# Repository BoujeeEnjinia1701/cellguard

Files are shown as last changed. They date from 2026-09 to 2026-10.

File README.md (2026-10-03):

# CellGuard

     

**Area:** Shared Components · **TRL:** 3 of 9 (proof of concept on paper) · **Value-engineering target:** about $140 USD (a hypothetical control target, not a limit) · **Difficulty:** 4 of 5

An open battery management board for small LiFePO4 packs (4 to 16 cells) with cell balancing, protection and a documented state-of-charge estimate, reusable across the lab's vehicles, storage and field kits.

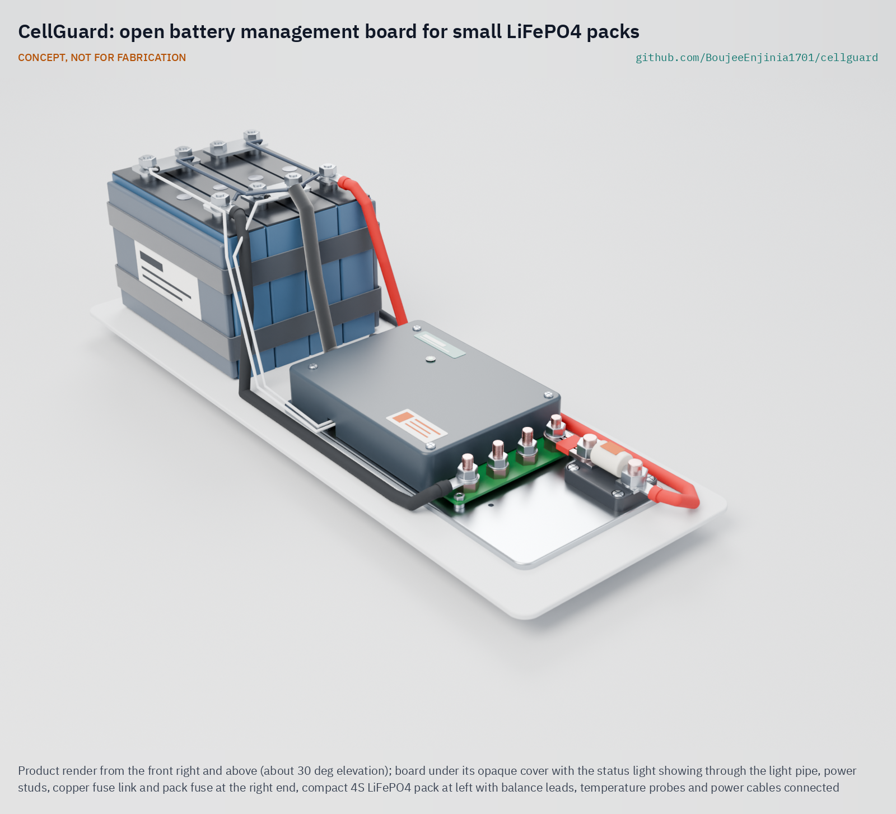
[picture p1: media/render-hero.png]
CellGuard: open battery management board for small LiFePO4 packs, product render


[Exploded render](media/render-exploded.png) · [Detail render](media/render-detail.png) · [Interactive 3D model](media/viewer.html) · [Concept blueprint (PDF)](media/concept-blueprint.pdf) · [General arrangement CGD-DWG-001 (PDF)](cad/drawings/CGD-DWG-001.pdf) · [Sizing calculations](docs/04-calcs/01-sizing.md) · [Prototype build plan](docs/05-build-plan.md) · [Design decisions](docs/06-design-decisions.md) · [Review note](docs/REVIEW.md)

## Concept rationale

A single, openly documented BMS removes the riskiest unknown from every battery project in the lab and gives SwapCell, PowerBox, SunSpoke and MotionCore a common safety layer. The concept puts protection in one proven cell-monitor chip that trips the pack's switches on its own, backs it with an independent secondary protector, and keeps the microcontroller for the parts that users need to read and check: the state-of-charge estimate, the event log and the CAN interface. Switches, sensing, precharge and the pack fuse sit on one aluminium plate, so the whole protection path can be built and tested as one part.

It is open and garage-buildable because the value of a BMS lies in knowing exactly what it does. Every threshold sits in a plain configuration file, the firmware and state-of-charge method are published, and the parts can be soldered with a hot plate or hot-air station. A repairer can read a fault log instead of scrapping a pack, and a builder can test the board on a bench before trusting it with cells.

## Burning platform

Lithium battery fires in light vehicles and homes are rising, and the battery management system is the main barrier between a cell fault and a fire. In the United States, the Consumer Product Safety Commission counts 227 micromobility battery incidents from 2019 to 2023, associated with 39 deaths and 181 injuries, and in 2026 proposed a mandatory safety standard in which BMS protections are central ([Federal Register, 24 June 2026](https://www.federalregister.gov/documents/2026/06/24/2026-12749/safety-standard-for-lithium-ion-batteries-used-in-micromobility-products-and-electrical-systems-of)). New York City alone recorded 268 lithium-ion battery fires and 18 deaths in 2023 ([FDNY](https://www.nyc.gov/site/fdny/news/03-25/fdny-commissioner-robert-s-tucker-significant-progress-the-battle-against-lithium-ion)), and London Fire Brigade attended a record 206 e-bike and e-scooter fires in 2025 ([London Fire Brigade](https://www.london-fire.gov.uk/news/2026-news/january/record-number-of-e-bike-and-e-scooter-fires-across-london-in-2025-as-brigade-calls-for-regulation-to-be-introdu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)).

At the same time, more people depend on small lithium packs for basic power: solar home systems made up more than a third of new electricity connections in sub-Saharan Africa in 2023 ([IEA](https://www.iea.org/commentaries/electricity-access-continues-to-improve-in-2024-after-first-global-setback-in-decades)). Builders and repairers of these packs cannot inspect or fix closed battery management boards, so faults stay hidden until a pack fails.

## Where it could be used

### By industry

| Industry | Use |
| --- | --- |
| Light electric vehicles | Protection and state of charge for e-bike, cargo trike and scooter packs, including the lab's SwapCell and SunSpoke |
| Off-grid and backup power | 12, 24 and 48 V LFP banks for solar home systems, shops and clinics, and portable stations such as PowerBox |
| Telecom and remote monitoring | Battery backup for small towers, gateways and monitoring stations |
| Marine and recreational vehicles | LFP house batteries replacing lead-acid in boats, vans and caravans |
| Light robotics and agriculture | Packs for field robots, carts and automated guided vehicles built on MotionCore |
| Education and repair | Teaching battery safety in vocational courses; diagnosing packs in repair shops and repair cafés |

### By country or region

| Country or region | Why it matters there |
| --- | --- |
| United Kingdom | London had a record 206 e-bike and e-scooter fires in 2025, and the fire brigade is calling for regulation ([London Fire Brigade](https://www.london-fire.gov.uk/news/2026-news/january/record-number-of-e-bike-and-e-scooter-fires-across-london-in-2025-as-brigade-calls-for-regulation-to-be-introdu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)) |
| United States | 268 lithium-ion battery fires and 18 deaths in New York City in 2023 ([FDNY](https://www.nyc.gov/site/fdny/news/03-25/fdny-commissioner-robert-s-tucker-significant-progress-the-battle-against-lithium-ion)); a federal micromobility battery standard is proposed ([Federal Register](https://www.federalregister.gov/documents/2026/06/24/2026-12749/safety-standard-for-lithium-ion-batteries-used-in-micromobility-products-and-electrical-systems-of)) |
| European Union | Since 18 August 2024, batteries for light vehicles, stationary storage and electric vehicles must hold state-of-health data in their BMS ([Regulation (EU) 2023/1542](https://eur-lex.europa.eu/eli/reg/2023/1542/oj/eng)) |
| Australia | Fire and Rescue NSW recorded 272 lithium-ion battery fires and 38 injuries in 2023 ([FRNSW](https://www.fire.nsw.gov.au/media/news/2024/20240315-fire-and-rescue-nsw-recording-lithium-ion-battery-fires-at-a-rate-of-five-a-week)) |
| India | Fires in electric two-wheelers led to added battery safety requirements, including the BMS, from 1 October 2022 ([Press Information Bureau](https://www.pib.gov.in/PressReleaseIframePage.aspx?PRID=1856114&reg=3&lang=2)); many small workshops assemble and repair packs |
| Sub-Saharan Africa | About 600 million people lacked electricity in 2023, and solar home systems made up more than a third of new connections ([IEA](https://www.iea.org/commentaries/electricity-access-continues-to-improve-in-2024-after-first-global-setback-in-decades)); local technicians need BMS boards they can repair |

## What sparked the idea

The starting point was the self-balancing scooter, or hoverboard, recall of July 2016. The US Consumer Product Safety Commission and ten firms recalled about 501,000 units because their lithium-ion battery packs could overheat, smoke, catch fire or explode, after at least 99 reported incidents that included burn injuries and property damage ([CPSC recall notice, 6 July 2016](https://www.cpsc.gov/Recalls/2016/Self-Balancing-Scooters-Hoverboards-Recalled-by-10-Firms)). The recall spanned products from ten firms, and nothing published let a buyer or repairer see what limits a pack's protection electronics enforced or how they would fail. CellGuard takes the opposite position for the small LFP packs that builders assemble themselves: publish every threshold, the failure analysis and the state-of-charge method, and back the main protection with an independent second layer, so that the protection can be checked before a pack is trusted rather than after it fails.

## Problem

Small builders either buy closed battery management boards with unknown firmware and limits, or skip protection altogether. Both lead to damaged packs and fires, and neither teaches anything.

Full problem statement: [docs/01-problem.md](docs/01-problem.md)

## Concept

An open battery management board for small LiFePO4 packs (4 to 16 cells) with cell balancing, protection and a documented state-of-charge estimate, reusable across the lab's vehicles, storage and field kits.

A single cell-monitor and protection chip measures every cell and opens the charge or discharge MOSFETs on its own when a limit is crossed; an independent secondary protector blows a protector fuse if that layer fails. A microcontroller adds a state-of-charge estimate anchored at full and empty, a state-of-health event log and an open CAN and UART interface carrying the SwapCell message set. Calculated at TRL 3 (CGD-CAL-001 v0.6): 40 A continuous with MOSFET junctions near 51 °C at 40 °C ambient, 3.5 W board loss at 40 A with 1.5 mΩ-class switches (against a 4 W target), 100 mA passive balancing, about 55 µA sleep current, 220 x 110 x 33 mm and about 0.66 kg (against 0.7 kg). The state-of-charge error stays within 10 points on a 20 Ah pack because the firmware prompts for a full charge when about five days pass without one, provided the coulomb counter offset is calibrated. A three-colour status light shows through a light pipe in the opaque printed cover. Value-engineering target: USD 140. Estimated cost of the constructable design: USD 159.15 (USD 19.15 over the target), mainly the lower-resistance switches.

Full design precis: [docs/02-concept.md](docs/02-concept.md) · Requirements: [docs/03-requirements.md](docs/03-requirements.md)

## Key components

- Cell monitor and protection IC for 3 to 16 cells, with passive balancing (TI BQ76952 class)
- Independent secondary protector (TI BQ77216 class) with a self-control protector fuse
- Charge and discharge MOSFET switches: 8 x 100 V, high side, top-side cooled, on an aluminium heat spreader
- 0.25 mΩ current shunt
- Temperature sensors, 3 points
- Microcontroller with CAN and UART (STM32G0B1 class)
- Fuse and precharge circuit
- Enclosure and harness

The component choices were decided by Amish on 2026-09-25 ([CGD-DDR-001](docs/decisions/0001-trl2-review-decisions.md), [CGD-DDR-002](docs/decisions/0002-recommendations-accepted.md)). The priced bill of materials is in [bom/bom.csv](bom/bom.csv): value-engineering target USD 140; estimated cost of the constructable design USD 159.15 (USD 19.15 over the target).

## Building the prototype

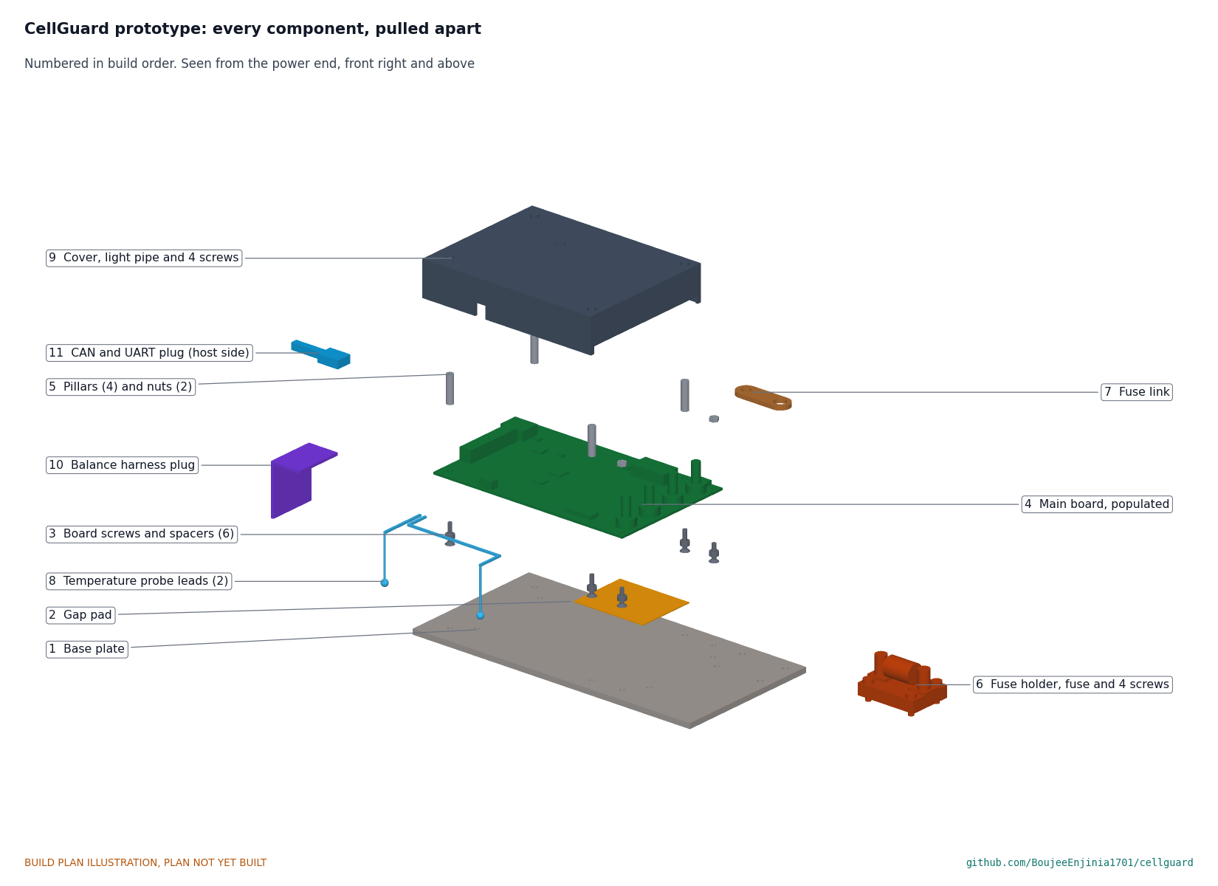
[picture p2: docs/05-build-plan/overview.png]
Every component of the prototype, pulled apart and numbered in build order


The [prototype build plan](docs/05-build-plan.md) (CGD-BLD-001) shows, in pictures drawn from the model, how each of the 11 components is made and how it fits the next: a drilled and tapped aluminium plate, a cut gap pad, a populated four-layer board on six spacers, a bolted fuse holder joined to the B+ stud by a straight copper link, and a printed opaque cover on four pillars with a light pipe over the status light. Making the design buildable changed some concept details, such as the board fixings, the cover notches and the fuse position; each change is recorded in [CGD-DDR-003](docs/decisions/0003-design-for-construction.md). It is a plan, not yet built: first power-up is always on a cell simulator. Decisions are kept in the [design decisions register](docs/06-design-decisions.md).

## Safety

> Lithium cells can overheat, vent and burn, and a large pack can deliver thousands of amperes into a short circuit. Use LFP cells, fit a DC-rated pack fuse sized for the pack, charge only within the cell maker's limits and never leave a first build charging unattended. A 16S pack of large cells can drive about 5 kA into a short (CGD-CAL-001), so the pack fuse needs a 10 kA DC breaking capacity. Test every new board and every threshold change on a cell simulator or current-limited bench supply before connecting cells. CellGuard is a research and prototype design; it is not certified.

## Repository layout

| Folder | Contents |
| --- | --- |
| `docs/` | Problem, concept, requirements, calculations and design decisions |
| `cad/src/` | build123d Python source, the source of truth for all geometry |
| `cad/step/`, `cad/stl/` | Exported models for FreeCAD, other CAD tools and printing |
| `cad/drawings/` | 2D sketches and dimensioned drawings |
| `bom/` | Bill of materials |
| `electronics/` | KiCad schematics and PCB layouts |
| `firmware/` | Microcontroller code |
| `media/` | Renders, perspectives and photos |
| `build-log/` | Dated prototyping notes |

## Documentation

Controlled documents follow the portfolio [documentation standard](.kit/STANDARDS.md). Each carries a document ID (CGD-PRC-001 for the precis), a version and a revision history. Branded PDFs are built with `python .kit/render.py` and attached to GitHub Releases when a document is tagged, for example `CGD-PRC-001/v1.0`.

## Credits

Designed by Amish Chadha. See [CONTRIBUTORS.md](CONTRIBUTORS.md) for roles. To cite this design, use [CITATION.cff](CITATION.cff) (GitHub shows it as "Cite this repository").

AI assistance (Claude) was used to accelerate concept renders, prototype documentation and first-pass sizing calculations. Design direction and all decisions are Amish Chadha's, recorded in this repository's decision records (`docs/decisions/`).

## Licenses

- **Hardware** (CAD, drawings, BOM, electronics): [CERN-OHL-S v2](LICENSE)
- **Software** (firmware, scripts, notebooks): [MIT](LICENSE-SOFTWARE). Any code reused from the Apache-2.0 Libre Solar BMS firmware will keep its own license and notices in `firmware/third_party/` and be listed in `LICENSE-SOFTWARE`.

A project of the [Design Molecule](https://designmolecule.com) lab.

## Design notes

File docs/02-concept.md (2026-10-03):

---
doc_id: CGD-PRC-001
title: CellGuard design precis
project: CellGuard
doc_type: Design precis
version: "0.8"
status: Draft
date: '2026-10-02'
author: Amish Chadha
license: CERN-OHL-S-2.0
revisions:
- version: "0.1"
  date: '2026-09-25'
  author: Amish Chadha
  change: Initial scaffold
- version: "0.2"
  date: '2026-09-25'
  author: Amish Chadha
  change: Populate to TRL 2 (architecture, first-order numbers, safety, media)
- version: "0.3"
  date: '2026-09-25'
  author: Amish Chadha
  change: TRL 3. Record design choices adopted for TRL 3 under Amish's 2026-09-25 instruction, open for his review (CGD-DDR-001); add the secondary protector; numbers replaced by CGD-CAL-001; media from the parametric model
- version: "0.4"
  date: '2026-09-25'
  author: Amish Chadha
  change: Recommendations accepted by Amish (DDR-002)
- version: "0.5"
  date: '2026-09-30'
  author: Amish Chadha
  change: Design for construction (CGD-DDR-003); figures follow CGD-CAL-001 v0.3; base plate, fuse holder and cover fixings made buildable; GA Rev P2
- version: "0.6"
  date: '2026-10-01'
  author: Amish Chadha
  change: Budget treated as a value-engineering target; cost wording only, no number changed
- version: "0.7"
  date: '2026-10-02'
  author: Amish Chadha
  change: "Responses to R6, R8 and R14, cover, status light, state-of-charge check and first test partner as decided on 2026-10-02 (CGD-DEC-001)"
- version: "0.8"
  date: '2026-10-02'
  author: Amish Chadha
  change: "Key numbers from CGD-CAL-001 v0.6 (1.5 mOhm-class switches, five-day state-of-charge error); status light and light pipe in the components table; cost USD 159.15 against the USD 140 value-engineering target"
---

# CellGuard design precis

## Summary

CellGuard is one open battery management board for LFP packs of 4 to 16 cells in series. A single cell-monitor and protection chip measures every cell, trips the pack's MOSFET switches on its own when a limit is crossed, and balances the cells; a small microcontroller adds the state-of-charge estimate, a state-of-health log and an open CAN and UART interface. An independent secondary protector blows a self-control protector (SCP) fuse if the main protection fails. Everything sits on an aluminium base plate that spreads heat and also carries the pack fuse, so the whole protection path is one part that other lab projects can bolt on. The TRL 3 calculations (CGD-CAL-001 v0.6) show 12 of 16 requirements met on paper after the responses Amish decided on 2026-10-02: board loss 3.5 W against 4 W with 1.5 mΩ-class switches (R6), state of charge within 10 points between full charges prompted about every five days (R8, with calibration) and mass 0.66 kg against the relaxed 0.7 kg (R14). R2, R4 and R7 are at risk. Value-engineering target: USD 140. Estimated cost of the constructable design: USD 159.15 (USD 19.15 over the target), mainly the dearer switches (R16).

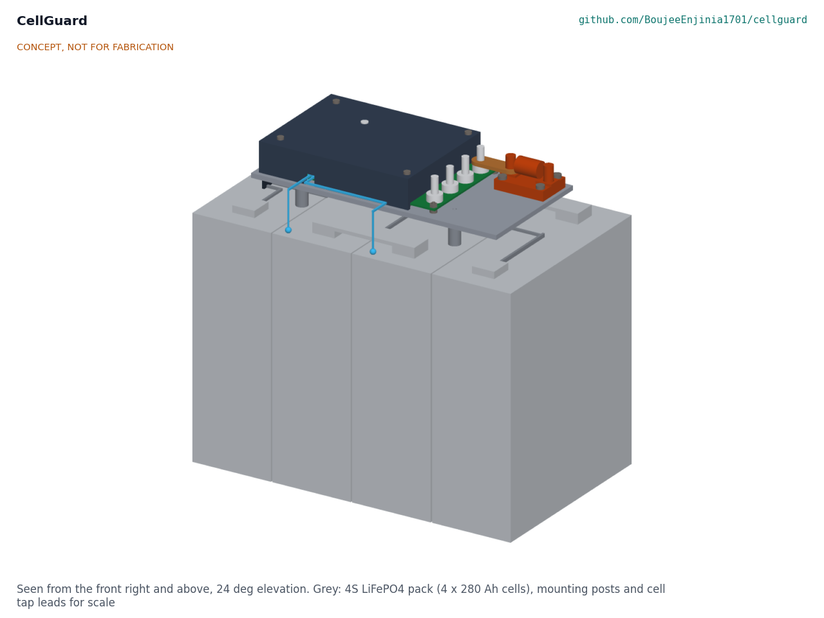
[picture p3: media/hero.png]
CellGuard on a 4S LFP pack


*Figure 1. CellGuard on four posts above a 4S LFP pack of 280 Ah prismatic cells, shown for scale. Generated from `cad/src/model.py`. Concept, not for fabrication.*

## How it works

1. **Measure.** The front end (BOM 3) reads every cell voltage through the balance harness (10), pack current through a 0.25 mΩ shunt (5) and three temperatures (11): two cell probes and one thermistor beside the MOSFETs.
2. **Protect.** The front end compares each reading with thresholds loaded from the configuration file at startup. If a cell goes above 3.65 V it opens the charge MOSFETs; below 2.50 V it opens the discharge MOSFETs; on overcurrent, short circuit or temperature faults it opens both (4). This happens in the front end's own hardware, so a firmware crash in the microcontroller does not stop protection. A separate secondary protector (14) watches every cell as well and, if the front end or a MOSFET fails, blows the SCP fuse in the B+ path.
3. **Balance.** When the pack is near full and cells differ by more than a set amount (default 10 mV), the front end bleeds up to 100 mA from the higher cells through external balance resistors.
4. **Connect safely.** The discharge path stays off until the host pulls the enable line. The precharge switch and resistor (7) first charge the host's input capacitors, then the main discharge MOSFETs close. The pack fuse (8) is the last line of defense against a short circuit that the MOSFETs cannot clear.
5. **Estimate and report.** The microcontroller (6) counts charge in and out, corrects the count at full charge and near empty, logs every charge and discharge event to flash and publishes status on CAN and UART (12).

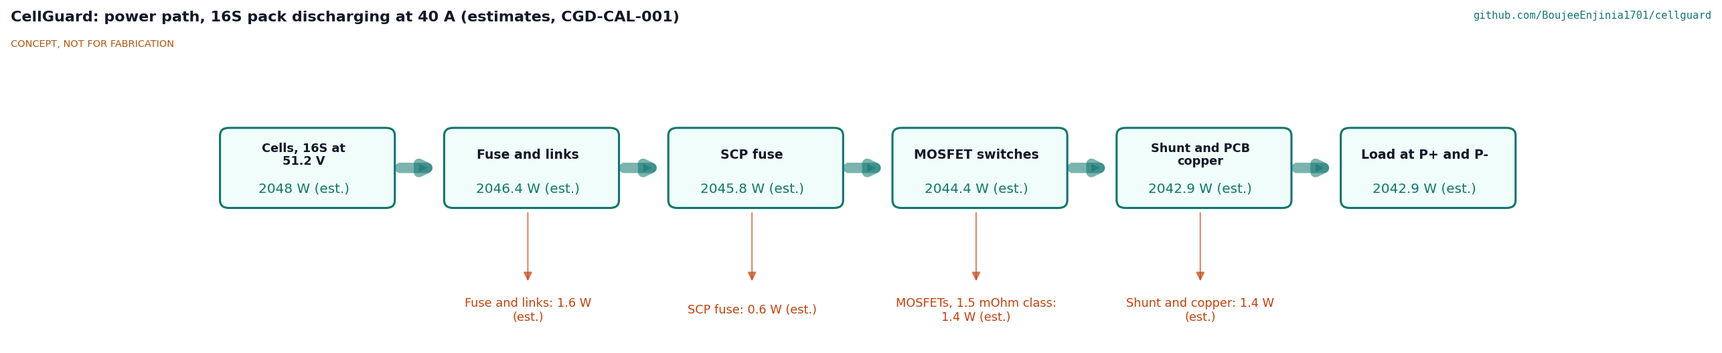
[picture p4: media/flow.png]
Power path and losses


*Figure 2. Power path for a 16S pack discharging at 40 A. All values are estimates from CGD-CAL-001.*

## Main components

Table 1. Main components. Numbers match the exploded view (Figure 3) and `bom/bom.csv`.

| BOM | Component | Concept choice | Notes |
| --- | --- | --- | --- |
| 1 | Base plate and heat spreader | 6061 aluminium, 220 x 110 x 4 mm, flat, drilled and tapped; the board sits on six bought 3 mm spacers (CGD-DDR-003) | Takes MOSFET heat through a gap pad; carries the fuse |
| 2 | Main PCB | 4-layer, 2 oz (70 µm) copper, 150 x 95 mm | Power copper on inner layers; clearances for 60 V |
| 3 | Cell monitor and protection IC | TI [BQ76952](https://www.ti.com/product/BQ76952): 3 to 16 cells, ±15 mV total cell voltage error from −40 to 85 °C, integrated high-side N-channel MOSFET driver, coulomb counter, I²C | Decided by Amish, 2026-09-25 (CGD-DDR-001 item 1, CGD-DDR-002) |
| 4 | Charge and discharge MOSFETs | 8 x 100 V N-channel, 1.5 mΩ class (decided 2026-10-02, CGD-DEC-001), top-side cooled (TOLT) package (decided, CGD-DDR-002): 4 in parallel for charge, 4 for discharge, back to back | Mounted on the PCB underside, pressed onto the base plate through an insulating pad |
| 5 | Current shunt | 0.25 mΩ metal element, 3 W, low side between B- and P- | 10 mV at 40 A |
| 6 | Microcontroller and CAN transceiver | STM32G0B1 class with built-in CAN controller, plus a 3.3 V CAN transceiver | Runs state of charge, log and interface; not in the protection path. Decided by Amish, 2026-09-25 (item 2) |
| 7 | Precharge | 100 Ω 10 W aluminium-housed resistor with a DPAK-class P-channel MOSFET, driven by the front end's precharge output | 1 s timeout in firmware; DPAK-class switch sized for a 34 W peak (decided, CGD-DDR-002) |
| 8 | Pack fuse and holder | 60 A, DC rated 80 V or more, breaking capacity 10 kA or more | In the B+ lead, bolted to the base plate |
| 9 | Power terminals | Four M6 studs: B+, B-, P+, P- | Pack side (B) and load or charger side (P) |
| 10 | Balance connector and harness | 17-way connector, 16 sense leads plus B- reference, each lead fused or resistor-protected at the cell end | Unused inputs linked on the board for packs under 16S |
| 11 | Temperature sensors | Three 10 kΩ NTC thermistors: two ring-lug probes on cells, one on the board by the MOSFETs | Charge locked out below 0 °C |
| 12 | CAN and UART connector | Latching 6-way connector: CAN-H, CAN-L, UART TX and RX, enable, ground | Enable keeps the output off until the host is connected |
| 13 | Cover | Flame-retardant polycarbonate (UL 94 V-0 grade), printed, opaque (decided 2026-10-02) | Leaves the studs and fuse reachable; a light pipe (line 19) shows the status light |
| 14 | Secondary protector and SCP fuse | TI [BQ77216](https://www.ti.com/product/BQ77216) class: 3 to 16 cells, overvoltage, undervoltage, open wire and temperature, separate COUT and DOUT outputs, about 1 µA; drives a self-control protector fuse in the B+ path | Decided by Amish, 2026-09-25 (item 3); SCP rating at 40 A and 60 V to be confirmed |
| 15 | Supporting electronics | 60 V input buck regulator, 16 Mbit SPI flash, TVS diode across P+ and P-, balance resistors, passives, and one three-colour status light (decided 2026-10-02) | Only the status light is shown in the model |
| 19 | Light pipe | Round flanged light pipe, 3 mm, pressed into the cover top over the status light (decided 2026-10-02) | Lets the opaque cover show the status light |

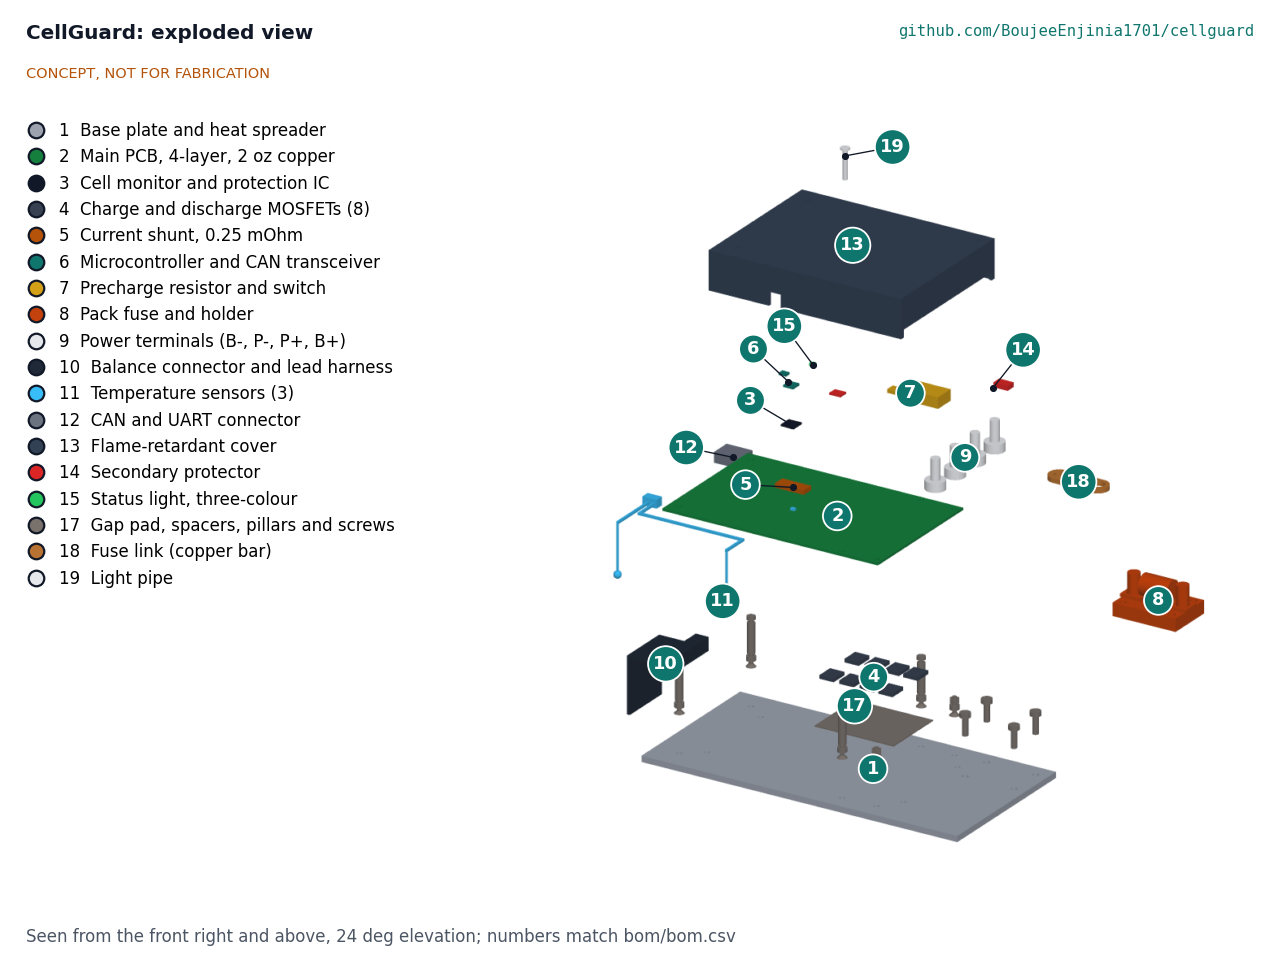
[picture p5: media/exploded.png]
Exploded view


*Figure 3. Exploded view with BOM numbers.*

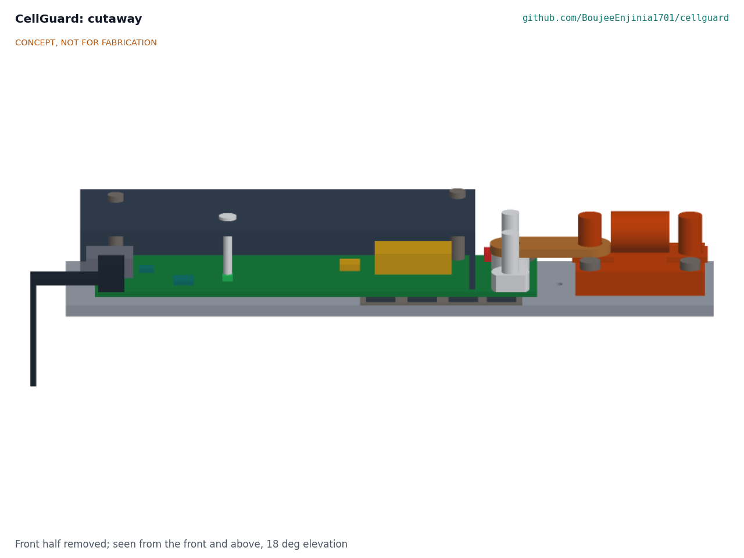
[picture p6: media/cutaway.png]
Cutaway


*Figure 4. Section through the board: MOSFETs (4) under the PCB on the base plate (1), precharge resistor (7), studs (9) and fuse (8), all under or beside the cover (13).*

The general arrangement is drawing CGD-DWG-001 Rev P2 (`cad/drawings/CGD-DWG-001.pdf`), and the STEP files are in `cad/step/`.

## Key design choices

The choices below were recommended at TRL 2 and are decided by Amish, 2026-09-25: go with recommendation (CGD-DDR-001 as updated, CGD-DDR-002). This includes the licensing rule in choice 3 and the protection settings, top-side cooled MOSFETs, DPAK-class precharge switch and one-point current calibration from CGD-CAL-001.

1. **One analog front end for 4 to 16 cells.** A single BQ76952-class chip covers the whole cell range on one board and runs protection without the microcontroller. Alternatives: an Analog Devices ADBMS or LTC681x daisy-chain monitor (better for large packs, but needs a separate protection path and more firmware), or a Renesas ISL94202 as on the Libre Solar board (autonomous, but limited to 8 cells). Decided: BQ76952 class.
2. **High-side switching.** N-channel MOSFETs in the positive lead keep B- and P- at nearly the same potential, so the CAN and UART ground stays common with the host. Low-side switching is cheaper but breaks the common ground whenever the pack trips. Decided: high side.
3. **Microcontroller and firmware base.** Option A: STM32G0B1 class with built-in CAN, building on the open [Libre Solar BMS firmware](https://github.com/LibreSolar/bms-firmware) (Apache-2.0, supports bq769x2 front ends). Option B: ESP32-C6 class with Wi-Fi and Bluetooth for a phone app, at higher idle current. Option C: a new firmware from scratch. Decided: A. Reused Apache-2.0 files keep their license and notices in a separate folder, `firmware/third_party/`, and are listed in `LICENSE-SOFTWARE`; CellGuard's own code stays MIT. No firmware exists yet: writing it is TRL 4 work, on hold.
4. **40 A continuous rating.** Covers a 30 A vehicle controller and a 400 W inverter on a 12.8 V pack. A 100 A variant would need more MOSFETs, heavier copper and a larger plate. Decided: 40 A for the first board.
5. **Passive balancing at 100 mA.** Simple and cheap; adequate for packs up to about 100 Ah. Active balancing is out of scope.
6. **Independent secondary protector.** A BQ77216-class protector and SCP fuse close the single-fault gap (R4) for about $10, at the cost of about 0.6 W in the power path. Decided.
7. **Fuse on the base plate.** Keeps the fuse, switches and sensing together as one tested assembly, at the cost of a longer plate. Kept.
8. **CAN message set.** CellGuard carries the SwapCell interface v0.3 message set (250 kbit/s) as a profile, so SwapCell hosts such as PowerBox and SunSpoke can read a CellGuard pack without changes. Decided, subject to the SwapCell project agreeing (cross-repo action).
9. **Chemistry scope.** Hardware for LFP and for an NMC profile up to 14 cells (under 60 V), so CellGuard could serve as SwapCell's 13S BMS; LFP firmware first. Decided, subject to the SwapCell project (cross-repo action). An NMC build needs the NMC threshold option of the secondary protector and SwapCell's INTERLOCK wake input.

## Key numbers

These values come from CGD-CAL-001, which states every assumption; they are calculations, not measurements.

Table 2. Key numbers at TRL 3.

| Quantity | Value | Requirement |
| --- | --- | --- |
| Board loss at 40 A, 1.5 mΩ-class switches (MOSFETs 1.41 W, shunt 0.40 W, copper 1.02 W, SCP fuse 0.64 W) | 3.47 W | R6, 4 W: met (was 4.4 W with 2.5 mΩ parts) |
| External fuse and links at 40 A | 1.60 W | |
| Power path efficiency, 16S at 40 A | 99.75 % | |
| Plate temperature rise at 40 A | 10.4 K | |
| MOSFET junction at 40 A and 40 °C ambient | 51.0 °C (TOLT), 55.4 °C (TOLL) | R5, 110 °C: met |
| MOSFET junction bound, 80 A for 10 s | 54.4 °C (TOLT), 77.6 °C (TOLL) | R5: met |
| Protection settings (decided, CGD-DDR-002) | SCD 400 A in 15 µs, OCD2 160 A in 20 ms, OCD1 96 A in 320 ms, OCC 48 A | R3: met on paper |
| Prospective short-circuit current | 716 A (4S 20 Ah) to 4,976 A (16S 280 Ah) | Fuse breaking capacity 10 kA |
| Balancing | 103 mA, 0.350 W per channel; 1 % on 100 Ah in 9.7 h, on 280 Ah in 27.2 h | R7: at risk (resistor hotspot 73.9 °C) |
| State-of-charge error after five days between prompted full charges | 8.7 points (20 Ah), 6.7 points (100 Ah), with a calibrated coulomb counter offset | R8, 10 points between prompted full charges: met with calibration (24.5 points on 20 Ah uncalibrated) |
| Current error at 80 A after one-point calibration | 0.404 A | R9, 0.850 A: met |
| Sleep and ship-mode current | 54.5 µA and 6.0 µA | R10: met |
| CAN bus load, 250 kbit/s | 1.84 % | R11: met |
| Log capacity | 65,536 records of 32 bytes | R12: met |
| Precharge of 2 mF to 90 % | 0.46 s, 3.38 J, 34.1 W peak | R13: met |
| Size and mass | 220 x 110 x 33 mm; 0.664 kg | R14, 0.7 kg (relaxed 2026-10-02): met |
| Parts cost | $159.15 estimated (113.7 % of the $140 value-engineering target) | R16: over the value-engineering target by $19.15 |

### State-of-charge method

LFP's flat voltage curve means voltage alone cannot give state of charge in the middle of the range. The concept uses coulomb counting from the front end's integrated coulomb counter, anchored at two points where LFP voltage does change quickly: full (all cells above 3.45 V with charge current tapering below C/20) and near empty (lowest cell below 3.0 V at light load). Between two anchors the firmware learns the usable capacity, which also feeds the state-of-health log. After a rest of two hours or more at the ends of the range, the open-circuit voltage is used as a check. The first error budget is in CGD-CAL-001 section 6: the coulomb counter's offset sets the drift, so on a 20 Ah pack the offset must stay under about 1.5 µV across the shunt (about 6 mA) to hold 10 points over the five days after which the firmware prompts for a full charge (decided 2026-10-02).

## Safety

> **Safety:** CellGuard connects directly to lithium cells that can deliver thousands of amperes into a short circuit. Treat every build as live. Use insulated tools, cover exposed terminals and busbars, and fit the pack fuse before connecting any load.

> **Safety:** Connect the balance harness only in the order given by the front-end maker, with the board not yet connected to the power leads, and check every sense lead voltage with a meter first. A wrong or loose sense lead can make the board report a false cell voltage, which can lead to overcharge.

> **Safety:** First power-up and all threshold changes should be tested on a cell simulator or a bench supply with current limiting, not on a full pack. Charge test packs on a non-combustible surface, inside a fire-resistant enclosure where possible, never unattended, with a lithium-rated or Class D extinguisher and sand nearby.

> **Safety:** The MOSFETs cannot always interrupt a hard short from a large pack; the fuse must be sized for the pack's prospective short-circuit current (about 5.0 kA for a 16S 280 Ah pack by CGD-CAL-001; specify a 10 kA breaking capacity) and rated for DC at 80 V or more. Set the short-circuit delay to its 15 µs minimum: at 60 µs the current in a large pack reaches about 2.5 kA before the MOSFETs open. A TVS diode across P+ and P- limits the voltage spike when the MOSFETs open under load.

> **Safety:** The secondary protector blows the SCP fuse if a MOSFET shorts or the front end fails. Until an SCP fuse rated for 40 A at 60 V DC is confirmed (R4 at risk), use only chargers with a fixed, correct end-of-charge voltage for the pack. A blown SCP fuse means a fault: inspect the board before repairing it.

> **Safety:** The precharge resistor would overheat if the load stayed shorted; firmware limits precharge to 1 s and reports a fault.

Maximum pack voltage stays below 60 V DC. CellGuard is a research, educational and prototype design. It is not certified and does not replace a certified BMS where a product must meet a standard.

## Open questions

- [x] Licensing of reused Apache-2.0 firmware: separate `firmware/third_party/` folder with original notices, listed in `LICENSE-SOFTWARE`. Decided by Amish, 2026-09-25: go with recommendation.
- [x] Value-engineering target: `budget_usd` (a hypothetical control target, not a limit) raised from $120 to $140. Decided by Amish, 2026-09-25: go with recommendation.
- [x] Responses to R6, R8 and R14: 1.5 mΩ-class switches in the TOLT package (3.47 W, CGD-CAL-001 v0.6); a firmware prompt for a full charge when about five days pass without one, with R8 restated to apply between prompted full charges; R14 relaxed to 0.7 kg with the 4 mm plate kept. Decided by Amish, 2026-10-02 (CGD-DEC-001).
- [ ] SwapCell project's agreement to the NMC profile and the message set profile: to be recorded in the SwapCell repo once the board envelope question is settled (SwapCell expects about 230 x 58 x 10 mm; CellGuard is 220 x 110 x 33 mm). Decided by Amish, 2026-10-02 (CGD-DEC-001).
- [x] Cover: printed flame-retardant polycarbonate, not sheet aluminium; opaque for the prototype, with a light pipe over a three-colour status light. Decided by Amish, 2026-10-02 (CGD-DEC-001).
- [x] State-of-charge check: cycle a 4S 20 Ah LFP pack through seven days of partial cycles with a bench supply and a low-cost DC electronic load, count charge with a calibrated reference shunt and meter, then discharge fully to measure the true state of charge. Decided by Amish, 2026-10-02 (CGD-DEC-001).
- [ ] First test partner: a small off-grid solar installer that builds 16S LFP packs, testing on their bench, is the first candidate to approach. Decided by Amish, 2026-10-02 (CGD-DEC-001).

Concept media: [blueprint sheet](../media/concept-blueprint.pdf), [interactive 3D model](../media/viewer.html).

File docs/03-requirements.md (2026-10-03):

---
doc_id: CGD-REQ-001
title: CellGuard requirements
project: CellGuard
doc_type: Requirements
version: "0.8"
status: Draft
date: '2026-10-02'
author: Amish Chadha
license: CERN-OHL-S-2.0
revisions:
- version: "0.1"
  date: '2026-09-25'
  author: Amish Chadha
  change: Initial scaffold
- version: "0.2"
  date: '2026-09-25'
  author: Amish Chadha
  change: First measurable requirements for TRL 2
- version: "0.3"
  date: '2026-09-25'
  author: Amish Chadha
  change: TRL 3. R1 adds the NMC profile and R11 the SwapCell v0.3 message set (CGD-DDR-001 items 7 and 8, adopted for TRL 3 pending Amish's review); status from CGD-CAL-001
- version: "0.4"
  date: '2026-09-25'
  author: Amish Chadha
  change: Recommendations accepted by Amish (DDR-002)
- version: "0.5"
  date: '2026-09-30'
  author: Amish Chadha
  change: Design for construction (CGD-DDR-003); figures follow CGD-CAL-001 v0.3; no requirement changed status
- version: "0.6"
  date: '2026-10-01'
  author: Amish Chadha
  change: Budget treated as a value-engineering target; cost wording only, no number changed
- version: "0.7"
  date: '2026-10-02'
  author: Amish Chadha
  change: "R8 restated and R14 relaxed to 0.7 kg; R6, R8 and R14 status after the 2026-10-02 decisions (CGD-DEC-001)"
- version: "0.8"
  date: '2026-10-02'
  author: Amish Chadha
  change: "Status from CGD-CAL-001 v0.6, re-run for the decided responses: R6 and R8 now met on paper; R16 over the value-engineering target by USD 19.15"
---

# CellGuard requirements

These are first-pass requirements for the concept. Targets are proposals for review, not user-validated needs, and will be revised after the lab projects that depend on CellGuard confirm their needs. Status in Table 2 is judged against the TRL 3 calculations in CGD-CAL-001. On paper, 12 of 16 are met; R2, R4 and R7 are at risk, and the estimated cost is over the R16 value-engineering target. On 2026-10-02 Amish decided the responses to R6, R8 and R14 (CGD-DEC-001): R8 and R14 are restated below, and CGD-CAL-001 v0.6 is re-run for them, so R6 and R8 are now met on paper. Changes in v0.3 follow CGD-DDR-001. In v0.4, R16 follows the $140 budget that Amish set on 2026-09-25, when he accepted the recommendations (CGD-DDR-002); R3 cites the decided protection settings and R9 the decided one-point calibration.

Table 1. Requirements.

| ID | Requirement | Target | Verification (TRL 3 or later) |
| --- | --- | --- | --- |
| R1 | Cover the lab's LFP packs with one board | 4 to 16 LFP cells in series (12.8 to 51.2 V nominal, 58.4 V maximum), cell count set in a configuration file. The hardware also supports an NMC profile up to 14 cells (under 60 V), covering SwapCell's 13S pack; LFP firmware is released first | Design review against the front-end data sheet |
| R2 | Measure every cell voltage accurately | ±10 mV at 25 °C and ±15 mV from −20 to 60 °C, each cell at least every 100 ms | Data sheet review; later comparison with a calibrated meter |
| R3 | Protect the pack from abuse | Cell overvoltage (default 3.65 V), cell undervoltage (default 2.50 V), charge overcurrent, discharge overcurrent, short-circuit trip within 500 µs, over-temperature, charge lockout below 0 °C; all thresholds in the configuration file; default settings as decided in CGD-CAL-001 Table 2 (SCD 100 mV at 15 µs, OCD2 40 mV at 20 ms, OCD1 24 mV at 320 ms, OCC 12 mV) | Protection table review; later fault injection on a cell simulator |
| R4 | Stay safe after a single fault | No single failure (microcontroller crash, stuck-on MOSFET, open sense wire, failed sensor) leaves the pack able to be overcharged or over-discharged | Failure mode and effects analysis |
| R5 | Carry the lab's load currents | 40 A continuous and 80 A for 10 s at 40 °C ambient, MOSFET junction at 110 °C or less | Thermal calculation; later bench test |
| R6 | Waste little power in the power path | 4 W or less on the board at 40 A (MOSFETs, shunt and copper), excluding the external fuse | Loss calculation from data sheets |
| R7 | Balance cells | Passive balancing at 100 mA or more per cell; corrects a 1 % capacity imbalance in 24 h of balancing time on packs up to 100 Ah; board stays at 70 °C or less while balancing | Balance power and time calculation |
| R8 | Give a state of charge the user can trust | Documented method; error within ±5 percentage points after a full charge, and within ±10 points during partial cycling between prompted full charges: the firmware prompts for a full charge when about five days pass without one (restated 2026-10-02, CGD-DEC-001) | Algorithm note; later cycling test against a lab reference |
| R9 | Measure current | ±1 % of reading ±50 mA from −80 to +80 A, with a one-point gain calibration at build | Shunt and front-end error budget |
| R10 | Draw little from an idle pack | 300 µA or less in sleep with outputs on and CAN able to wake; 10 µA or less in ship mode | Quiescent current budget from data sheets |
| R11 | Talk to host devices openly | CAN 2.0B at 250 kbit/s carrying the SwapCell interface v0.3 message set as a CellGuard profile (subject to the SwapCell project); 3.3 V UART at 115,200 baud for logs and configuration; an enable input that keeps the output off until the host is connected | Interface specification review |
| R12 | Keep a state-of-health log | At least 2,000 charge and discharge event records in non-volatile memory, exportable as CSV; fields sufficient for EU Batteries Regulation state-of-health data | Log format review |
| R13 | Precharge the load | Charge up to 2 mF of load capacitance to 90 % of pack voltage within 1 s before closing the discharge path | Precharge calculation |
| R14 | Be small and light | 230 x 120 x 40 mm or smaller, 0.7 kg or less without power cables (relaxed from 0.6 kg on 2026-10-02, CGD-DEC-001) | Massing model; later weighing |
| R15 | Be buildable and open | No BGA or leadless parts finer than 0.5 mm pitch; assembly with a hot plate or hot-air station; hardware CERN-OHL-S-2.0, firmware MIT (reused Apache-2.0 files keep their own license in `firmware/third_party/`) | Design review of the parts list |
| R16 | Stay within the value-engineering target | $140 or less in parts at quantity one, excluding cells (a hypothetical control target, not a limit; raised from $120, CGD-DDR-002) | Priced BOM |

Table 2. Status at TRL 3 (CGD-CAL-001; calculations, nothing measured).

| ID | Status | Basis |
| --- | --- | --- |
| R16 | Over the value-engineering target by $19.15 | Value-engineering target: USD 140.00. Estimated cost of the constructable design: USD 159.15 (USD 19.15 over the target), mainly the 1.5 mΩ-class switches decided on 2026-10-02 ($20.00 more than the 2.5 mΩ parts) |
| R2 | At risk | Total error ±15 mV from −40 to 85 °C meets the range target; at 25 °C the data sheet gives only a typical figure under 10 mV |
| R4 | At risk | With the BQ77216-class secondary protector and SCP fuse every single fault in the failure analysis ends safe; an SCP fuse rated for 40 A at 60 V DC is not yet confirmed |
| R7 | At risk | 103 mA; 9.7 h for 1 % on 100 Ah; PCB 56.4 °C but a balance resistor hotspot about 73.9 °C at 40 °C ambient |
| R1 | Met | 12.8 to 58.4 V; 100 V MOSFETs with 1.71 times margin; front end rated 3 to 16 cells |
| R3 | Met on paper | Thresholds inside the front-end ranges; short-circuit trip within 25 µs |
| R5 | Met on paper | Junction 51.0 °C at 40 A (top-cooled package), 77.6 °C bound at 80 A for 10 s (TOLL) |
| R6 | Met on paper (was not met at v0.7) | 3.47 W on the board at 40 A with the 1.5 mΩ-class switches decided on 2026-10-02, of which 0.64 W is the secondary protector's SCP fuse; about 4.4 W with the former 2.5 mΩ parts |
| R8 | Met on paper with calibration (was not met at v0.7) | 5.0 points after a full charge; 8.7 points on 20 Ah after five days between prompted full charges with a calibrated coulomb counter offset (24.5 uncalibrated), 6.7 on 100 Ah. The calibrated offset is TI's typical figure; the 4S 20 Ah check decided on 2026-10-02 tests it |
| R9 | Met on paper with calibration | 0.404 A error at 80 A after a one-point gain calibration, against 0.850 A |
| R10 | Met on estimate | 54.5 µA in sleep, 6.0 µA in ship mode |
| R11 | Met by design | SwapCell v0.3 message set; 1.84 % bus load at 250 kbit/s |
| R12 | Met | 65,536 records of 32 bytes in 2 MiB |
| R13 | Met | 90 % in 0.46 s; 3.38 J |
| R14 | Met on paper | 220 x 110 x 33 mm meets the size; 0.664 kg against the 0.7 kg target relaxed on 2026-10-02 (CGD-DEC-001) |
| R15 | Met by design review | TQFP-48 at 0.5 mm, TSSOP-24 at 0.65 mm, no BGA |

## Assumptions

- LFP cell limits are typical defaults (3.65 V maximum and 2.50 V minimum per cell; charge 0 to 45 °C; discharge −20 to 60 °C). Every build must take its limits from the actual cell data sheet.
- Reference packs: 4S 280 Ah (12.8 V, about 3.6 kWh) for storage and 16S 20 Ah (51.2 V, about 1 kWh) for vehicles.
- The 40 A rating covers a 400 W inverter on a 12.8 V pack (about 31 A) and a 30 A vehicle controller. Larger loads need a larger board or a contactor, which is out of scope.
- Prices are indicative single-unit prices from distributors in September 2026 and will change.
- `budget_usd` in `project.yaml` is the $140 value-engineering target, raised from $120 by Amish on 2026-09-25 (CGD-DDR-002); R16 is reported against the $140 value-engineering target.
- Responses to R6, R8 and R14, decided by Amish on 2026-10-02 (CGD-DEC-001): 1.5 mΩ-class switches for R6; a full-charge prompt after about five days without one, with R8's partial-cycling clause restated to apply between prompted full charges; R14 relaxed to 0.7 kg with the 4 mm plate kept.

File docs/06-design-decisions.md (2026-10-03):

---
doc_id: CGD-DEC-001
title: CellGuard design decisions register
project: CellGuard
doc_type: Design decisions register
version: "0.4"
status: Draft
date: '2026-10-02'
author: Amish Chadha
license: CERN-OHL-S-2.0
revisions:
  - version: "0.1"
    date: '2026-09-30'
    author: Amish Chadha
    change: Register opened with the open decisions from the review note, the decision records and the build plan work
  - version: "0.2"
    date: '2026-10-01'
    author: Amish Chadha
    change: Budget treated as a value-engineering target
  - version: "0.3"
    date: '2026-10-02'
    author: Amish Chadha
    change: "Amish approved the recommendations for open decisions 1 to 12 (CGD-DDR-003 accepted); moved to decisions made; To confirm item 5 and 8 and the value-engineering savings updated"
  - version: "0.4"
    date: '2026-10-02'
    author: Amish Chadha
    change: "Approved follow-ups carried out: switches, status light and light pipe priced; value engineering restated (USD 159.15, USD 19.15 over the target); To confirm items for the switches, status light and light pipe"
---

# CellGuard design decisions register

Every design decision still to be made, and every decision made, in one place. Each decision is argued in full in its decision record under `docs/decisions/`; this register is the index Amish works from. The build plan (`docs/05-build-plan.md`) describes the design as it stands and does not list open decisions.

## Open decisions

None. All open decisions were decided on 2026-10-02.

## To confirm when parts are bought

*Table 2. Items to confirm.*

| # | What to confirm | Why it matters | Source |
| --- | --- | --- | --- |
| 1 | A protector fuse rated for 40 A continuous at 60 V DC or more, and its price | R4 depends on it; the estimate is already over the value-engineering target, and this price could add to it | CGD-CAL-001 section 4; BOM line 14 |
| 2 | The fuse holder: base no larger than 44 x 32 mm, four M4 fixing holes at the drawn positions, M8 terminal studs, and fuse blade faces 12.6 mm above its mounting face | The copper link is flat only if the blade faces and the B+ stud shoulder are at the same height; the plate holes follow the holder | CGD-DDR-003 P5; BOM line 8 |
| 3 | The fuse and holder mass | The mass result keeps the concept figure of 89 g | CGD-CAL-001 v0.3 section 10 |
| 4 | The stud terminals: M6 male stud, 13 mm shoulder 6 mm tall, through-hole pins | The cable lugs and the link clamp on the shoulder; the shoulder height sets the link height | CGD-DDR-003 P6; BOM line 9 |
| 5 | The power switch package height of 2.3 mm (TOLT), in the 1.5 mΩ class decided on 2026-10-02, and its price of about $5.00 each | It sets the gap pad squeeze with 3 mm spacers (a different height needs a different spacer); the price sets most of the cost over the target | CGD-DDR-003 P2; BOM line 4 |
| 6 | The gap pad: squeezes from 1.0 to 0.7 mm at a load the board fixings can apply, and insulates to at least 100 V | It is the only insulation between the live switch tops and the plate | CGD-DDR-003 P2; BOM line 17 |
| 7 | The TVS diode and switch avalanche energy against about 1 J | Short-circuit turn-off energy at a 15 µs delay | CGD-CAL-001 section 4 |
| 8 | A printable flame-retardant polycarbonate filament (the cover is opaque, decided 2026-10-02); a clear cover only if clear polycarbonate sheet with a V-0 rating at the cover's wall thickness can be bought and formed | The cover is drawn for printing | BOM line 13 |
| 9 | The light pipe: 3 mm round, 19.6 mm below a flange about 6 mm across, and the hole it presses into (drawn 3.2 mm); the status light's package (PLCC-4, 3.5 x 2.8 x 1.9 mm) | The pipe's foot is drawn 0.5 mm above the light; a different length or hole needs the cover or pipe changed | BOM lines 13, 15 and 19 |

## Value engineering

Value-engineering target: USD 140.00 (a hypothetical control target, not a limit). Estimated cost of the constructable design: USD 159.15 (USD 19.15 over the target).

Main cost drivers (CGD-CAL-001 v0.6, section 11): the eight 1.5 mΩ-class charge and discharge MOSFETs (line 4, $40.00, of which $20.00 is the step up from the 2.5 mΩ parts decided on 2026-10-02), supporting electronics with the status light (line 15, $16.35), the pack fuse and holder (line 8, $12.00), the aluminium base plate, the main PCB and the secondary protector with its SCP fuse (lines 1, 2 and 14, $10.00 each). The secondary protector and the parts added for construction (lines 17 and 18) account for $14.00 of the estimate; the status light and light pipe for $1.15.

Savings worth trying:

- Ask for a quantity price on the switches: power MOSFETs are usually markedly cheaper at quantity 100 or more, and each $1.00 off the unit price saves $8.00 on the board.
- Confirm the SCP fuse price, which may add to the estimate (CGD-DDR-003, A2).
- The status light stays (decided 2026-10-02) and the cover stays printed flame-retardant polycarbonate (decided 2026-10-02), so neither is a saving to try.

## Decisions made

*Table 3. Decisions made.*

| Date | Decision | Decided by | Record |
| --- | --- | --- | --- |
| 2026-09-25 | BQ76952-class front end; STM32G0B1-class controller building on the Libre Solar BMS firmware; BQ77216-class secondary protector with protector fuse; 40 A rating; high-side switching; LFP and NMC-capable hardware, LFP firmware first; SwapCell v0.3 CAN message set as a profile | Amish: "i accept all your recommendations, go with them across all repos." | [CGD-DDR-001](decisions/0001-trl2-review-decisions.md), [CGD-DDR-002](decisions/0002-recommendations-accepted.md) |
| 2026-09-25 | Budget raised from $120 to $140 | Amish, same instruction | CGD-DDR-002 |
| 2026-09-25 | Reused Apache-2.0 firmware kept in `firmware/third_party/` with its notices and listed in `LICENSE-SOFTWARE` | Amish, same instruction | CGD-DDR-002 |
| 2026-09-25 | Protection settings (SCD 100 mV at 15 µs, OCD2 40 mV at 20 ms, OCD1 24 mV at 320 ms, OCC 12 mV); top-side cooled TOLT switches; DPAK-class precharge switch; one-point current calibration at build | Amish, same instruction | CGD-DDR-002 |
| 2026-09-30 | Design for construction: the changes P1 to P8 that make the board buildable | Made under Amish's 2026-09-30 instruction ("fix the design assumptions to match and be physically feasible"). The changes themselves were accepted on 2026-10-02 (below) | [CGD-DDR-003](decisions/0003-design-for-construction.md) |
| 2026-10-02 | Design for construction accepted: the changes P1 to P8 (flat plate with bought spacers and screws, squeezed gap pad, cover pillars and notches, fixing positions, fuse holder in line with B+ and copper link, stud terminals, mounting holes, connector position), as made | Amish: "i approve your recommendations for all 555 open decisions." | [CGD-DDR-003](decisions/0003-design-for-construction.md), A1 |
| 2026-10-02 | Cover material: printed flame-retardant polycarbonate, as drawn (option a); sheet aluminium is not used, since a metal cover would sit a few millimetres from live 58 V studs and nuts | Amish: "i approve your recommendations for all 555 open decisions." | CGD-DDR-001 item 12; CGD-DDR-002 |
| 2026-10-02 | Cover colour: the prototype cover is opaque, with a light pipe over the status light; a clear cover only if clear polycarbonate sheet with a V-0 rating at the cover's wall thickness can be bought and formed | Amish: "i approve your recommendations for all 555 open decisions." | Review note, 2026-09-26 render session, item 1 |
| 2026-10-02 | R6 board loss: fit 1.5 mΩ-class switches in the TOLT package (option a), bringing the board loss to about 3.5 W; the protector fuse stays on the board | Amish: "i approve your recommendations for all 555 open decisions." | CGD-CAL-001 v0.3 section 12; CGD-DDR-002 |
| 2026-10-02 | R8 state of charge: the firmware prompts for a full charge when about five days pass without one (option b), and R8's partial-cycling clause is restated to apply between prompted full charges; the 0.5 mΩ shunt is not fitted | Amish: "i approve your recommendations for all 555 open decisions." | CGD-CAL-001 v0.3 section 12; CGD-DDR-002 |
| 2026-10-02 | R14 mass: target relaxed to 0.7 kg (option b); the 4 mm plate is kept | Amish: "i approve your recommendations for all 555 open decisions." | CGD-CAL-001 v0.3 section 10; CGD-DDR-002; CGD-DDR-003 |
| 2026-10-02 | State-of-charge check: cycle a 4S 20 Ah LFP pack (the worst case for R8) through seven days of partial cycles with a bench supply and a low-cost DC electronic load, count charge independently with a calibrated reference shunt and meter, then discharge fully to measure the true state of charge | Amish: "i approve your recommendations for all 555 open decisions." | CGD-DDR-001 item 13 |
| 2026-10-02 | First test partner: a small off-grid solar installer that builds 16S LFP packs, testing on their bench rather than in a customer system (the first candidate to approach) | Amish: "i approve your recommendations for all 555 open decisions." | CGD-DDR-001 item 9 |
| 2026-10-02 | Status light: one three-colour status light added to the supporting electronics, line 15 (option a) | Amish: "i approve your recommendations for all 555 open decisions." | Review note, 2026-09-26 render session, item 4 |
| 2026-10-02 | Product renders: the pack beside the board in the product renders only; engineering media keep the board above the pack | Amish: "i approve your recommendations for all 555 open decisions." | Review note, 2026-09-26 render session, item 2 |
| 2026-10-02 | Product renders keep the cover fixing and power cables, updated to the four pillars of CGD-DDR-003 | Amish: "i approve your recommendations for all 555 open decisions." | Review note, 2026-09-26 render session, items 3 and 5 |
| 2026-10-02 | SwapCell agreement to the NMC profile and the v0.3 CAN message set: record it in the SwapCell repo as well (Amish owns both), but only after the board envelope question is settled (SwapCell expects about 230 x 58 mm, 10 mm or less thick, at $120; CellGuard is 220 x 110 x 33 mm at $138) | Amish: "i approve your recommendations for all 555 open decisions." | CGD-PRC-001 open questions; review note cross-repo actions |

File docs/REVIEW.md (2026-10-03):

# Review note: CellGuard

## Session 2026-09-25: /populate to a strong TRL 2

### What was done

- `docs/01-problem.md` (CGD-PRB-001 v0.2): problem with cited fire statistics and regulation, prior work (foxBMS, diyBMS, Libre Solar BMS), users and context, constraints, out of scope, open questions.
- `docs/03-requirements.md` (CGD-REQ-001 v0.2): 16 measurable requirements (R1 to R16) with targets, a status table and assumptions.
- `docs/02-concept.md` (CGD-PRC-001 v0.2): how it works, 14 numbered components, seven key design choices, first-order numbers with assumptions, state-of-charge method, safety, open questions.
- `cad/src/concept_media.py`: massing model of the board assembly (base plate, PCB, front end, MOSFET bank, shunt, microcontroller, precharge, fuse, studs, balance harness, temperature sensors, connector, cover) on posts above a 4S pack of 280 Ah LFP cells for scale.
- `media/`: `hero.png`, `concept-blueprint.png`, `.pdf` and `.svg`, `exploded.png` with BOM callouts 1 to 13, `cutaway.png`, `flow.png` (power path losses at 40 A, estimates), `model.glb` and `viewer.html`.
- `bom/bom.csv`: 16 lines with indicative prices, lines 1 to 13 matching the exploded view; `bom/bom-notes.md` updated.
- `README.md`: hero image and links line; concept rationale, burning platform, industry and region tables and origin expanded with cited sources; concept, key components and safety brought in line with the precis.
- `docs/pdf/`: branded PDFs of the three controlled documents.

### Key results (estimates, to be checked at TRL 3)

| Quantity | Estimate | Requirement |
| --- | --- | --- |
| Cell range | 4 to 16 LFP cells (12.8 to 51.2 V nominal, 58.4 V maximum) | R1 met by design |
| Board power path loss at 40 A | about 3.2 W (about 4.2 W with hot MOSFETs) | R6 met, thin margin |
| MOSFET junction at 40 A, 40 °C ambient | about 52 °C | R5 met on estimate |
| Balancing time for 1 % imbalance | 10 h on 100 Ah; 28 h on 280 Ah | R7 met to 100 Ah only |
| Precharge of 2 mF to 90 % | about 0.46 s | R13 met |
| Sleep current | about 100 µA | R10 met on estimate |
| Prospective short circuit | about 1 to 8 kA depending on pack | Fuse breaking capacity 10 kA or more |
| Size and mass | about 220 x 110 x 32 mm, about 0.5 kg | R14 met |
| Parts cost | about $124 | **R16 not met, about 3 % over** |

Requirements not met or at risk:

- **R4 (single-fault safety) not met:** the front end protects independently of the microcontroller, but a shorted charge MOSFET or a failed front end leaves only the charger's voltage limit. An independent secondary protector would close this.
- **R16 (cost) not met:** about $124 against $120; about $134 with a secondary protector.
- **R7 not met for 280 Ah cells:** 100 mA passive balancing is slow on large storage cells.
- **R2 at risk:** the front end's cell voltage accuracy is a typical figure; the worst case over temperature is unchecked.
- **R8 at risk:** state-of-charge drift on small packs that rarely reach full charge (about 4 % of a 20 Ah pack in 7 days, estimate).
- **R6 at risk when hot:** about 4.2 W against a 4 W target.

### Proposed, awaiting Amish

Status update: items 1 to 8 are **Decided by Amish, 2026-09-25: go with recommendation** (CGD-DDR-002). Item 9 has no recommendation and stays Proposed, awaiting Amish.

1. **Front end.** Options: TI BQ76952 class (3 to 16 cells, autonomous protection), ADI daisy-chain monitor, Renesas ISL94202 (8 cells maximum). Recommendation: BQ76952 class.
2. **Microcontroller and firmware base.** Options: (A) STM32G0B1 class building on the Libre Solar BMS firmware (Apache-2.0), (B) ESP32-C6 class with wireless, (C) new firmware. Recommendation: A, with a decision on how Apache-2.0 code sits in this MIT-licensed repo.
3. **Secondary protector (safety trade-off).** Add a BQ77216-class independent protector driving a self-control protector fuse, about $10, to meet R4. Recommendation: add.
4. **Budget.** `budget_usd` is unchanged at $120. Options: (a) raise to $140 to cover the secondary protector and margin; (b) keep $120 and drop to 6 MOSFETs and a 30 A rating; (c) keep $120 and count power cables as pack parts. Recommendation: (a).
5. **Current rating.** 40 A continuous first; a 100 A variant later if storage users need it. Recommendation: 40 A.
6. **High-side switching** to keep a common ground for CAN. Recommendation: high side.
7. **Chemistry scope.** Add an NMC profile so CellGuard can serve as SwapCell's 13S BMS, or keep LFP only as the pitch states. Recommendation: design the hardware for both, release LFP firmware first; needs agreement with the SwapCell project. The pitch is unchanged.
8. **CAN message set.** Adopt the SwapCell interface message set as a CellGuard profile. Recommendation: adopt, subject to the SwapCell project.
9. **First test partner** (solar installer, e-bike repair shop or makerspace).

`project.yaml` was not changed: pitch and problem remain accurate.

### Safety concerns

- Very high prospective short-circuit current (about 1 to 8 kA, estimate): DC-rated fuse with 10 kA breaking capacity, insulated tools, covered terminals.
- Sense lead connection order and loose leads can cause false readings and overcharge; first tests on a cell simulator or bench supply only.
- No independent second protection layer yet (R4).
- Voltage spike when the MOSFETs open under load: TVS diode across the output.
- Precharge resistor overheating into a shorted load: 1 s firmware timeout.
- Not certified; research and prototype use only. Must not be presented as meeting UL 2271, AIS-156 or similar.

### Problems and notes

- The hero render shows a 4S pack for scale; the board supports 16S, which is stated in the key figures. Main power cables between pack and studs are not modeled.
- FieldNode uses a single LFP cell, below CellGuard's 4S minimum; it needs its own one-cell protector. No sibling README currently names CellGuard as a dependency.
- The legacy `cad/src/model.py` placeholder is untouched (TRL 3 work).

### Recommended next step

Review this note and the media, then decide items 3 and 4. If approved, run `/advance-trl3` to check the loss, thermal, balancing, short-circuit and state-of-charge estimates by calculation, write the protection threshold table and failure mode analysis, and produce the parametric model and drawing sheet.

## Session 2026-09-25: TRL 3

Done under Amish's 2026-09-25 instruction for this batch ("you know the drill, nothing gets past TRL 3"). He has not reviewed the CellGuard TRL 2 items one by one, so the recommendations are adopted for TRL 3 work, open for his review. TRL 4 is on hold by Amish's instruction.

### What was done

- `docs/decisions/0001-trl2-review-decisions.md` (CGD-DDR-001 v0.1): items 1 to 3 and 5 to 8 adopted as recommended for TRL 3 under Amish's 2026-09-25 instruction, open for his review; the budget and seven other items left open.
- `docs/04-calcs/01-sizing.md` (CGD-CAL-001 v0.1) and `docs/04-calcs/sizing.py`, which prints every quoted number and writes `docs/04-calcs/results.csv`: voltage range, power path loss and thermal, protection thresholds, short circuit, single-fault table, balancing, current and state-of-charge error budget, quiescent current, CAN load and log, precharge, size and mass, cost.
- `cad/src/model.py`: parametric build123d model (14 parts, key dimensions in `PARAMS`, clash check clean) exporting `cad/step/` and `cad/stl/` for the assembly, base plate and cover. `cad/src/concept_media.py` now builds from it.
- `cad/src/sheets.py` and `cad/drawings/CGD-DWG-001.svg`, `.pdf`, `.png`: general arrangement at Rev P1, marked "CONCEPT, NOT FOR FABRICATION" and "PRELIMINARY, NOT FOR FABRICATION". The concept sheet keeps its number CGD-DWG-010, so DWG-001 was free.
- `bom/bom.csv`: 17 lines, all priced, with supplier types; new line 14 for the secondary protector and SCP fuse. `bom/bom-notes.md` updated.
- Docs bumped to v0.3 with revision rows: CGD-PRB-001, CGD-PRC-001, CGD-REQ-001 (R1 adds the NMC profile, R11 the SwapCell v0.3 message set at 250 kbit/s; status table from CAL-001).
- `media/`: all concept media regenerated from the model; every image checked. Flow diagram now shows the SCP fuse loss. Temporary `media/_views*` folders removed.
- `README.md`: TRL badge, links to the drawing and calculations, concept numbers, key components and safety brought in line with CAL-001. Pitch and problem lines unchanged (no rewording was recommended).
- `project.yaml`: `trl: 3`, `trl_target: 3`, evidence listed. `budget_usd` unchanged at 120.

### Requirements (CGD-CAL-001)

9 met on paper, 4 not met, 3 at risk.

| ID | Result | Status |
| --- | --- | --- |
| R6 | 4.44 W board loss at 40 A (0.64 W is the SCP fuse); 3.80 W without it | **Not met** |
| R8 | 10.1 points after 7 days on a 20 Ah pack with a calibrated offset (32.3 uncalibrated); 7.4 on 100 Ah | **Not met** on small packs |
| R14 | 220 x 110 x 32 mm; 0.646 kg against 0.6 kg | **Not met** (mass) |
| R16 | $134.00: 11.7 % over $120; $6.00 under the recommended $140 | **Not met** against $120 |
| R2 | ±15 mV guaranteed over temperature; only typical under 10 mV at 25 °C | At risk |
| R4 | Every single fault ends safe with BQ77216 and SCP fuse; SCP rating for 40 A at 60 V unconfirmed | At risk |
| R7 | 103 mA, 9.7 h for 1 % on 100 Ah; resistor hotspot 73.9 °C against 70 °C | At risk |
| R1, R3, R5, R9 to R13, R15 | See CAL-001 Table 4 (junction 53.7 °C at 40 A; sleep 54.5 µA; CAN load 1.84 %; precharge 0.46 s) | Met on paper |

Corrections to TRL 2 figures: board loss was about 3.2 W (now 4.44 W with the SCP fuse and warm MOSFETs); sleep about 100 µA (now 54.5 µA, the charge pump was double counted); prospective short circuit 1 to 8 kA (now 0.7 to 4.7 kA with cables and board resistance); mass about 0.5 kg (now 0.646 kg); cost $124 (now $134 with the protector).

### Decisions recorded (CGD-DDR-001)

Decided by Amish, 2026-09-25: go with recommendation (first recorded here as adopted for TRL 3, open for his review; confirmed in CGD-DDR-002): BQ76952-class front end; STM32G0B1 with the Libre Solar firmware base; BQ77216-class secondary protector with SCP fuse; 40 A rating; high-side switching; LFP plus NMC-capable hardware with LFP firmware first; SwapCell v0.3 CAN message set as a profile.

### Still awaiting Amish

1. Budget: raise `budget_usd` to $140 (recommended). **Decided by Amish, 2026-09-25: go with recommendation**; now $140.
2. First test partner (no preference stated).
3. Licensing of Apache-2.0 firmware code in the MIT repo. **Decided by Amish, 2026-09-25: go with recommendation** (separate `firmware/third_party/` folder, listed in `LICENSE-SOFTWARE`).
4. Cover material (no recommendation).
5. Low-cost method to check the state-of-charge estimate (no recommendation).
6. TRL 3 engineering proposals: protection thresholds (SCD 100 mV at 15 µs, OCD2 40 mV at 20 ms, OCD1 24 mV at 320 ms, OCC 12 mV), top-cooled MOSFETs, DPAK-class precharge switch, one-point current calibration. **Decided by Amish, 2026-09-25: go with recommendation.**
7. Responses to R6, R8, R14 and R16. R16: **decided** through the $140 budget. R6, R8, R14: no option recommended, still Proposed, awaiting Amish (options in CAL-001 section 12: 1.5 mΩ MOSFETs or moving the SCP fuse off the board; restating R8 for 50 Ah and larger packs, a full-charge prompt or a 0.5 mΩ shunt; a 3 mm plate at 0.581 kg; the $140 budget).

### Cross-repo notes

- SwapCell (interface v0.3): CAN at 250 kbit/s, 11-bit identifiers and 32-byte log records are consistent. As SwapCell's BMS, CellGuard would need the INTERLOCK wake input; sleep then rises to 84.5 µA, inside SwapCell's 100 µA limit. SwapCell's BMS spec says 30 A continuous FETs, which CellGuard's 40 A covers. The SwapCell project has not yet agreed to either profile.
- MotionCore plans to read CellGuard faults over CAN; its bus must run at 250 kbit/s to share the SwapCell profile. No conflict recorded yet, but VESC-class controllers often default to 500 kbit/s, so MotionCore should state its rate.
- FieldNode, CrossSafe and TwinKit do not use CellGuard at this stage; no interface conflict.

### Safety concerns

- Prospective short-circuit current up to about 4.7 kA (16S 280 Ah); fuse 60 A, DC 80 V or more, 10 kA breaking capacity.
- SCD delay must be the 15 µs minimum; at 60 µs a large pack reaches about 2.5 kA and 3.2 J of loop energy before the MOSFETs open. TVS and MOSFET avalanche energy must be checked against about 1 J.
- The SCP fuse is one-shot and not yet sourced at 40 A and 60 V; until it is, use chargers with a fixed, correct end-of-charge voltage.
- Precharge switch sees a 34 W peak; a small SOT-23 MOSFET would fail.
- Not certified; research and prototype use only.

### Problems and notes

- Citations: none were flagged as unchecked. The TI BQ76952 and BQ77216 figures used in CAL-001 were checked with WebFetch on the TI product pages and the BQ76952 data sheet. WebSearch is exhausted.
- Assumed values without a data sheet: SCP fuse resistance, MOSFET package thermal resistances, buck and CAN quiescent currents, loop inductance. They are listed in CAL-001 Table 1.
- The kit's cutaway cuts near the origin; the model is centered close to the origin, so the section passes through the PCB, MOSFETs and studs as intended.
- No TRL 4 material exists in the repo (`build-log/` holds only its README).

### Recommended next step

Review CGD-DDR-001 and decide the budget and the responses to R6, R8, R14 and R16. TRL 4 is on hold by Amish's instruction. When it is released, TRL 4 would need: data sheets for the SCP fuse, MOSFETs, TVS and buck; a schematic and board layout; a bench build on a cell simulator; and a lab test report (TST) of protection trips, losses, balancing and sleep current, with build-log entries.

## Session 2026-09-25: recommendations accepted

Amish wrote on 2026-09-25: "i accept all your recommendations, go with them across all repos." Every item with a recommendation is now **Decided by Amish, 2026-09-25: go with recommendation**, recorded in `docs/decisions/0002-recommendations-accepted.md` (CGD-DDR-002 v0.1). CGD-DDR-001 moves to v0.2 with the same wording.

### Decisions applied and what changed

| Item | Before | After |
| --- | --- | --- |
| Budget (DDR-001 items 4 and 11) | `budget_usd: 120`; BOM $134.00, 11.7 % over; R16 not met | `budget_usd: 140`; BOM $134.00, 95.7 % of budget, $6.00 margin; R16 met |
| Protection settings (item 14) | Engineering proposal, awaiting Amish | Decided: SCD 100 mV at 15 µs (400 A), OCD2 40 mV at 20 ms (160 A), OCD1 24 mV at 320 ms (96 A), OCC 12 mV (48 A); cited in R3 |
| MOSFET package (item 14) | TOLT preferred, TOLL acceptable | TOLT specified in `bom/bom.csv` line 4 (price unchanged); junction 53.7 °C at 40 A |
| Precharge switch (item 14) | DPAK class proposed | DPAK class decided (already in BOM line 7) |
| Current calibration (item 14) | Proposed build step | Decided build step in R9; the build is TRL 4, on hold |
| Firmware licensing (item 10) | Suggested, awaiting Amish | Decided: reused Apache-2.0 files in `firmware/third_party/` with their notices, listed in `LICENSE-SOFTWARE` (note added; no firmware yet) |
| Items 1 to 3 and 5 to 8 | Adopted for TRL 3, open for review | Decided; wording updated in PRB, PRC, REQ, CAL, BOM notes and README |

No decision changed the geometry, so `cad/src/model.py`, the STEP and STL files and CGD-DWG-001 keep Rev P1; all were regenerated for the domain change. Documents bumped: CGD-PRB-001 0.3 to 0.4, CGD-PRC-001 0.3 to 0.4, CGD-REQ-001 0.3 to 0.4, CGD-CAL-001 0.1 to 0.2, CGD-DDR-001 0.1 to 0.2; CGD-DDR-002 v0.1 is new. `sizing.py` now judges cost against $140 and still prints the former $120 comparison. The pitch and problem lines are unchanged (no rewording was recommended).

The README's "What sparked the idea" now traces the idea to the July 2016 CPSC recall of about 501,000 hoverboards with overheating lithium-ion packs; the earlier text about a portfolio review was removed. All generated files were re-rendered so they show designmolecule.com.

### Requirement status (CGD-CAL-001 v0.2)

10 met on paper, 3 not met, 3 at risk.

| ID | Result | Status |
| --- | --- | --- |
| R6 | 4.44 W board loss at 40 A (3.80 W without the SCP fuse) | **Not met** |
| R8 | 10.1 points after 7 days on 20 Ah (calibrated offset); 7.4 on 100 Ah | **Not met** on small packs |
| R14 | 0.646 kg against 0.6 kg | **Not met** (mass) |
| R2 | ±15 mV guaranteed over temperature; only typical at 25 °C | At risk |
| R4 | Every single fault ends safe; SCP fuse at 40 A and 60 V unconfirmed | At risk |
| R7 | Resistor hotspot 73.9 °C against 70 °C | At risk |
| R16 | $134.00 against $140 | Met (was not met against $120) |
| R1, R3, R5, R9 to R13, R15 | As in CAL-001 Table 4 | Met on paper |

### Still awaiting Amish

1. First test partner (no preference stated).
2. Cover material (no recommendation).
3. Low-cost method to check the state-of-charge estimate (no recommendation).
4. Response to R6 board loss (options listed, none recommended).
5. Response to R8 state of charge on small packs (options listed, none recommended).
6. Response to R14 mass (options listed, none recommended).

### Cross-repo actions

- SwapCell: agree to CellGuard's NMC profile (13S) and the SwapCell v0.3 CAN message set as a CellGuard profile; if CellGuard is SwapCell's BMS, SwapCell's INTERLOCK wake input must be carried (sleep 84.5 µA, inside SwapCell's 100 µA limit). Decided on the CellGuard side; SwapCell not edited.
- MotionCore: state its CAN bit rate and run at 250 kbit/s to share the profile. Not edited.
- FieldNode: needs its own one-cell protector, as CellGuard starts at 4S. Not edited.

### TRL

`trl: 3` and `trl_target: 3` are unchanged. TRL 4 remains on hold by Amish's instruction: the one-point calibration, firmware, schematic, board layout, bench build and tests are decided or planned but not started.

## Session 2026-09-26: product appearance model and photoreal renders

Amish chose this repo for the first batch of product renders on 2026-09-26. This session adds an appearance model for photoreal renders; it changes no design value, document, BOM line or drawing.

### What was added

- `cad/src/product_model.py`: `product_parts()` (61 parts: 17 shell, 19 internal, 2 accessory, 23 context), `TITLE` and `RENDER_VIEWS` (hero, exploded and a detail view without the pack). Every main dimension and interface comes from `PARAMS` and `build_parts()` in `cad/src/model.py`.
- Board and enclosure: a clear polycarbonate cover with filleted edges, four fixing screws in bosses, a teal name plate and a warning label; the aluminium base plate with filleted corners and four counterbored mounting holes; brass M6 studs with washers, nuts and thread detail; a bolted 60 A fuse in a dark holder with blades, studs and nuts.
- Populated board, illustrative only (no layout): the model.py chips, shunt and connectors, a finned aluminium-housed precharge resistor, 16 balance resistors, buck, flash, TVS, sleeved capacitors, silkscreen marks and three status lights (green lit), plus the thermal pad and the eight MOSFETs under the board.
- Latching mating plugs on the balance and CAN connectors (accessory).
- Context: an illustrative compact 4S LiFePO4 pack (four prismatic cells about 27 x 148 x 97 mm, not from a data sheet) with busbars, terminal nuts, end plates, woven straps and a label; five balance leads in a braided sleeve, two ring-lug temperature probes, B- and B+ power cables with the fuse link and heat-shrink boots, a CAN cable and a small bench mat.
- `README.md`: hero image now points to `media/render-hero.png`, with a link to `media/render-exploded.png`. Both files are produced later by the render step; they are not in the repo yet.

### Differences from model.py (each Proposed, awaiting Amish)

1. **Cover shown clear.** model.py and the existing media show the cover as dark grey; the BOM says flame-retardant polycarbonate, and the cover material is already an open item. The render uses clear polycarbonate so the board reads through it. Recommendation: adopt a clear UL 94 V-0 polycarbonate cover, since it lets a user see the status lights and board state without opening it; confirm that a clear V-0 grade is available before TRL 4.
2. **Pack beside the board, not under it.** concept_media.py shows the board on posts above a 4S pack of 280 Ah cells. The product render puts a compact illustrative 4S pack beside the board, so the balance harness tail and the two probe leads are rerouted to reach it; the 17-way connector, probe count and exits are unchanged. Recommendation: keep the model.py layout for engineering media and use the beside layout for product renders only.
3. **Cover fixings.** model.py has no cover fixings. The render adds four screws into bosses that stop above the board. Recommendation: accept as an appearance placeholder; the real fixing method belongs with the cover material decision.
4. **Status lights.** The concept does not name any indicator. The render adds three board LEDs (green lit) under BOM line 15. Recommendation: adopt one tri-colour status light as a low-cost aid to fault finding; it would add a few cents to BOM line 15.
5. **Power cables and fuse link drawn.** BOM line 16 cables are not in model.py. The render shows the pack B+ lead to the fuse, a fuse link to the B+ stud and the B- lead to its stud; the fuse holder is split into a holder, blades, studs and nuts inside the model.py fuse envelope. Recommendation: accept; no dimension changes.

### Scope

This is an appearance model only: no tolerances, no PCB layout and no fabrication detail. `trl` and `trl_target` stay at 3, and TRL 4 remains on hold by Amish's instruction.

## Session 2026-09-27: kit 1.5.0 and image quality

- Kit 1.5.0 synced: STANDARDS v1.5 (sections 12 to 15: product renders, storefront images and image quality, public release, authorship and signing), `.kit/cards.py`, `.kit/image_qc.py`, `.kit/release_gate.py`, issue templates, and the `/render-product` and `/release` commands. `CLAUDE.md` now matches `.kit/CLAUDE.md`.
- Every `media/render-*.png` recaptioned from its original render with the new layout: the title, concept label and repository sit in a band above the render and the view note in a band below it, each line wrapped to the image width, so no text overlaps other text or the render or runs off the image. `media/card.png` and `media/social-preview.png` regenerated with the same rules.
- `python .kit/image_qc.py` and `python .kit/release_gate.py` pass. trl stays 3.

## Session 2026-09-30: design for construction and the prototype build plan (kit 1.7.0)

Done under Amish's 2026-09-30 instruction to bring every repo to the approved build plan format, with outstanding decisions kept in a separate register, and to "fix the design assumptions to match and be physically feasible". TRL stays 3.

### What was done

- Kit 1.7.0 installed (`.kit/`, `.claude/commands/`); `CLAUDE.md` matches `.kit/CLAUDE.md`.
- `cad/src/model.py`: constructable design; `build_components()` and `checks()` added; `python cad/src/model.py --check` runs 46 constructability checks (overlaps, contacts, clearances, gap pad squeeze, link height, assembly order). All pass.
- `docs/decisions/0003-design-for-construction.md` (CGD-DDR-003 v0.1, Draft): every change below, made under Amish's 2026-09-30 instruction to make the design physically buildable; open for his review.
- `docs/05-build-plan.md` (CGD-BLD-001 v0.1) and `docs/06-design-decisions.md` (CGD-DEC-001 v0.1), both in `trl_evidence`; `design_state: constructable` in `project.yaml`.
- `cad/src/build_plan_media.py`: overview, 5 making sketches (CGD-DWG-101 to 105), plate hole layout, 6 joint close-ups, 10 assembly step pictures and a connections diagram, in `docs/05-build-plan/` and `cad/drawings/`. Every picture was looked at and fixed where cluttered.
- `cad/drawings/CGD-DWG-001` Rev P2; STEP and STL regenerated (assembly, base plate, cover and the new fuse link); concept media regenerated, including `media/model.glb`.
- `bom/bom.csv`: line 17 repriced ($5.00 to $7.00) and respecified; new line 18, copper fuse link ($2.00); lines 8 and 9 specify the holder and stud dimensions the design relies on. Total $138.00.
- Calculations re-run: CGD-CAL-001 v0.3; CGD-PRC-001, CGD-REQ-001 and CGD-PRB-001 to v0.5; README figures, links line and "Building the prototype" section.
- `cad/src/product_model.py` reads the new spacer positions so it still runs; its appearance details are otherwise unchanged.

### Design changes made for construction (CGD-DDR-003)

1. Board supports: flat plate, six bought 3 mm spacers and six M3 countersunk screws from below, in place of standoffs drawn as part of the plate with no fixing.
2. Gap under the switches: 3.0 mm, with a 1.0 mm gap pad squeezed to 0.7 mm, in place of a 0.5 mm pad with no squeeze.
3. Cover: carried on four 20 mm pillars and held by four M3 screws; connector and probe openings made into notches open at the bottom; walls 0.5 mm clear of the plate.
4. Board fixings at the power end moved to the corners (71.5, ±43.5 mm) to clear the B+ stud and the protector fuse; two fixings added at (48, ±44 mm) for the cover pillars.
5. Fuse holder moved in line with the B+ stud, fixed by four M4 screws; a straight 14 x 3 mm copper link joins it to the B+ stud at matching heights.
6. Power studs specified as soldered through-hole terminals with an M6 stud and 13 mm shoulder.
7. Four M4 tapped mounting holes in the plate (screws from below); hero picture pack posts moved to them.
8. CAN and UART connector moved so its face is flush with the cover, 5 mm past the board edge (was 9 mm).

### Key results (CGD-CAL-001 v0.3)

- No requirement changed status: 10 met on paper, 3 not met (R6 4.44 W against 4 W; R8 on 20 Ah packs; R14 0.664 kg against 0.6 kg, worse than the 0.646 kg before), 3 at risk (R2, R4, R7).
- Hottest switch junction 54.0 °C at 40 A (was 53.7 °C); 99.1 °C bound at 80 A for 10 s with TOLL (was 97.7 °C).
- Envelope 220 x 110 x 33 mm; estimated parts cost $138.00, $2.00 under the $140 value-engineering target (was $6.00 under).

### Proposed, awaiting Amish

All open items are in the register CGD-DEC-001: accept CGD-DDR-003 (recommended); cover material and colour; responses to R6, R8 and R14; state-of-charge test method; first test partner; the render-session items (status light, pack layout in renders, cover fixing and cables in renders); SwapCell agreement.

### Safety concerns

- The gap pad is the only insulation between the live switch tops and the aluminium plate; it must be rated for at least 100 V and replaced if nicked. The build plan adds an insulation check (S1).
- The copper link and stud shoulders are live at pack potential outside the cover; the link is sleeved and the plan requires boots on the studs before anything is connected.
- Unchanged: up to about 4.7 kA prospective short circuit; 15 µs short-circuit delay; protector fuse rating unconfirmed (R4 at risk).

### Recommended next step

Amish to review CGD-DDR-003 and the register. TRL 4 (board layout, bench build on a cell simulator, first checks) remains on hold by his instruction.

## 2026-10-02: open decisions decided

Amish, 2026-10-02: "i approve your recommendations for all 555 open decisions." The recommendations written for this repo's open decisions are recorded as decided.

### Decisions recorded

12 decisions, moved from "Open decisions" to "Decisions made" in the register (CGD-DEC-001 v0.3): design for construction P1 to P8 accepted (CGD-DDR-003, A1); printed flame-retardant polycarbonate cover; opaque prototype cover with a light pipe; 1.5 mΩ-class switches for R6; a full-charge prompt after about five days with R8 restated; R14 relaxed to 0.7 kg; the 4S 20 Ah state-of-charge check; a small off-grid solar installer that builds 16S LFP packs as the first candidate test partner; a three-colour status light; pack beside the board in product renders only; cover fixing and cables kept in renders; SwapCell agreement recorded there once the board envelope question is settled.

### Documents changed

- `docs/06-design-decisions.md`: CGD-DEC-001 v0.3
- `docs/decisions/0001-trl2-review-decisions.md`: CGD-DDR-001 v0.3
- `docs/decisions/0002-recommendations-accepted.md`: CGD-DDR-002 v0.2
- `docs/decisions/0003-design-for-construction.md`: CGD-DDR-003 v0.3 (accepted; status kept Draft)
- `docs/01-problem.md`: CGD-PRB-001 v0.7 (first test partner)
- `docs/02-concept.md`: CGD-PRC-001 v0.7 (key numbers and open questions)
- `docs/03-requirements.md`: CGD-REQ-001 v0.7 (R8 restated, R14 relaxed, status)
- `docs/04-calcs/01-sizing.md`: CGD-CAL-001 v0.5 (requirement table and summary; no calculation re-run)
- `docs/05-build-plan.md`: CGD-BLD-001 v0.2 (mass check against 0.7 kg)
- `README.md` and `bom/bom-notes.md` (not controlled)

### Follow-up actions to carry approved decisions into the design

1. Decision 3: add the light pipe over the status light to the cover in the model, the cover making sketch CGD-DWG-104 and the build plan pictures; state "opaque" in BOM line 13 (model, drawings, pictures, BOM).
2. Decision 4: respecify BOM line 4 as 1.5 mΩ-class TOLT switches and reprice it (BOM).
3. Decision 4: re-run `docs/04-calcs/sizing.py` for the 1.5 mΩ-class switches (board loss, junction temperatures) and update R6 status (calculations).
4. Decision 5: re-run the state-of-charge error for about five days between prompted full charges and update R8 status; the firmware prompt is TRL 4 work (calculations).
5. Decision 7: write the 4S 20 Ah partial-cycling check into the TRL 4 test plan when TRL 4 is opened (docs).
6. Decision 8: approach a small off-grid solar installer that builds 16S LFP packs as the first candidate test partner (docs).
7. Decision 9: add the three-colour status light to BOM line 15 (specification and price) and to the board in the model (BOM, model).
8. Decision 10: regenerate the product renders on Amish's Mac with the pack beside the board (pictures).
9. Decision 11: regenerate the product renders with the four cover pillars and the cables of CGD-DDR-003 (pictures).
10. Decision 12: once the board envelope question is settled, record the agreement to the NMC profile and the v0.3 CAN message set in the SwapCell repo (docs).

### Points found in the review

- SwapCell expects a battery management board about 230 x 58 mm and 10 mm or less thick (SwapCell register, 'To confirm' item 3), and prices it at $120; CellGuard is 220 x 110 x 33 mm and $138. Item 12 cannot be closed as stated until one side changes.
- Option (b) for R6 does not compare like with like: it reduces the counted board loss by redefining the boundary, not by reducing heat.
- The value-engineering margin is $2, and the protector fuse price is still unconfirmed (DDR-003 A2); fitting 1.5 milliohm switches (item 4) will likely put the board over the $140 target.
- The register listed 'decision 4 is (a)' under 'To confirm' item 8 for a clear sheet, but the clear cover is decision 3, not 4. Corrected in CGD-DEC-001 v0.3.

## 2026-10-02: Approved follow-ups carried out

Amish, 2026-10-02, approved carrying out every follow-up action from the open-decision sign-off ("APPROVED CHANGES, COMPLETE THESE") and preparing the render scenes. TRL stays 3.

### Follow-ups

| # | Follow-up | Done | What changed |
| --- | --- | --- | --- |
| 1 | Decision 3: light pipe over the status light in the cover; "opaque" in BOM line 13 | Done | `cad/src/model.py`: 3 mm flanged light pipe pressed into a 3.2 mm hole in the cover top, its foot 0.5 mm above the status light; new BOM line 19 ($0.80). CGD-DWG-104 Rev P2 (hole position and fitting note); new joint picture `docs/05-build-plan/joint-07.png`; overview and steps 1 and 9 show it. BOM line 13 now "Flame-retardant cover (opaque)" |
| 2 | Decision 4: BOM line 4 as 1.5 mΩ-class TOLT switches, repriced | Done | Line 4 respecified (1.6 mΩ or less maximum, Infineon IPTC015N10NM5 class) and repriced from $2.50 to $5.00 each, basis in the line's notes |
| 3 | Decision 4: re-run the sizing for the 1.5 mΩ-class switches; R6 status | Done | `docs/04-calcs/sizing.py` re-run; board loss 3.47 W at 40 A. **R6 changes from not met to met on paper** |
| 4 | Decision 5: state-of-charge error over about five days between prompted full charges; R8 status | Done | 8.7 points on 20 Ah with a calibrated coulomb counter offset (24.5 uncalibrated), 6.7 on 100 Ah. **R8 changes from not met to met on paper with calibration**. The calibrated offset is TI's typical figure; the firmware prompt itself is TRL 4 work |
| 5 | Decision 7: 4S 20 Ah partial-cycling check in the TRL 4 test plan | Not done | TRL 4 is not open, and a test plan is TRL 4 work under the TRL 3 cap. The check is recorded in the register (CGD-DEC-001) and cited in CGD-CAL-001 v0.6 section 6 for when TRL 4 opens |
| 6 | Decision 8: approach a small off-grid solar installer as the first candidate test partner | Not done | An outreach action for Amish, not a design change; recorded in CGD-PRB-001 and the register. Nothing further to change in this repo |
| 7 | Decision 9: three-colour status light in BOM line 15 and on the board in the model | Done | Line 15 adds a PLCC-4 RGB LED with three resistors ($16.00 to $16.35); `model.py` places it 30 mm toward the signal end of the board centre and 20 mm to the B+ side. CGD-DWG-103 Rev P2 notes its position |
| 8 | Decision 10: product renders with the pack beside the board | Scenes ready | `cad/src/product_model.py` keeps the pack beside the board; render scenes exported (below). Photoreal rendering is on Amish's Mac |
| 9 | Decision 11: product renders with the four cover pillars and the cables of CGD-DDR-003 | Scenes ready | `product_model.py` now takes the pillars, spacers, nuts, cover, fuse holder position, copper link and status light from `model.py`; the B+ cable goes to the fuse holder's outer terminal and the copper link to the B+ stud |
| 10 | Decision 12: SwapCell agreement once the board envelope question is settled | Not done | The envelope question is not settled; the SwapCell part is listed under cross-repo actions |

### Model and checks

- `python cad/src/model.py --check`: 55 of 55 checks pass (was 46). New checks: status light soldered to the board, light pipe flange on the cover, light pipe foot 0.5 mm clear of the status light, light pipe and status light clear of the controller and pillars, light pipe on the status light axis, light pipe inside the envelope, light pipe assembly direction.
- STEP and STL regenerated (`cad/step/`, `cad/stl/`); envelope still 220 x 110 x 33 mm; no clashes.

### Requirement status changes (CGD-CAL-001 v0.6, CGD-REQ-001 v0.8)

- R6: not met to **met on paper** (3.47 W against 4 W; was 4.44 W).
- R8: not met to **met on paper with calibration** (8.7 points on 20 Ah over five days against ±10).
- R16: within the target to **over the value-engineering target by $19.15**. Value-engineering target: USD 140.00. Estimated cost of the constructable design: USD 159.15 (USD 19.15 over the target). `budget_usd` unchanged.
- R5 stays met with more margin: junction 51.0 °C (TOLT) at 40 A, 77.6 °C bound (TOLL) at 80 A for 10 s.
- R14 stays met on paper: 0.664 kg against 0.7 kg (status light and light pipe weigh under 1 g).
- Now 12 of 16 met on paper; R2, R4 and R7 at risk; R16 over the target.
- Side effect to note: the lower-resistance switches raise the prospective short-circuit current slightly, to about 5.0 kA on a 16S 280 Ah pack (was 4.7 kA), still inside the fuse's 10 kA breaking capacity. Safety notes updated.

### Documents changed and new versions

- `docs/04-calcs/sizing.py` and `results.csv`; `docs/04-calcs/01-sizing.md` CGD-CAL-001 v0.6
- `docs/03-requirements.md` CGD-REQ-001 v0.8
- `docs/02-concept.md` CGD-PRC-001 v0.8
- `docs/01-problem.md` CGD-PRB-001 v0.8 (cost constraint)
- `docs/05-build-plan.md` CGD-BLD-001 v0.3 (status light, opaque cover with light pipe, new Figure 14, wiring now Figure 15)
- `docs/06-design-decisions.md` CGD-DEC-001 v0.4 (value engineering restated; To confirm items 1, 5 and new item 9)
- `bom/bom.csv` (lines 1, 4, 13, 15 and new line 19) and `bom/bom-notes.md`; `README.md`
- `cad/src/model.py`, `cad/src/sheets.py`, `cad/src/concept_media.py`, `cad/src/build_plan_media.py`, `cad/src/product_model.py`
- BOM line 1 specification corrected from "with 4 PCB standoffs" to the flat plate of CGD-DDR-003 (it had been left behind on 2026-09-30).

### Pictures regenerated (each looked at)

- `cad/drawings/CGD-DWG-001` Rev P3 (isometric view moved down to clear the longer revision table), CGD-DWG-103 Rev P2, CGD-DWG-104 Rev P2.
- `docs/05-build-plan/overview.png`, `joint-07.png` (new), `step-01.png` to `step-10.png` (step 1 lists the status light; step 9 says the light pipe goes in first).
- `media/hero.png`, `concept-blueprint.png`, `.pdf` and `.svg`, `exploded.png` (callouts 15 and 19 added), `cutaway.png`, `flow.png` (MOSFET loss 1.4 W), `model.glb`, `viewer.html`.
- `python3 .kit/drawing.py --check-text cad/drawings/*.svg media/concept-blueprint.svg`: no hits.

### Render scenes (appearance model)

- `cad/src/product_model.py` brought in line with the constructable design: opaque cover on four pillars with four screws, light pipe with a lit green tip, one three-colour status light, flat plate with the four M4 mounting holes, six spacers, two corner nuts, fuse holder in line with the B+ stud, copper fuse link with sleeve, B+ cable to the holder's outer terminal. 67 parts, all valid. `RENDER_VIEWS` unchanged in name: hero, exploded, detail (notes updated).
- Exported with `python3 .kit/export_views.py /home/claude/renders/cellguard`: `cellguard__hero`, `cellguard__exploded` and `cellguard__detail` (.npz and .json each) and `cellguard__jobs.json`.
- Not rendered here: `media/render-*.png`, `media/card.png` and `media/social-preview.png` are made next on Amish's Mac.

### Appearance deviations (Proposed, awaiting Amish)

1. The light pipe tip is drawn lit green and the status light housing white; the model has no colour. Recommendation: accept as appearance only.
2. The copper link is shown with a red heat-shrink sleeve over its middle, as the build plan specifies. Recommendation: accept.
3. Name plate, warning label and the board's illustrative parts (balance resistors, capacitors, silkscreen) are kept from the 2026-09-26 appearance model. Recommendation: accept as appearance only.

### Cross-repo actions

- SwapCell: record the agreement to CellGuard's NMC profile and the v0.3 CAN message set once the board envelope question is settled. SwapCell expects a board about 230 x 58 mm, 10 mm or less thick, at $120; CellGuard is 220 x 110 x 33 mm and now estimated at $159.15. Not edited.

### Safety concerns

- Prospective short-circuit current up to about 5.0 kA (16S 280 Ah) with the lower-resistance switches; the 10 kA fuse and the 15 µs short-circuit delay still cover it.
- The light pipe is an insulator, so the hole it fills adds no exposed conductor and no path to live parts.

### Recommended next step

Render the product views on Amish's Mac from the exported scenes, then `python .kit/cards.py .`. Confirm the switch price at quantity and the SCP fuse (register, To confirm items 1 and 5). TRL 4 remains on hold.

## Session 2026-10-02: Photoreal renders redone on the constructable design

Amish, 2026-10-02: "Photoreal renders are out of date in most repos ... COMPLETE THESE". Rendered with Blender Cycles on Amish's Mac (batch F1) from the scenes exported from `cad/src/product_model.py`, captioned with `.kit/photo_caption.py`; `media/card.png` and `media/social-preview.png` regenerated with `.kit/cards.py`. Each raw render was looked at once. No commit or push; `trl` unchanged.

- Views: `media/render-hero.png`, `media/render-exploded.png`, `media/render-detail.png`.
- Re-renders: none. The detail note now says "the cable slot in the cover at left" instead of "plugs at left", because the plugs sit behind the cover in that view (`RENDER_VIEWS` in `cad/src/product_model.py` updated to match).
- Appearance deviations already logged (session "Approved follow-ups carried out", Proposed, awaiting Amish): light pipe drawn lit green with a white status light housing; red heat-shrink sleeve on the copper link; name plate, warning label and illustrative board parts. Unchanged.
- `python3 .kit/image_qc.py`: 5 images, 0 problems. `python3 .kit/render.py --check`: no FAIL, no storefront warning.
- The "Stale media" note of the 2026-09-30 session is removed; this work resolves it.

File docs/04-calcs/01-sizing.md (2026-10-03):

---
doc_id: CGD-CAL-001
title: CellGuard sizing calculations
project: CellGuard
doc_type: Calculation note
version: "0.6"
status: Draft
date: '2026-10-02'
author: Amish Chadha
license: CERN-OHL-S-2.0
revisions:
- version: "0.1"
  date: '2026-09-25'
  author: Amish Chadha
  change: First TRL 3 sizing note (voltage range, power path loss and thermal, protection thresholds, short circuit, single-fault analysis, balancing, current and state of charge, quiescent current, CAN and log, precharge, size and mass, cost)
- version: "0.2"
  date: '2026-09-25'
  author: Amish Chadha
  change: Recommendations accepted by Amish (DDR-002)
- version: "0.3"
  date: '2026-09-30'
  author: Amish Chadha
  change: Design for construction (CGD-DDR-003). Gap pad 1.0 mm compressed to 0.7 mm; mass adds the spacers, pillars, screws and copper fuse link; cost adds BOM line 18 and reprices line 17
- version: "0.4"
  date: '2026-10-01'
  author: Amish Chadha
  change: Budget treated as a value-engineering target; cost wording only, no number changed
- version: "0.5"
  date: '2026-10-02'
  author: Amish Chadha
  change: "Requirement table: R14 relaxed to 0.7 kg and met on paper; R6 and R8 responses decided (CGD-DEC-001); no calculation re-run"
- version: "0.6"
  date: '2026-10-02'
  author: Amish Chadha
  change: "Re-run for the 2026-10-02 decisions: 1.5 mOhm-class switches (R6 now met on paper, R5 junctions lower, short-circuit currents slightly higher); state-of-charge error over five days between prompted full charges (R8 now met on paper with calibration); status light and light pipe in mass and cost; cost USD 159.15, over the value-engineering target"
---

# CellGuard sizing calculations

On paper, CellGuard meets 12 of its 16 requirements and none is failed outright. This version is re-run for the responses Amish decided on 2026-10-02 (CGD-DEC-001). With 1.5 mΩ-class switches the board loses about 3.5 W at 40 A, so **R6 is now met** (it was 4.4 W against 4 W). With the firmware prompting for a full charge after about five days, the state-of-charge error on a 20 Ah pack reaches 8.7 points between prompted full charges against the restated ±10 points, so **R8 is now met on paper**, provided the coulomb counter offset is calibrated at build. R14 was relaxed to 0.7 kg, and the board's 0.664 kg meets it. The estimated parts cost is $159.15: value-engineering target USD 140.00, estimated cost of the constructable design USD 159.15 (USD 19.15 over the target), mainly because the 1.5 mΩ-class switches cost about twice as much as the 2.5 mΩ parts (R16 is reported against the target, not as a failure). Three are **at risk**: cell voltage accuracy at 25 °C (R2), single-fault safety until a suitable protector fuse is confirmed (R4) and the balance resistor hotspot (R7). Two TRL 2 figures were optimistic and are corrected here: sleep current is about 55 µA, not 100 µA, and the prospective short-circuit current is about 0.7 to 5.0 kA, not 1 to 8 kA, once cables and the board are counted.

Every number in this note is printed by `docs/04-calcs/sizing.py` (run from the repo root: `python docs/04-calcs/sizing.py`), which also writes `docs/04-calcs/results.csv`. The script reads part volumes and the envelope from `cad/src/model.py` and costs from `bom/bom.csv`. All values are first-principles estimates; nothing is measured.

## 1. Assumptions

*Table 1. Inputs. Data sheet values were checked on TI's BQ76952 and BQ77216 product pages and the BQ76952 data sheet on 2026-09-25; all other values are assumptions.*

| Input | Value | Basis |
| --- | --- | --- |
| Cell limits (LFP) | 3.65 V maximum, 3.20 V nominal, 2.50 V minimum | Typical LFP data; each build uses its own cell data sheet |
| Reference packs | 16S 20 Ah (3 mΩ cells, 0.3 mΩ links) and 4S or 16S 280 Ah (0.25 mΩ cells, 0.1 mΩ busbars) | CGD-REQ-001 assumptions |
| Load | 40 A continuous, 80 A for 10 s, 40 °C ambient | R5 |
| MOSFETs | 1.5 mΩ class at 25 °C (decided 2026-10-02, CGD-DEC-001; 2.5 mΩ before), +0.67 % per K, 4 in parallel per direction, hottest carries 10 % more than its share | BOM line 4 |
| Shunt | 0.25 mΩ, 1 %, 50 ppm/K | BOM line 5 |
| SCP fuse | 0.40 mΩ | Assumed; no data sheet chosen yet |
| Main fuse, holder and links | 1.0 mΩ | Assumed |
| PCB power copper | 4 layers of 70 µm copper in parallel; positive path 60 mm by 25 mm, negative path 90 mm by 25 mm; 0.05 mΩ per stud joint; 50 °C copper | From the model layout |
| Heat transfer | Plate 8 W/(m²·K) on both faces; PCB under the cover 6 W/(m²·K); half of the PCB copper, shunt and SCP loss reaches the plate | Natural convection plus radiation, still air |
| Package to plate | Top-cooled TOLT 0.5 K/W, or TOLL through the mold 20 K/W; gap pad 1.0 mm compressed to 0.7 mm between the MOSFETs and the plate (CGD-DDR-003), 3 W/(m·K), 1 cm² per FET | Assumed typical values |
| Front end (BQ76952) | 3 to 16 cells; total cell voltage error ±15 mV from −40 to 85 °C, under 10 mV typical; SCD 10 to 500 mV, 15 to 450 µs; OCD 4 to 200 mV, 10 to 425 ms; OCC 4 to 124 mV; SLEEP 41 µA typical with DSG on; SHUTDOWN 1 µA; coulomb counter offset ±1 LSB uncalibrated, under 1 µV typical; gain 130,845 to 132,335 LSB/V; 100 mA maximum balancing current per cell | [TI BQ76952 product page](https://www.ti.com/product/BQ76952) and [data sheet](https://www.ti.com/lit/ds/symlink/bq76952.pdf) |
| Secondary protector (BQ77216) | 3 to 16 cells; overvoltage, undervoltage, open wire and temperature; separate COUT and DOUT outputs; OV accuracy ±10 mV at 25 °C, ±20 mV from 0 to 60 °C; about 1 µA; TSSOP-24 at 0.65 mm pitch | [TI BQ77216 product page](https://www.ti.com/product/BQ77216) |
| Other quiescent loads | Microcontroller stop mode 5 µA, CAN transceiver standby 10 µA, flash 1 µA (all at 3.3 V); buck 70 % efficient at light load with 10 µA quiescent; TVS leakage 1 µA | Assumed typical values |
| Short-circuit loop | 1 µH loop inductance; 10 µs MOSFET turn-off after the trip | Assumed |
| CAN | 250 kbit/s, 135 bits worst-case frame; SwapCell interface v0.3 message rates | SWC-PRC-001 v0.3 |
| State of charge | Anchor detection 2 points; learned capacity 2 %; residual gain error 0.5 % after one-point calibration; 0.5 equivalent full cycles a day (3.5 in 7 days); the firmware prompts for a full charge after 5 days without one (CGD-DEC-001) | Assumed; prompt interval decided 2026-10-02 |

## 2. Voltage range (R1)

A 4S to 16S LFP pack spans 12.8 to 51.2 V nominal and reaches 58.4 V at full charge, below the 60 V ceiling. The 100 V MOSFETs have a margin of 1.71 times at 58.4 V. An NMC profile fits up to 14 cells under 60 V; SwapCell's 13S pack reaches 54.6 V. R1 is met by design review.

## 3. Power path loss and thermal (R5, R6)

**Loss (R6).** With the 1.5 mΩ-class switches decided on 2026-10-02, the MOSFETs lose 1.20 W at 40 A with cold junctions and 1.41 W at the converged junction temperature. The shunt adds 0.40 W, the PCB copper and stud joints (0.569 mΩ at 20 °C, 0.635 mΩ at 50 °C) 1.02 W, and the SCP fuse 0.64 W. The board loss is **3.47 W, and R6 is met on paper** with 0.53 W to spare; without the SCP fuse it would be 2.83 W. The former 2.5 mΩ parts would lose about 0.94 W more, about 4.4 W in all, which is why R6 was not met at v0.5. The external main fuse adds 1.60 W, so the whole power path loses 5.07 W, 99.75 % efficient for a 16S pack at 40 A. The TRL 2 figure of about 3.2 W left out the secondary protector and the temperature rise of the MOSFETs.

**Thermal (R5).** The base plate (0.0484 m² over both faces) rises 10.4 K at 40 A. The hottest MOSFET dissipates 0.213 W, so its junction reaches **51.0 °C** at 40 °C ambient with a top-cooled TOLT package and 55.4 °C with a TOLL package cooled through its mold. The plate holds 234 J/K and has a time constant of 10.1 min, so a 10 s peak at 80 A adds only 0.60 K to it. The hottest MOSFET then dissipates 0.97 W; bounding its junction by the steady-state value gives 54.4 °C (TOLT) or 77.6 °C (TOLL). Both are under the 110 °C limit, so **R5 is met**. The TOLL margin was thin with the 2.5 mΩ parts (99.1 °C), so the BOM specifies a top-side cooled TOLT package (decided, CGD-DDR-002).

## 4. Protection thresholds, short circuit and single faults (R3, R4)

**Thresholds (R3).** On the 0.25 mΩ shunt the front end's steps give the settings in Table 2, all inside its ranges. The 40 A continuous and 80 A for 10 s envelope is longer than the front end's longest hardware delay (425 ms), so the microcontroller enforces it with a current and time limit; the hardware trips in Table 2 back it up without the microcontroller.

*Table 2. Protection settings (decided by Amish, 2026-09-25: go with recommendation; CGD-DDR-002).*

| Protection | Setting | Current | Delay |
| --- | --- | --- | --- |
| Short circuit in discharge (SCD) | 100 mV | 400 A | 15 µs |
| Overcurrent in discharge 2 (OCD2) | 40 mV | 160 A | 20 ms |
| Overcurrent in discharge 1 (OCD1) | 24 mV | 96 A | 320 ms |
| Overcurrent in charge (OCC) | 12 mV | 48 A | Front-end default range |
| Cell overvoltage and undervoltage | 3.65 V and 2.50 V (LFP) | | Configuration file |
| Charge lockout | Below 0 °C | | Configuration file |

The smallest SCD step is 40 A, so the scale is coarse but adequate. The short-circuit trip completes within 25 µs, well inside the 500 µs of R3. **R3 is met on paper.**

**Short circuit.** The board and fuse add 2.97 mΩ to the short-circuit loop (3.47 mΩ with the former 2.5 mΩ switches) and the two power cables 1.72 mΩ. The prospective current is 716 A (4S 20 Ah), 891 A (16S 20 Ah), 2,102 A (4S 280 Ah) and 4,976 A (16S 280 Ah), a little higher than at v0.5 because the lower-resistance switches take less out of the loop. The 10 kA breaking capacity of the pack fuse covers all of them. With a 1 µH loop, current is still rising when the MOSFETs open. At a 15 µs SCD delay the 16S 280 Ah pack reaches 1,129 A at turn-off (about 282 A per MOSFET) and leaves 0.64 J of loop energy for the TVS diode and the MOSFETs' avalanche rating. At the front end's longer 60 µs delay the same pack reaches 2,555 A and 3.26 J. **The SCD delay must therefore be set to its 15 µs minimum**, and the TVS diode and MOSFET avalanche energy must be checked against about 1 J when parts are chosen.

**Single faults (R4).** Table 3 is a first failure mode and effects analysis for the faults R4 names.

*Table 3. Single faults with the secondary protector.*

| Single fault | Detected by | Result |
| --- | --- | --- |
| Microcontroller crash | Front end runs protection on its own | Pack stays protected; no state of charge or CAN until reset |
| Charge MOSFET shorted | Front end sees cell overvoltage but cannot open the charge path | BQ77216 COUT blows the SCP fuse; pack permanently disconnected (safe) |
| Discharge MOSFET shorted | Front end sees cell undervoltage but cannot open the discharge path | BQ77216 DOUT blows the SCP fuse; pack disconnected (safe) |
| Front end failed | BQ77216 monitors cells independently | SCP fuse blows on overvoltage or undervoltage |
| Open sense wire | Front end and BQ77216 open-wire detection | Both FETs open; BQ77216 blows the SCP fuse if the front end does not act |
| Failed temperature sensor | Out-of-range reading in the front end | Treated as over-temperature; FETs open |

With the secondary protector, no single fault in Table 3 leaves the pack able to be overcharged or over-discharged. **R4 is met on paper but at risk** until an SCP fuse rated for 40 A continuous at 60 V DC or more is found; if none exists, a DC contactor or a second MOSFET pair driven by the BQ77216 is the fallback.

## 5. Balancing (R7)

The 33 Ω bleed resistors draw 103 mA at 3.40 V and dissipate 0.350 W each; eight non-adjacent channels at once dissipate 2.80 W. A 1 % imbalance takes 1.9 h to correct on a 20 Ah pack, 9.7 h on 100 Ah and 27.2 h on 280 Ah. R7 limits the 24 h target to packs up to 100 Ah, so the 280 Ah figure is a limitation to publish, not a failure. Under the cover the PCB bulk rises 16.4 K, to 56.4 °C at 40 °C ambient, but a balance resistor's own hotspot reaches about 73.9 °C. **R7 is at risk** on the 70 °C limit; spreading the resistors or balancing at most four channels at once would bring it under.

## 6. Current measurement and state of charge (R8, R9)

**Current (R9).** One coulomb counter step is 7.60 µV, 30.4 mA on the shunt; the typical calibrated offset of 1 µV is 4.0 mA. The front end's gain spread is ±0.57 %, which with the 1 % shunt gives 1.57 % uncalibrated, outside R9. A one-point gain calibration at build leaves about 0.5 %, so the error at 80 A is 0.404 A against a 0.850 A limit. **R9 is met on paper with calibration**, which is now a decided build step (CGD-DDR-002); the build itself is TRL 4 work, on hold.

**State of charge (R8).** After a full charge the error is 5.0 points (2 for anchor detection, 2 for the learned capacity, 1 for gain over one cycle), which just meets the ±5 point target. On 2026-10-02 Amish decided that the firmware prompts for a full charge when about five days pass without one, and restated R8's partial-cycling clause to apply between prompted full charges (CGD-DEC-001). Over five days of partial cycling the error on the 20 Ah reference pack grows to **8.7 points with a calibrated offset**, against the ±10 point target, so **R8 is met on paper with calibration**; it is 6.7 points on 100 Ah and 6.4 points on 280 Ah. Without offset calibration the 20 Ah figure is 24.5 points, so the result depends on calibrating the coulomb counter offset at build. Over five days the offset may be up to 6.2 mA (about 1.5 µV across the shunt) for 10 points on 20 Ah; the calibrated figure assumed here, 4.0 mA, is TI's typical value, not a guaranteed one, and is to be checked in the 4S 20 Ah state-of-charge test decided on 2026-10-02. For comparison, 7 days without a full charge would give 10.1 points on 20 Ah (32.3 uncalibrated), 7.4 on 100 Ah and 7.0 on 280 Ah; the 0.5 mΩ shunt that would have halved the offset is not fitted.

## 7. Quiescent current (R10)

Sleep draws 54.5 µA: the front end 41.0 µA with the discharge FETs held on, the 3.3 V loads through the buck 1.5 µA, the buck itself 10.0 µA, the secondary protector 1.0 µA and TVS leakage 1.0 µA. That is 0.20 % per month of a 20 Ah pack. Ship mode draws 6.0 µA. **R10 is met on estimate.** With SwapCell's INTERLOCK loop (30 µA) a CellGuard used as SwapCell's BMS draws 84.5 µA, inside SwapCell's 100 µA limit. The TRL 2 estimate of about 100 µA double counted the charge pump, which the front end's SLEEP figure already includes.

## 8. Interface and log (R11, R12)

The SwapCell v0.3 message set adds up to 34.1 frames per second between pack and host, a bus load of 1.84 % at 250 kbit/s. **R11 is met by design.** At 32 bytes per record, the 2 MiB flash holds 65,536 records; 2,000 records need 64,000 bytes. **R12 is met.**

## 9. Precharge (R13)

A 100 Ω resistor into 2 mF has a time constant of 0.20 s and reaches 90 % of 58.4 V in 0.46 s, dissipating 3.38 J. Peak current is 0.584 A and peak power 34.1 W, so the precharge switch needs a DPAK-class P-channel MOSFET whose safe operating area covers 35 W for about 0.2 s. Into a shorted load the 1 s timeout limits the energy to 34.1 J. **R13 is met.**

## 10. Size and mass (R14)

The model envelope is 220 x 110 x 33 mm (to the cover screw heads), inside 230 x 120 x 40 mm. The mass, from model volumes and stated densities plus assumed masses for bought parts, is **0.664 kg, and R14 is met on paper** against the 0.7 kg target Amish set on 2026-10-02 (relaxed from 0.6 kg, CGD-DEC-001). The status light and light pipe added on 2026-10-02 weigh well under 1 g together, and the 1.5 mΩ-class switches are in the same package as before, so the total is unchanged. Version 0.3 adds the parts that make the design buildable (CGD-DDR-003): the gap pad, spacers, pillars, screws and nuts (25 g) and the copper fuse link (12 g). The fuse and holder stay at the concept figure of 89 g until the holder is chosen, although the holder is now drawn smaller. The base plate is the largest item at 260 g; the 4 mm plate is kept (decided 2026-10-02), although a 3 mm plate would bring the total to 0.599 kg. The TRL 2 estimate of about 0.5 kg left out the studs' hardware and underestimated the fuse holder.

## 11. Cost (R16)

The BOM has 19 lines, all priced, and totals **$159.15**: $124.00 as at TRL 2, $10.00 for the secondary protector, $2.00 more for the gap pad, spacers, pillars and screws (line 17) and $2.00 for the copper fuse link (line 18, CGD-DDR-003), then, for the decisions of 2026-10-02 (CGD-DEC-001), $20.00 more for the eight 1.5 mΩ-class switches (line 4, $5.00 each in place of $2.50), $0.35 for the three-colour status light (line 15) and $0.80 for the light pipe (new line 19). Value-engineering target: USD 140.00 (`budget_usd: 140` in `project.yaml`, a hypothetical control target, not a limit, set by Amish on 2026-09-25, CGD-DDR-002). Estimated cost of the constructable design: USD 159.15 (USD 19.15 over the target), 113.7 % of it, so **R16 is over the value-engineering target by $19.15**; the unconfirmed SCP fuse price is still to come. Against the former $120 target it would be 32.6 % over.

## 12. Results

*Table 4. Requirement status at TRL 3 (over target and at risk first).*

| ID | Calculated value | Target | Status |
| --- | --- | --- | --- |
| R16 | $159.15; 113.7 % of target | $140 value-engineering target (raised from $120, CGD-DDR-002) | Over the value-engineering target by $19.15 |
| R2 | ±15 mV from −40 to 85 °C; under 10 mV typical at 25 °C | ±10 mV at 25 °C, ±15 mV from −20 to 60 °C | At risk (no guaranteed 25 °C figure) |
| R4 | All single faults in Table 3 end safe with the BQ77216 and SCP fuse | No single fault allows overcharge or over-discharge | At risk (SCP fuse rating unconfirmed) |
| R7 | 103 mA; 9.7 h for 1 % on 100 Ah; PCB 56.4 °C, resistor hotspot 73.9 °C | 100 mA; 24 h; 70 °C | At risk (hotspot) |
| R1 | 12.8 to 58.4 V; 1.71 times MOSFET margin | 4 to 16 LFP cells, under 60 V | Met |
| R3 | Table 2 settings inside front-end ranges; SCD trip within 25 µs | Trip within 500 µs; all thresholds configurable | Met on paper |
| R5 | Junction 51.0 °C (TOLT) or 55.4 °C (TOLL) at 40 A; 77.6 °C bound at 80 A for 10 s (TOLL) | 110 °C or less | Met on paper |
| R6 | 3.47 W board loss at 40 A with 1.5 mΩ-class switches (2.83 W without the SCP fuse; about 4.4 W with the former 2.5 mΩ parts) | 4 W or less | Met on paper (was not met at v0.5) |
| R8 | 5.0 points after a full charge; 8.7 points after 5 days on 20 Ah with a calibrated offset (24.5 uncalibrated); 6.7 on 100 Ah | ±5 points; ±10 points between prompted full charges, about five days (restated, CGD-DEC-001) | Met on paper with calibration (was not met at v0.5) |
| R9 | 0.404 A error at 80 A after calibration; 1.57 % gain error uncalibrated | ±1 % ±50 mA (0.850 A at 80 A) | Met on paper with calibration |
| R10 | 54.5 µA sleep; 6.0 µA ship mode | 300 µA; 10 µA | Met on estimate |
| R11 | 1.84 % bus load at 250 kbit/s; SwapCell v0.3 message set | Published message set on CAN 2.0B, UART, enable | Met by design |
| R12 | 65,536 records of 32 bytes | 2,000 records | Met |
| R13 | 0.46 s to 90 %; 3.38 J | 1 s for 2 mF | Met |
| R14 | 220 x 110 x 33 mm; 0.664 kg | 230 x 120 x 40 mm; 0.7 kg (relaxed from 0.6 kg, CGD-DEC-001) | Met on paper |
| R15 | TQFP-48 at 0.5 mm, TSSOP-24 at 0.65 mm, leaded MOSFET and regulator packages | No BGA; nothing finer than 0.5 mm | Met by design review |

**Responses decided by Amish on 2026-10-02** (CGD-DEC-001): R6, 1.5 mΩ-class switches; R8, a full-charge prompt after about five days, with the target restated to apply between prompted full charges; R14, the target relaxed to 0.7 kg with the 4 mm plate kept. This version (v0.6) is re-run for them: R6, R8 and R14 are now met on paper, and the switches move R16 to $19.15 over the value-engineering target. The options were: R6, choose 1.5 mΩ-class MOSFETs (saves about 0.96 W, bringing the board to about 3.5 W) or mount the SCP fuse beside the main fuse and count it with the external fuse; R8, restate the target for packs of 50 Ah and larger, add a periodic full-charge prompt, or fit a 0.5 mΩ shunt; R14, a 3 mm plate (0.599 kg) or relax the target to 0.65 kg. R16 was closed by the $140 budget (CGD-DDR-002).

## 13. Limits of this note

- Nothing here is measured. Heat transfer coefficients, copper paths, the SCP fuse resistance, loop inductance and the quiescent currents of parts not yet chosen are assumptions.
- Balancing heat and state-of-charge error depend on firmware settings that do not exist yet.
- The TVS diode, MOSFET avalanche energy and SCP fuse need data sheets before TRL 4.

> **Safety:** CellGuard connects directly to lithium cells that can deliver several thousand amperes into a short circuit (about 5.0 kA for a 16S 280 Ah pack by this note). The pack fuse must be DC rated at 80 V or more with a breaking capacity of 10 kA or more, the SCD delay must be set to its 15 µs minimum, and every threshold change must first be tried on a cell simulator or a current-limited bench supply. The secondary protector's SCP fuse is a one-shot device: once blown, the board must be inspected before it is repaired.

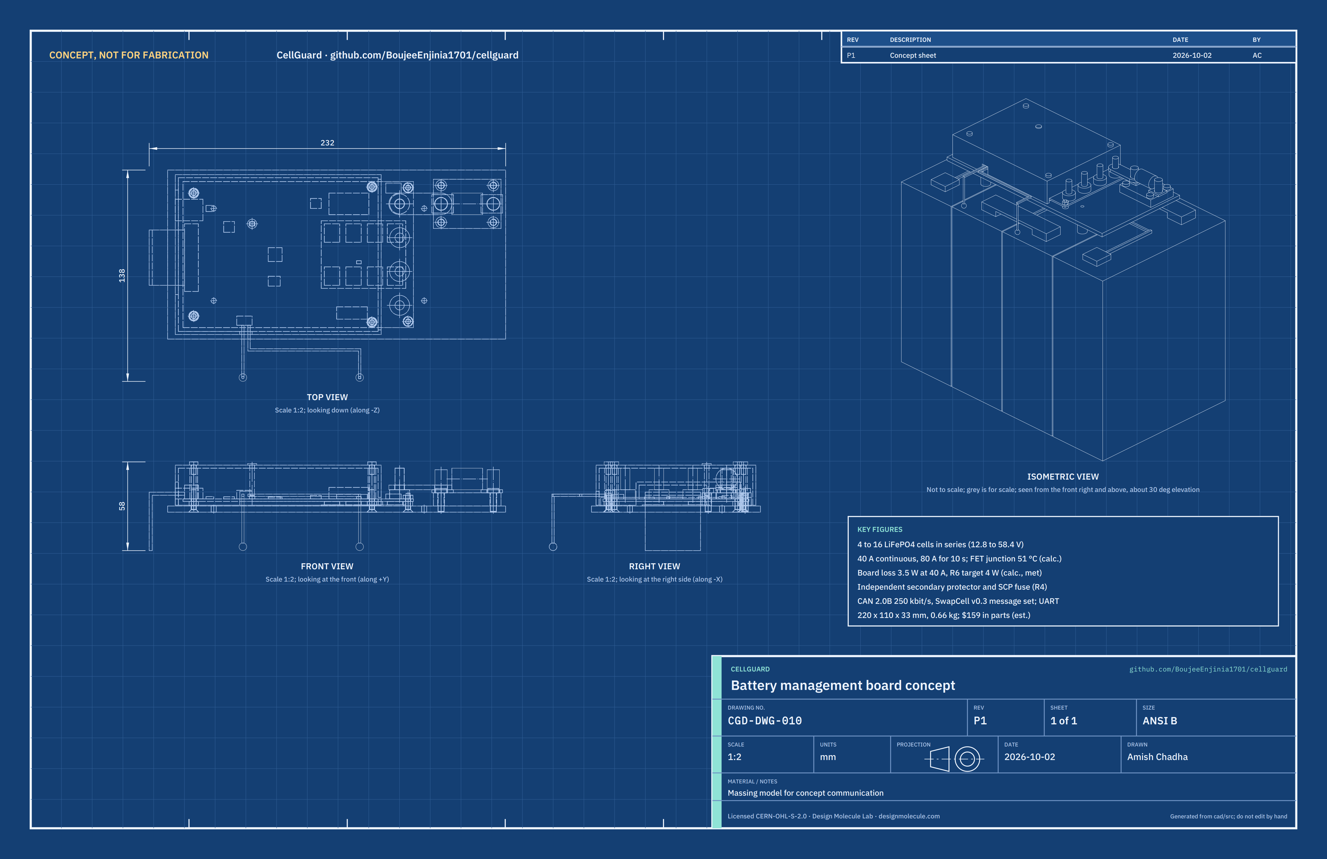
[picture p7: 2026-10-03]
media/concept-blueprint.png

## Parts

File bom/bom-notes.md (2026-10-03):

# BOM notes

- Line numbers 1 to 15, 17, 18 and 19 match the callouts in `media/exploded.png` and the parts in `cad/src/model.py`; for line 15 only the status light is drawn. Line 16 (power cables) is not shown in the model. Lines 17 and 18 were changed and added on 2026-09-30 to make the design buildable (CGD-DDR-003); lines 4, 13 and 15 were respecified and line 19 added on 2026-10-02 to carry Amish's decisions of that day (CGD-DEC-001).
- Every line is priced. Prices are indicative single-unit prices in USD (September and October 2026 estimates) and will change. They exclude cells, tools, shipping and taxes. The basis for each price changed on 2026-10-02 is in the line's notes.
- Total: $159.15 (checked by `docs/04-calcs/sizing.py`, CGD-CAL-001 v0.6 section 11). That is $124.00 as at TRL 2, $10.00 for the secondary protector and SCP fuse (line 14), $2.00 more on line 17 (gap pad, spacers, pillars, screws), $2.00 for the copper fuse link (line 18), then $20.00 more for the 1.5 mΩ-class switches (line 4), $0.35 for the status light (line 15) and $0.80 for the light pipe (line 19).
- Value-engineering target: USD 140.00 (`budget_usd: 140` in `project.yaml`, a hypothetical control target, not a limit; raised from $120 by Amish on 2026-09-25, CGD-DDR-002). Estimated cost of the constructable design: USD 159.15 (USD 19.15 over the target). Against the former $120 target it would be 32.6 % over.
- Lines 3, 6 and 14 follow the choices decided by Amish on 2026-09-25 (CGD-DDR-001, CGD-DDR-002).
- Line 4: 1.5 mΩ-class, 100 V, top-side cooled (TOLT) switches, decided by Amish on 2026-10-02 (CGD-DEC-001) for R6; they bring the board loss at 40 A to 3.47 W (CGD-CAL-001 v0.6). Repriced from $2.50 to $5.00 each: such parts (for example the Infineon IPTC015N10NM5 class, listed by RS Components) are about $4 to $6 each at quantity 10.
- Line 13: printed flame-retardant polycarbonate, opaque for the prototype, with a 3.2 mm hole in the top for the light pipe (CGD-DEC-001, 2026-10-02); sheet aluminium is not used.
- Line 14: an SCP fuse rated for 40 A continuous at 60 V DC or more is not yet confirmed; the price is an estimate.
- Line 15: now includes one three-colour status light (a PLCC-4 RGB LED with three series resistors), $0.35 added (CGD-DEC-001, 2026-10-02).
- Line 19: a round flanged light pipe, 3 mm, pressed into the cover top over the status light, $0.80 (CGD-DEC-001, 2026-10-02).

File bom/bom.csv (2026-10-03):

item | qty | spec | supplier | unit_cost_usd | make_buy | notes
1 Aluminium base plate and heat spreader | 1 | 6061 aluminium, 220 x 110 x 4 mm, flat, drilled, countersunk and tapped (CGD-DDR-003) | Local metal supplier or online cut-to-size service | 10.00 | make | Indicative price; material and machining
2 Main PCB | 1 | 4-layer, 2 oz (70 um) copper, 150 x 95 mm, FR-4 | PCB fabricator (5-board minimum order) | 10.00 | buy | Indicative price per board
3 Cell monitor and protection IC | 1 | TI BQ76952, 3 to 16 cells, TQFP-48 (0.5 mm pitch), integrated high-side NFET driver, coulomb counter, I2C | Electronics distributor (TI or authorized distributor) | 6.50 | buy | Indicative price; decided by Amish (CGD-DDR-001 | CGD-DDR-002)
4 Charge and discharge MOSFETs | 8 | 100 V N-channel, 1.5 mOhm class (1.6 mOhm or less maximum at 25 C), top-side cooled TOLT package (CGD-DDR-002, CGD-DEC-001 2026-10-02), for example Infineon IPTC015N10NM5 class | Electronics distributor | 5.00 | buy | Indicative price; 4 charge and 4 discharge. Repriced 2026-10-02 from $2.50 for the 2.5 mOhm parts: 1.5 mOhm 100 V TOLT parts list at about $4 to $6 each at quantity 10 from authorized distributors (RS Components lists IPTC015N10NM5ATMA1); $5.00 used
5 Current shunt | 1 | 0.25 mOhm, 3 W, metal element, 1 % tolerance, 50 ppm/K or better | Electronics distributor | 2.50 | buy | Indicative price
6 Microcontroller and CAN transceiver | 1 | STM32G0B1 class (LQFP, 0.5 mm pitch) with FDCAN, plus 3.3 V CAN transceiver with low-power standby and bus wake | Electronics distributor | 5.00 | buy | Indicative price; decided by Amish (CGD-DDR-001 | CGD-DDR-002)
7 Precharge resistor and switch | 1 | 100 ohm 10 W aluminium-housed resistor and 100 V P-channel MOSFET in DPAK class (35 W pulse for 0.2 s within SOA), decided (CGD-DDR-002) | Electronics distributor | 3.00 | buy | Indicative price
8 Pack fuse and holder | 1 | 60 A, DC rated 80 V or more, breaking capacity 10 kA or more; holder with an insulating base no larger than 44 x 32 mm, four M4 fixing holes and two M8 terminal studs whose blade faces sit 12.6 mm above its mounting face (CGD-DDR-003) | Electrical distributor | 12.00 | buy | Indicative price
9 Power terminals | 4 | Through-hole soldered brass power terminals with an M6 male stud, 13 mm shoulder 6 mm tall (B+, B-, P+, P-), with nuts, washers and ring lugs | Hardware supplier | 1.50 | buy | Indicative price
10 Balance connector and lead harness | 1 | 17-way latching connector, 16 sense leads with ring terminals and inline protection | Electronics distributor | 8.00 | buy | Indicative price
11 Temperature sensors | 1 | Three 10 kOhm NTC thermistors: two ring-lug probes, one SMD on the board | Electronics distributor | 4.00 | buy | Indicative price for the set
12 CAN and UART connector | 1 | 6-way latching connector (CAN-H, CAN-L, TX, RX, enable, ground) with mating plug | Electronics distributor | 3.00 | buy | Indicative price
13 Flame-retardant cover (opaque) | 1 | Polycarbonate, UL 94 V-0 grade, opaque, 2 mm wall, printed (CGD-DEC-001 2026-10-02); 3.2 mm hole in the top for the light pipe (line 19) | Self (flame-retardant polycarbonate 3D printing filament) | 5.00 | make | Material cost only; opaque prototype cover decided 2026-10-02
14 Secondary protector and SCP fuse | 1 | TI BQ77216 class independent OV, UV, open-wire and temperature protector (TSSOP-24, 0.65 mm pitch), self-control protector fuse rated for 40 A and 60 V DC or more, heater drive MOSFET and passives | Electronics distributor | 10.00 | buy | Indicative price; added for R4 | decided by Amish (CGD-DDR-001 | CGD-DDR-002); SCP rating at 40 A and 60 V to be confirmed
15 Supporting electronics | 1 | 60 V input buck regulator (leaded or SO PowerPAD package), 16 Mbit SPI flash, TVS diode, 16 balance resistors and switches, passives; one three-colour (red, green, blue) status LED in a PLCC-4 package, 3.5 x 2.8 mm, with three series resistors (CGD-DEC-001 2026-10-02) | Electronics distributor | 16.35 | buy | Indicative price; $16.00 before 2026-10-02 plus $0.35 for the status light (a PLCC-4 RGB LED is about $0.20 to $0.30 at quantity 10, three 0603 resistors about $0.05); only the status light is shown in the model
16 Power cables | 2 | 10 mm2 (8 AWG) silicone cable, 0.5 m, with lugs | Electrical distributor | 4.00 | buy | Indicative price; not shown in the model
17 Gap pad and fixings | 1 | 1.0 mm electrically insulating gap pad (3 W/m.K, compresses to 0.7 mm), cut to 55 x 44 mm; 6 round aluminium spacers M3 x 3 mm (6 mm OD); 4 round aluminium pillars M3 female-female x 20 mm (5 mm OD); 6 M3 x 12 countersunk screws; 2 M3 nyloc nuts; 4 M3 x 6 pan-head screws; 4 M4 x 12 pan-head screws for the fuse holder; conformal coating | Hardware supplier | 7.00 | buy | Indicative price; in the model (CGD-DDR-003)
18 Fuse link | 1 | Copper flat bar 14 x 3 mm (C101 or C110), 41 mm long, ends rounded to 7 mm radius, two holes 27 mm apart (6.5 and 8.5 mm), heat-shrink sleeve | Local metal supplier (offcut) | 2.00 | make | Indicative price; joins the B+ stud to the fuse holder (CGD-DDR-003)
19 Light pipe | 1 | Round flanged light pipe, 3 mm diameter, 19.6 mm long below a 6 mm by 1 mm flange, polycarbonate or acrylic, pressed into the cover top over the status light (CGD-DEC-001 2026-10-02) | Electronics distributor | 0.80 | buy | Indicative price; panel-mount round light pipes list at about $0.50 to $1.20 each at quantity 10; cut to length if bought long; in the model

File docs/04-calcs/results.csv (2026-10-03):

quantity | value | unit
LFP pack voltage, 4S nominal | 12.80 | V
LFP pack voltage, 16S nominal | 51.20 | V
LFP pack voltage, 16S maximum | 58.40 | V
MOSFET voltage margin at 16S maximum | 1.71 | x
NMC maximum series count under 60 V | 14 | cells
NMC 13S maximum (SwapCell) | 54.60 | V
PCB copper and stud joints at 20 degC | 0.569 | mOhm
PCB copper and stud joints at 50 degC | 0.635 | mOhm
MOSFET loss at 40 A, 25 degC junction | 1.20 | W
MOSFET loss at 40 A, converged junction (TOLT) | 1.41 | W
Shunt loss at 40 A | 0.40 | W
PCB copper and stud loss at 40 A | 1.02 | W
SCP fuse loss at 40 A (assumed 0.40 mOhm) | 0.64 | W
Board loss at 40 A with SCP (R6) | 3.47 | W
Board loss at 40 A without SCP | 2.83 | W
Board loss at 40 A, 25 degC FETs, with SCP | 3.26 | W
Fuse, holder and links loss at 40 A (external) | 1.60 | W
Total power path loss at 40 A | 5.07 | W
Power path efficiency, 16S at 40 A | 99.75 | %
Plate area, both faces | 0.0484 | m2
Plate temperature rise at 40 A | 10.4 | K
Hottest FET loss at 40 A | 0.213 | W
Extra loss with the former 2.5 mOhm MOSFETs at 40 A | 0.94 | W
FET junction at 40 A, 40 degC, top-cooled TOLT | 51.0 | degC
FET junction at 40 A, 40 degC, TOLL through the mold | 55.4 | degC
Plate heat capacity | 234 | J/K
Plate time constant | 10.1 | min
Extra plate rise, 80 A for 10 s | 0.60 | K
Hottest FET loss at 80 A | 0.97 | W
FET junction after 80 A for 10 s, TOLT (steady bound) | 54.4 | degC
FET junction after 80 A for 10 s, TOLL (steady bound) | 77.6 | degC
SCD threshold (100 mV) | 400 | A
SCD delay set (15 to 450 us available) | 15 | us
OCD1 threshold (24 mV), 320 ms | 96 | A
OCD2 threshold (40 mV), 20 ms | 160 | A
OCC threshold (12 mV) | 48 | A
Smallest SCD step (10 mV) | 40 | A
SCD trip complete (delay plus turn-off) | 25 | us
Board and fuse resistance in the short-circuit loop | 2.97 | mOhm
Power cable resistance, 2 x 0.5 m of 10 mm2 | 1.72 | mOhm
16S 20 Ah: current at FET turn-off, SCD delay 15 us | 679 | A
16S 20 Ah: inductive energy at turn-off, delay 15 us | 0.23 | J
16S 20 Ah: current per discharge MOSFET at turn-off, 15 us | 170 | A
16S 20 Ah: current at FET turn-off, SCD delay 60 us | 875 | A
16S 20 Ah: inductive energy at turn-off, delay 60 us | 0.38 | J
16S 20 Ah: prospective short-circuit current | 891 | A
16S 280 Ah: current at FET turn-off, SCD delay 15 us | 1129 | A
16S 280 Ah: inductive energy at turn-off, delay 15 us | 0.64 | J
16S 280 Ah: current per discharge MOSFET at turn-off, 15 us | 282 | A
16S 280 Ah: current at FET turn-off, SCD delay 60 us | 2555 | A
16S 280 Ah: inductive energy at turn-off, delay 60 us | 3.26 | J
16S 280 Ah: prospective short-circuit current | 4976 | A
4S 280 Ah: current at FET turn-off, SCD delay 15 us | 297 | A
4S 280 Ah: inductive energy at turn-off, delay 15 us | 0.04 | J
4S 280 Ah: current per discharge MOSFET at turn-off, 15 us | 74 | A
4S 280 Ah: current at FET turn-off, SCD delay 60 us | 730 | A
4S 280 Ah: inductive energy at turn-off, delay 60 us | 0.27 | J
4S 280 Ah: prospective short-circuit current | 2102 | A
4S 20 Ah: current at FET turn-off, SCD delay 15 us | 258 | A
4S 20 Ah: inductive energy at turn-off, delay 15 us | 0.03 | J
4S 20 Ah: current per discharge MOSFET at turn-off, 15 us | 65 | A
4S 20 Ah: current at FET turn-off, SCD delay 60 us | 511 | A
4S 20 Ah: inductive energy at turn-off, delay 60 us | 0.13 | J
4S 20 Ah: prospective short-circuit current | 716 | A
Balance current per cell | 103 | mA
Balance power per channel | 0.350 | W
Balance power, 8 channels at once | 2.80 | W
Time to correct 1 % on 20 Ah | 1.9 | h
Time to correct 1 % on 100 Ah | 9.7 | h
Time to correct 1 % on 280 Ah | 27.2 | h
PCB bulk rise while balancing (no plate conduction) | 16.4 | K
PCB bulk temperature at 40 degC ambient | 56.4 | degC
Balance resistor hotspot at 40 degC ambient | 73.9 | degC
Coulomb counter 1 LSB referred to the shunt | 7.60 | uV
Offset current, uncalibrated (1 LSB) | 30.4 | mA
Offset current, calibrated (1 uV) | 4.0 | mA
Front-end gain spread (half range) | 0.57 | %
Gain error uncalibrated (shunt 1 % + front end) | 1.57 | %
Gain error after one-point calibration | 0.50 | %
Current error at 80 A after calibration | 0.404 | A
R9 limit at 80 A | 0.850 | A
SoC error after a full charge (anchor + capacity + 1 cycle gain) | 5.0 | points
SoC error after 7 days, 20 Ah, calibrated offset | 10.1 | points
SoC error after 7 days, 20 Ah, uncalibrated offset | 32.3 | points
SoC error after 7 days, 100 Ah, calibrated offset | 7.4 | points
SoC error after 7 days, 100 Ah, uncalibrated offset | 11.9 | points
SoC error after 7 days, 280 Ah, calibrated offset | 7.0 | points
SoC error after 7 days, 280 Ah, uncalibrated offset | 8.6 | points
SoC error after 5 days (full-charge prompt), 20 Ah, calibrated offset | 8.7 | points
SoC error after 5 days (full-charge prompt), 20 Ah, uncalibrated offset | 24.5 | points
SoC error after 5 days (full-charge prompt), 100 Ah, calibrated offset | 6.7 | points
SoC error after 5 days (full-charge prompt), 100 Ah, uncalibrated offset | 9.9 | points
SoC error after 5 days (full-charge prompt), 280 Ah, calibrated offset | 6.4 | points
SoC error after 5 days (full-charge prompt), 280 Ah, uncalibrated offset | 7.6 | points
Offset allowed for 10 points on 20 Ah over 5 days | 6.2 | mA
Offset allowed for 10 points on 20 Ah | 3.9 | mA
Sleep: Front end SLEEP, DSG on (TI typical) | 41.0 | uA
Sleep: 3.3 V rail loads through the buck | 1.5 | uA
Sleep: Buck regulator quiescent (assumed) | 10.0 | uA
Sleep: Secondary protector (TI typical) | 1.0 | uA
Sleep: TVS leakage (assumed) | 1.0 | uA
Sleep current total | 54.5 | uA
Sleep current with SwapCell INTERLOCK loop (+30 uA) | 84.5 | uA
Ship-mode current total | 6.0 | uA
Self-discharge from sleep, 20 Ah pack | 0.20 | % per month
CAN frames per second (pack and host) | 34.1 | 1/s
CAN bus load at 250 kbit/s | 1.84 | %
Log capacity in 2 MiB flash | 65536 | records
Flash needed for 2,000 records | 64000 | bytes
Precharge time constant | 0.20 | s
Time to 90 % | 0.46 | s
Energy in resistor to 90 % | 3.38 | J
Peak current | 0.584 | A
Peak resistor and switch power | 34.1 | W
Energy into a shorted load in the 1 s timeout | 34.1 | J
Envelope length | 220 | mm
Envelope width | 110 | mm
Envelope height | 33 | mm
Mass: 1 Base plate | 260 | g
Mass: 2 PCB with copper (60 % fill) | 63 | g
Mass: 4 MOSFETs | 6 | g
Mass: 7 Precharge | 8 | g
Mass: 8 Fuse and holder (concept figure, kept until the holder is chosen) | 89 | g
Mass: 9 Studs | 41 | g
Mass: 9 Nuts, washers, lugs (assumed) | 32 | g
Mass: 10 Balance connector and harness (assumed) | 45 | g
Mass: 11 Temperature sensors (assumed) | 10 | g
Mass: 12 CAN and UART connector | 3 | g
Mass: 13 Cover | 57 | g
Mass: 3, 5, 6, 14, 15 Other components (assumed) | 15 | g
Mass: 17 Gap pad, spacers, pillars, screws and nuts | 25 | g
Mass: 18 Fuse link, copper bar | 12 | g
Mass: 15, 19 Status light and light pipe | 0 | g
Mass total without power cables | 0.664 | kg
Mass total with a 3 mm plate | 0.599 | kg
BOM lines | 19
BOM total | 159.15 | USD
BOM total without the secondary protector | 149.15 | USD
Share of budget_usd 140 | 113.7 | %
Margin against budget_usd 140 | -19.15 | USD
Over the value-engineering target of 140 | 19.15 | USD
Against former budget of 120 (before CGD-DDR-002) | 32.6 | % over

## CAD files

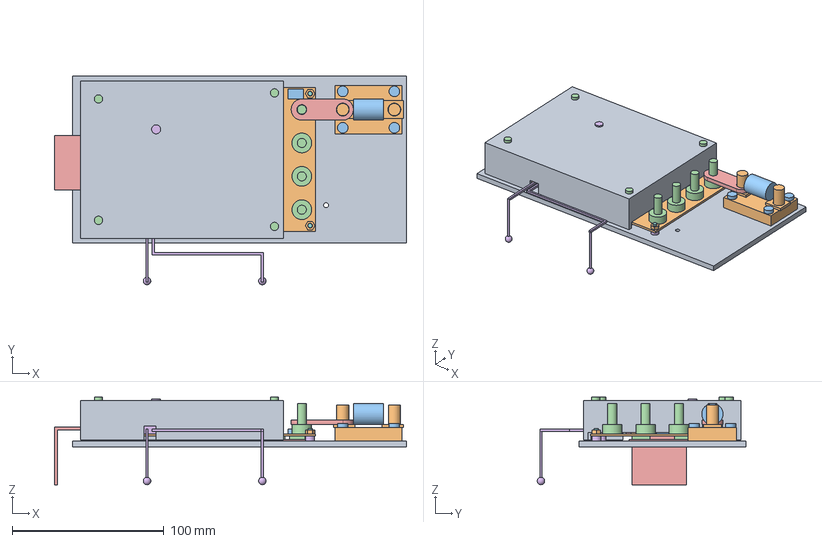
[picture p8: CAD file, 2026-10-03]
cad/step/cellguard-assembly.step
232.0 x 137.5 x 57.7 mm

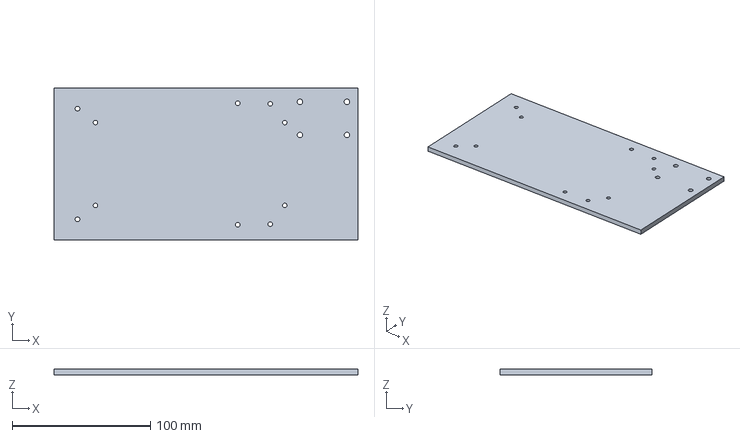
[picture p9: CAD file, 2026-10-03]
cad/step/cellguard-base-plate.step
220.0 x 110.0 x 4.00 mm

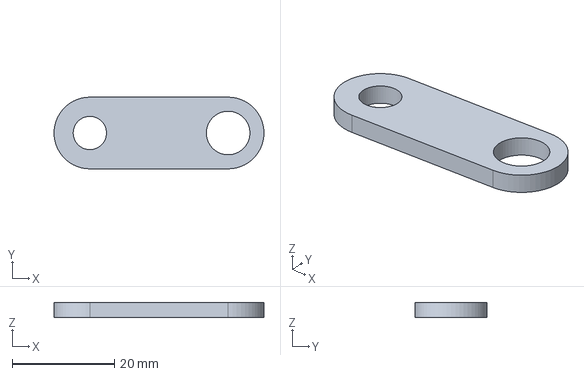
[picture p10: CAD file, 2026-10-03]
cad/step/cellguard-fuse-link.step
41.0 x 14.0 x 3.00 mm

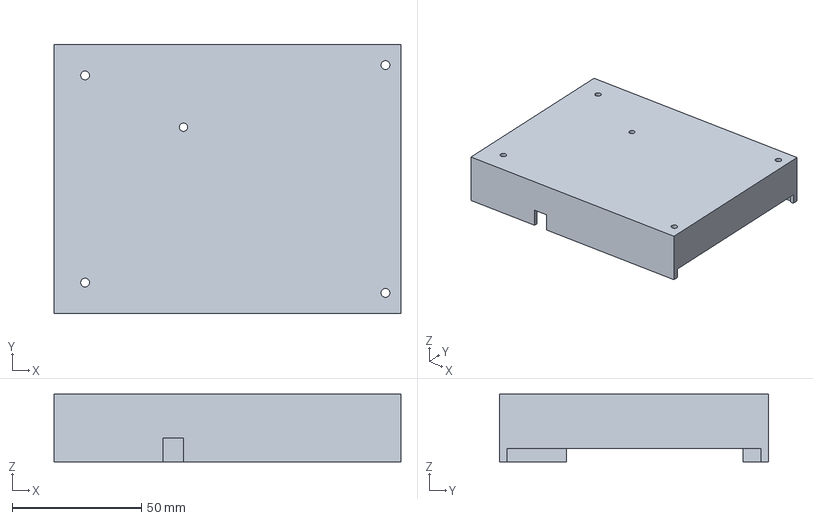
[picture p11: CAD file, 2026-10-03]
cad/step/cellguard-cover.step
134.0 x 104.0 x 26.1 mm

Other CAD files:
cad/stl/cellguard-assembly.stl
cad/stl/cellguard-base-plate.stl
cad/stl/cellguard-cover.stl
cad/stl/cellguard-fuse-link.stl

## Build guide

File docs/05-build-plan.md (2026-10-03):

---
doc_id: CGD-BLD-001
title: CellGuard prototype build plan
project: CellGuard
doc_type: Build plan
version: "0.3"
status: Draft
date: '2026-10-02'
author: Amish Chadha
license: CERN-OHL-S-2.0
revisions:
  - version: "0.1"
    date: '2026-09-30'
    author: Amish Chadha
    change: First build plan, with pictures by component and step; design made constructable (CGD-DDR-003)
  - version: "0.2"
    date: '2026-10-02'
    author: Amish Chadha
    change: "Mass check against the relaxed 0.7 kg R14 target (CGD-DEC-001)"
  - version: "0.3"
    date: '2026-10-02'
    author: Amish Chadha
    change: "Decisions of 2026-10-02 carried into the plan: three-colour status light on the board, opaque cover with a light pipe (new joint picture), 1.5 milliohm-class switches; pictures regenerated; figures from CGD-CAL-001 v0.6"
---

# CellGuard prototype build plan

**Plan, not yet built.** How to build the first proof-of-concept prototype, component by component. Building and testing to it is TRL 4 work. Decisions still to be made are kept in the design decisions register ([docs/06-design-decisions.md](06-design-decisions.md)), not here.

## 1. What you are building

Figure 1. Every component, pulled apart and numbered in build order

*Figure 1. Every component pulled apart and numbered in build order.*

The prototype is one CellGuard board assembly: a flat aluminium plate that spreads heat, a four-layer circuit board held 3 mm above it on six spacers with its eight power switches pressing down on an insulating gap pad, a pack fuse in a bolted holder beside the board, a short copper link from the fuse to the board's B+ stud, and a printed opaque cover over the electronics, with a light pipe that shows the board's three-colour status light. Figure 1 shows the 11 components in the order you make or fit them. Four are made in a small workshop: the plate (cut, drilled, countersunk and tapped), the gap pad (cut from sheet), the copper link (cut and drilled) and the cover (3D printed). The circuit board is ordered from a board maker and populated by hand with a hot plate and soldering iron. Everything else is bought: spacers, pillars, screws, the fuse and holder, the stud terminals, the light pipe, connectors, plugs and probe leads. The parts cost about $159 from the bill of materials.

> **Safety:** CellGuard connects straight to lithium cells. A large pack can drive several thousand amperes into a short circuit, and every exposed stud, busbar and the fuse holder is live once a pack is connected. Do all first power-ups on a cell simulator or a current-limited bench supply, keep the fuse out until section 6 says otherwise, use insulated tools and never leave a test unattended. Printing polycarbonate gives off fumes; print in a ventilated space. Hot-plate soldering uses flux that fumes; use fume extraction.

## 2. What changed to make it buildable

The concept showed what the board does; some of its parts could not be made or fixed as drawn. Each change below keeps what CellGuard does; all of them are recorded in decision record CGD-DDR-003, which Amish accepted on 2026-10-02.

*Table 1. Changes from the concept.*

| Component | The concept had | The buildable design has | Why |
| --- | --- | --- | --- |
| Board supports | Four short posts drawn as part of the plate, with no screws and no holes in the board | A flat plate, six bought 3 mm spacers and six M3 countersunk screws put up from below (Figure 6) | A flat sheet cannot carry posts; the screws hold the board and leave the plate's underside flat |
| Gap under the switches | A 0.5 mm pad that only just filled the gap | A 1.0 mm gap pad squeezed to 0.7 mm by the switches (Figure 8) | The squeeze takes up small height differences, so all eight switches press on the pad |
| Cover | Sat loose on the plate; its openings were closed, so it could not be lowered over the connectors and leads | Rests on four 20 mm pillars and is held by four screws; its openings are notches open at the bottom, and its walls stand 0.5 mm clear of the plate (Figures 12 and 13) | It drops straight down over everything already fitted and cannot rock |
| Board fixings at the power end | Where a nut would hit the B+ stud and the protector fuse | Moved into the corners, 2.2 mm clear of the stud; two more fixings carry the cover pillars (Figure 3) | Every nut and pillar has room |
| Pack fuse | A block on the centre line with no fixing and nothing joining it to the B+ stud | A bolted holder in line with the B+ stud, four M4 screws, and a straight copper link to the stud (Figure 10) | The stud and the fuse terminal are at the same height, so a flat bar joins them |
| Power studs | Drawn as plain cylinders on the board | Bought brass terminals with an M6 stud, soldered through the board (Figure 3) | This is how a board carries 40 A; the shoulder is the face the cables clamp against |
| Mounting the plate | No holes | Four M4 tapped holes, screws from below (Figure 5) | So the board can be fixed to a pack or a vehicle |
| CAN and UART connector | Hung 9 mm off the board edge and crossed the cover wall | Its front face is flush with the cover's outside face, 5 mm past the board edge | Most of its length is on the board |

## 3. Making the components

Make and check each component before the assembly step that needs it. Sizes are in millimetres. The "signal end" is the end with the connectors; the "power end" has the studs and the fuse. "The B+ side" is the side of the centre line where the B+ stud and the fuse sit. Workshop tolerance is 0.2 mm on hole positions and 0.5 mm elsewhere unless a step says otherwise; drawings do not carry tolerances before TRL 4.

### 3.1 Main board

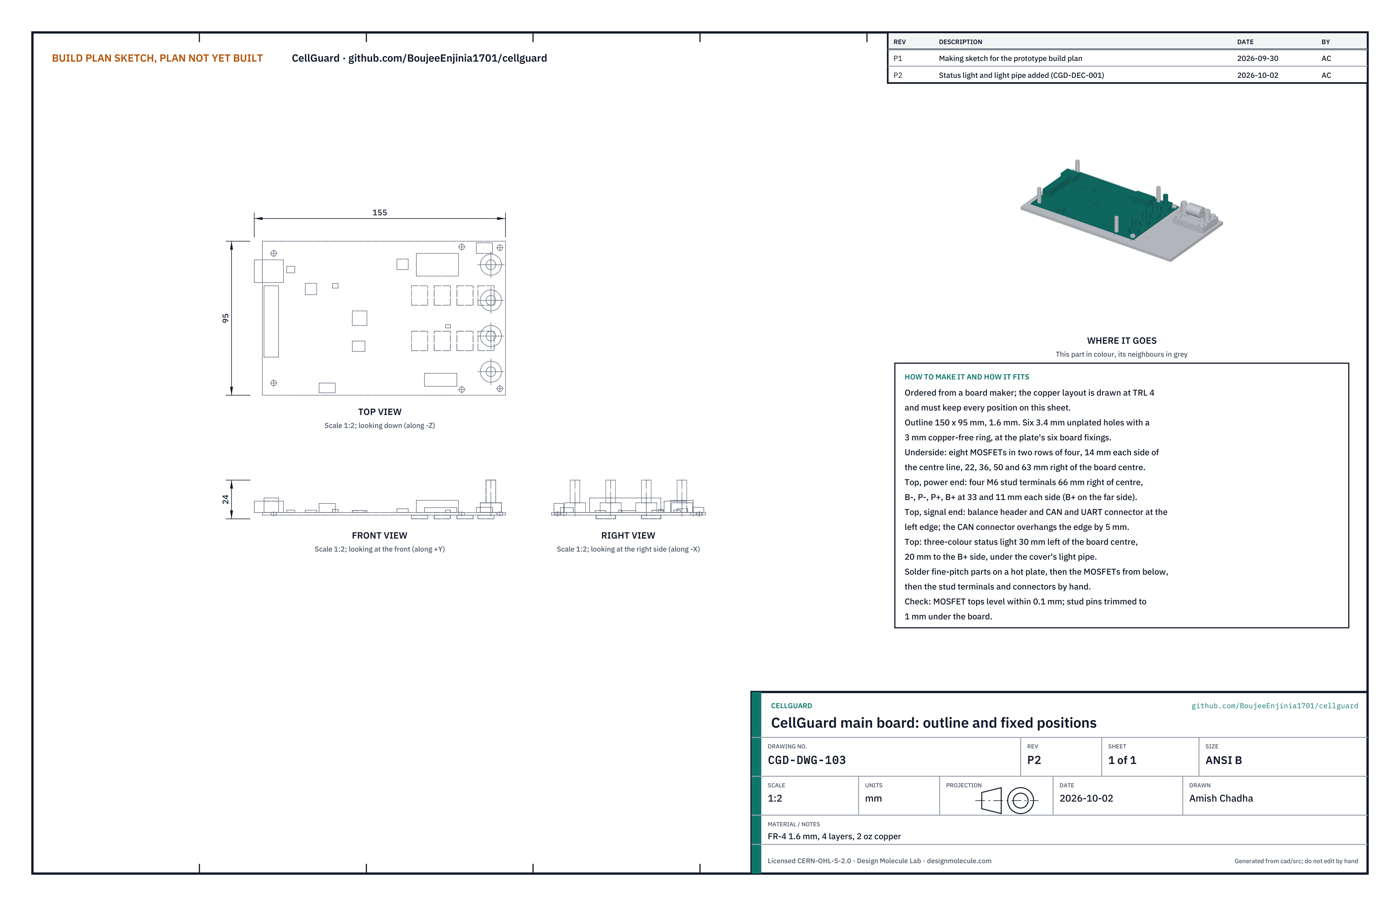
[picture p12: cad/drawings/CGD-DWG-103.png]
Figure 2. Outline and fixed positions of the main board


*Figure 2. Main board outline and fixed positions (CGD-DWG-103). The copper layout is drawn at TRL 4 and keeps every position shown.*

**What it is and what it is made from.** The circuit board that carries the cell monitor and protection chip, the secondary protector, the controller, the current shunt, the precharge parts, the three-colour status light, the connectors and the four power studs on its top face, and the eight power switches on its underside. The switches are 100 V parts of about 1.5 mΩ each in a package cooled through its top face. A four-layer glass-epoxy board 150 x 95 x 1.6 mm with 70 µm (2 oz) copper, ordered from a board maker together with a solder paste stencil for the top face.

**How to make it.**

1. Check the board as delivered: six 3.4 mm unplated fixing holes, each with a 3 mm ring free of copper, at the positions of Figure 2; nothing bent or scratched through the solder mask.
2. Top face, fine-pitch parts: print solder paste through the stencil, place the cell monitor and protection chip, the secondary protector, the controller, the CAN transceiver, the flash memory, the regulator, the shunt, the status light and the small parts. The status light sits 30 mm to the signal-end side of the board centre and 20 mm to the B+ side, where the cover's light pipe comes down over it. Reflow on a hot plate following the paste maker's temperature curve.
3. Inspect every fine-pitch chip under a magnifier for bridges and lifted pins; clear any bridge with flux and braid.
4. Underside: turn the board over on a support that does not touch the top-face parts. Solder the eight power switches in their two rows of four with a hot-air station. Their flat tops must end up level: lay a steel rule across each row and check that no top stands more than 0.1 mm above or below the others.
5. Fit the precharge switch and resistor by hand; hold the resistor down with a bead of high-temperature silicone under its body.
6. Fit the four stud terminals through the board and solder them from below, one at a time, with a large iron. The order across the board, from the side away from the fuse, is B-, P-, P+, B+. Trim their pins to 1 mm below the board.
7. Fit the balance header, the CAN and UART connector (its front face 5 mm past the board edge) and the probe header, and solder them by hand.
8. Wash off flux, dry, and coat the top face with conformal coating, keeping it off the stud shoulders, the connectors and the fixing holes.

**How it fits the parts next to it.**

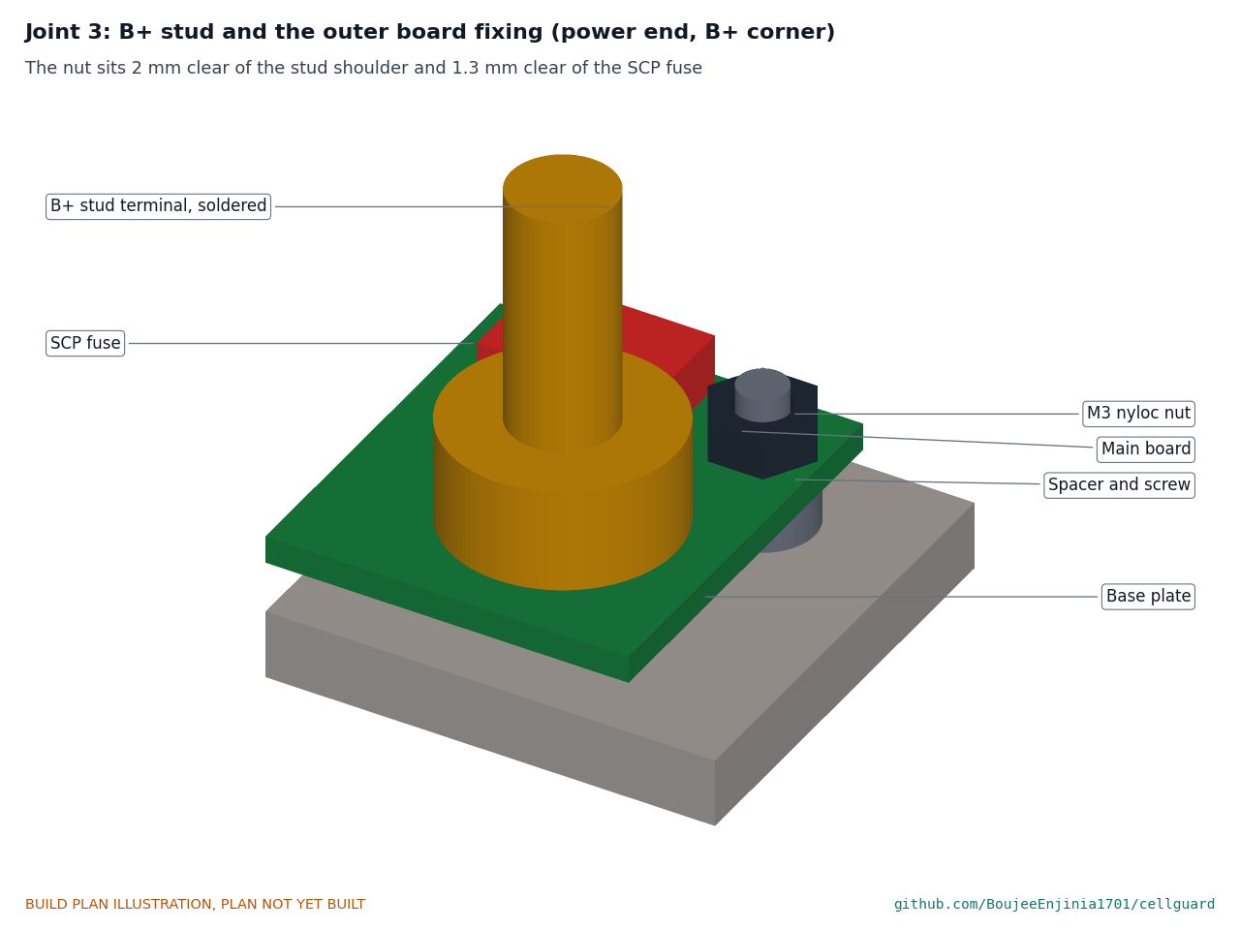
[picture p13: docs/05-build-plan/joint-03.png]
Figure 3. Joint 3: B+ stud and the outer board fixing


*Figure 3. At the power end the board fixing nut sits 2.2 mm clear of the B+ stud's shoulder and 1.3 mm clear of the protector fuse.*

The board lies on six spacers, 3 mm above the plate (Figure 6). The power switches press down on the gap pad (Figure 8). The stud pins, trimmed to 1 mm, stand 2 mm above the plate. Cable lugs and the copper link clamp on the stud shoulders, 10.6 mm above the plate.

**Check before moving on.** Every chip passes the magnifier check; the switch tops are level within 0.1 mm; with no power applied, the resistance from each stud to every other stud reads as the circuit expects and none reads as a short; the board drops over six M3 screws in the plate without forcing.

### 3.2 Base plate

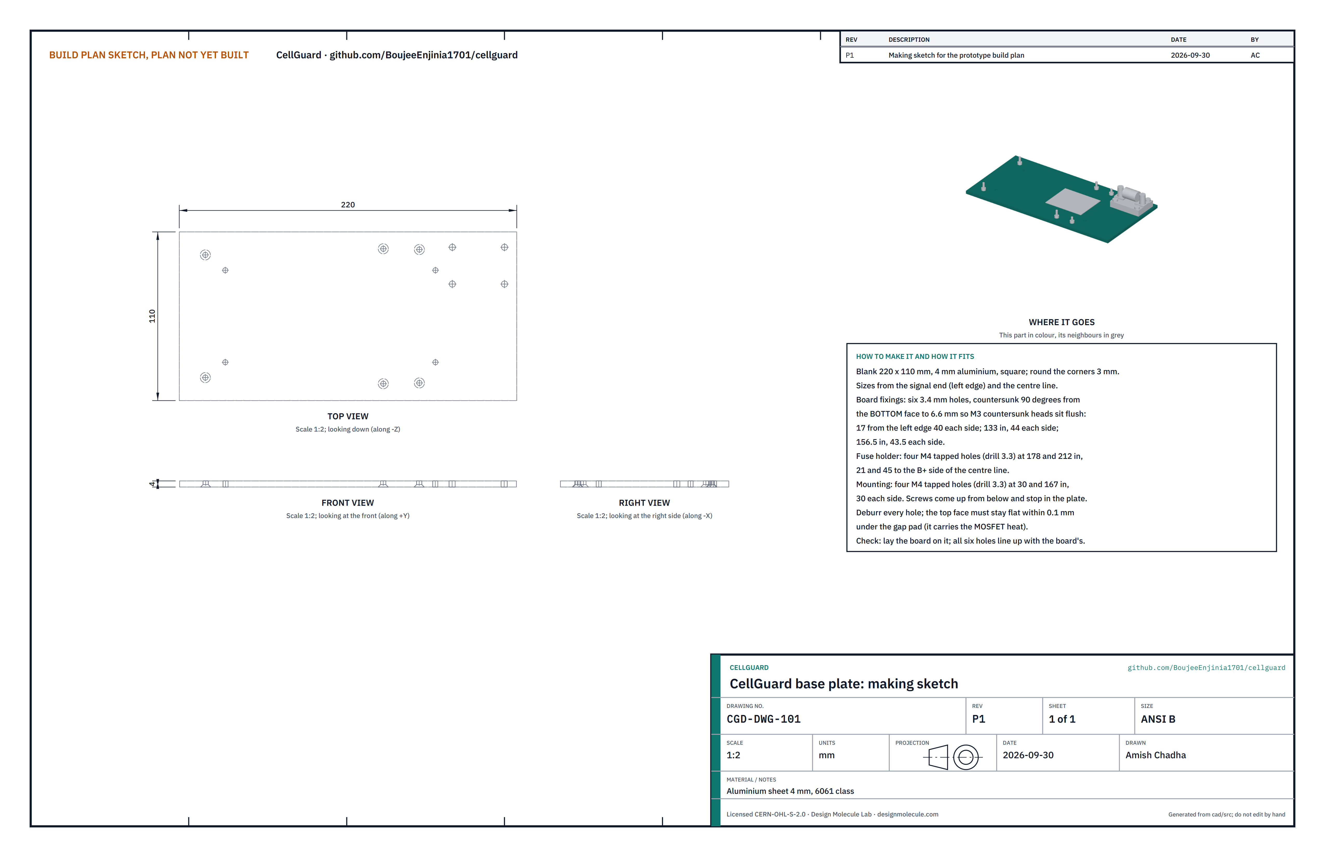
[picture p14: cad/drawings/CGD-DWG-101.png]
Figure 4. Making sketch of the base plate


*Figure 4. Base plate making sketch (CGD-DWG-101).*

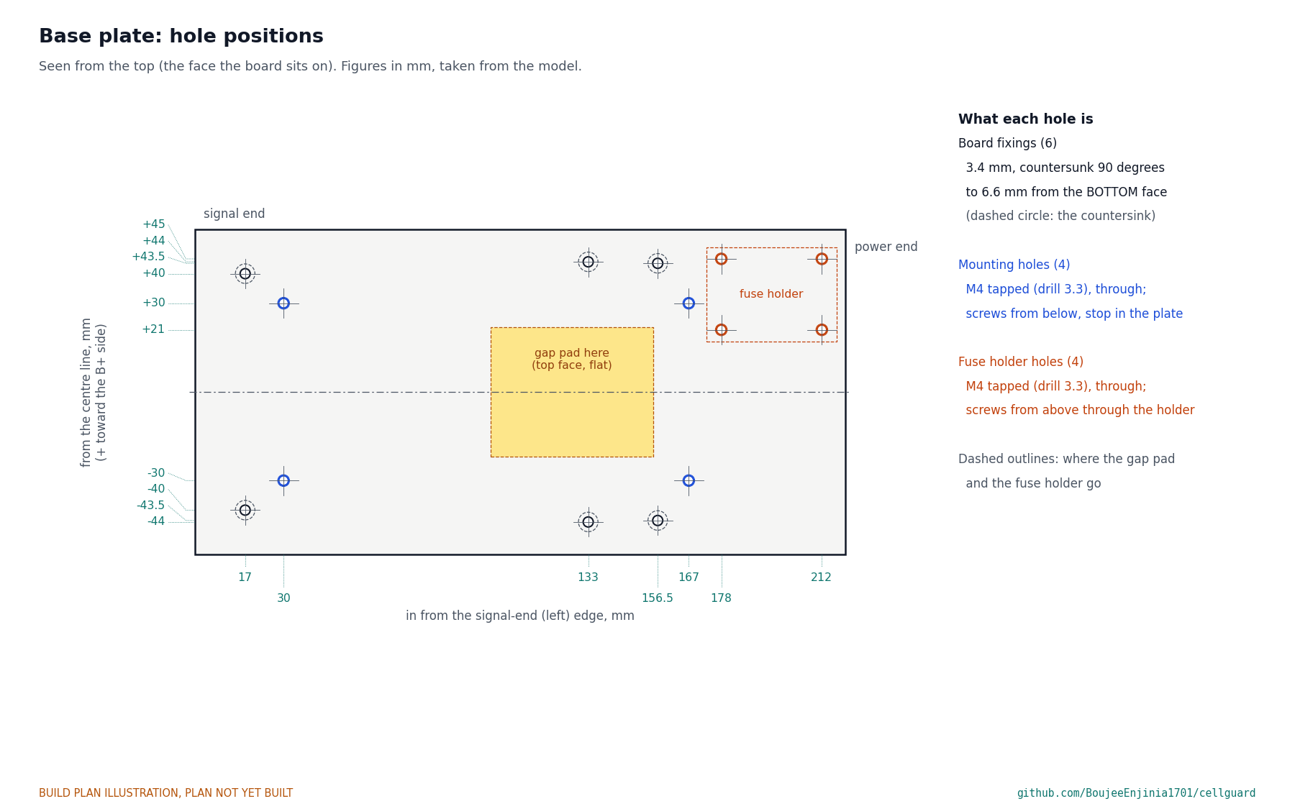
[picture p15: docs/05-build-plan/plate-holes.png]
Figure 5. Hole positions on the base plate


*Figure 5. Every hole, seen from the top, measured in from the signal-end edge and across from the centre line.*

**What it is and what it is made from.** The flat plate that everything sits on. It carries the switches' heat away and holds the fuse holder. Aluminium sheet 4 mm thick, 6061 class, 220 x 110 mm.

**How to make it.**

1. Cut the blank to 220 x 110 mm, square. File the edges and round the corners to about 3 mm.
2. Scribe a centre line along the long side. Choose the flatter face as the top and mark it. Mark the signal end.
3. Mark every hole from Figure 5: distances in from the signal-end edge and across from the centre line.
4. Board fixings: six 3.4 mm holes at 17 mm in, 40 each side; 133 mm in, 44 each side; 156.5 mm in, 43.5 each side. Turn the plate over and countersink each from the bottom face, 90°, to 6.6 mm across, so an M3 countersunk head sits flush.
5. Fuse holder holes: four holes at 178 and 212 mm in, 21 and 45 mm to the B+ side of the centre line. Drill 3.3 mm and tap M4 right through.
6. Mounting holes: four holes at 30 and 167 mm in, 30 mm each side. Drill 3.3 mm and tap M4 right through.
7. Deburr every hole on both faces. Stone the top face under the gap pad area (100 to 155 mm in) so no burr or scratch stands proud.

**How it fits the parts next to it.**

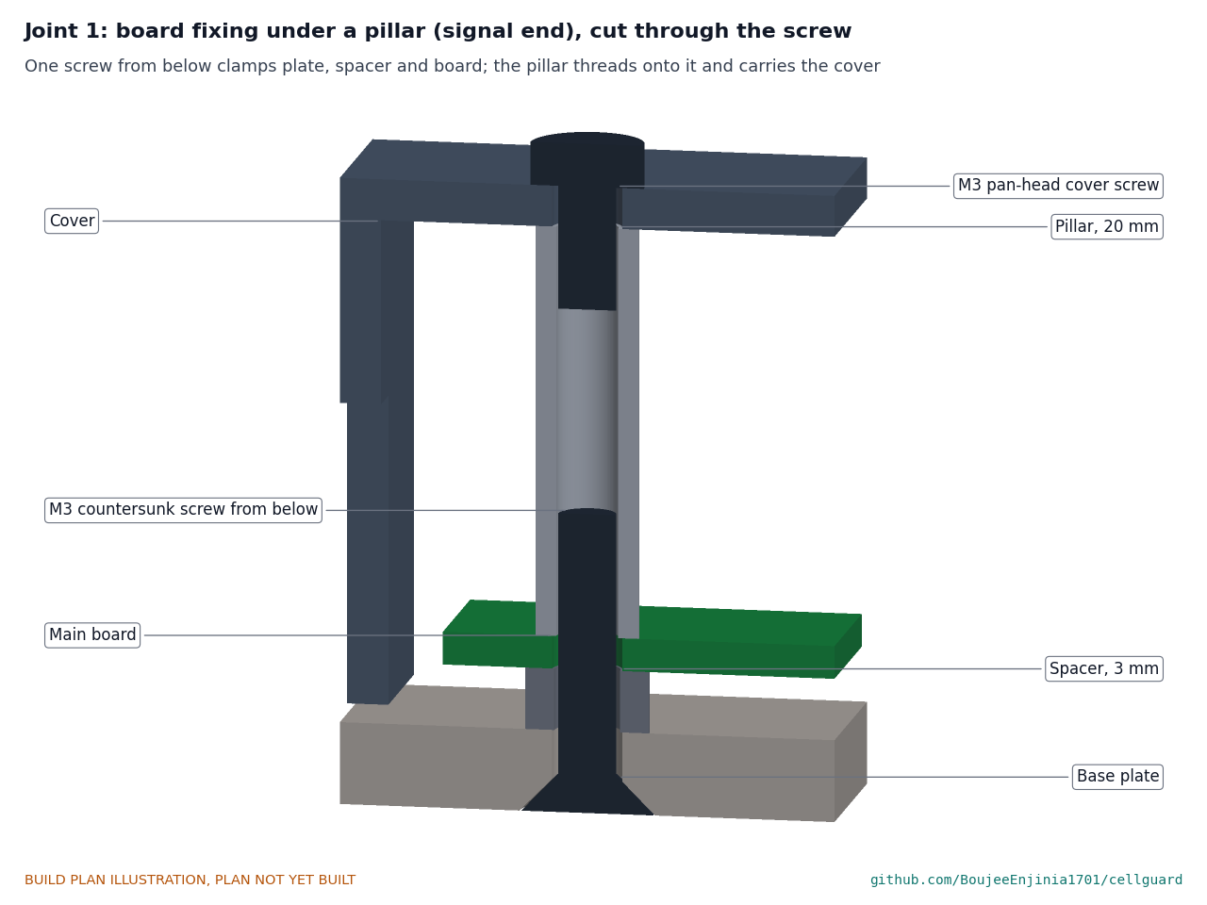
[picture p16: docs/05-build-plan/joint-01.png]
Figure 6. Joint 1: board fixing under a pillar


*Figure 6. One M3 countersunk screw from below clamps the plate, a 3 mm spacer and the board; at four fixings a 20 mm pillar threads onto the same screw and carries the cover.*

The board sits on six spacers on the top face. The gap pad lies on the top face under the switches. The fuse holder sits flat on the top face on its four M4 screws. Screws from the pack or vehicle come up into the mounting holes from below and must stop inside the plate.

**Check before moving on.** A straight edge across the gap pad area shows no gap over 0.1 mm; each countersunk screw sits flush or just below the bottom face; an M4 screw runs freely into every tapped hole; laying the board on the plate, all six holes line up.

### 3.3 Gap pad

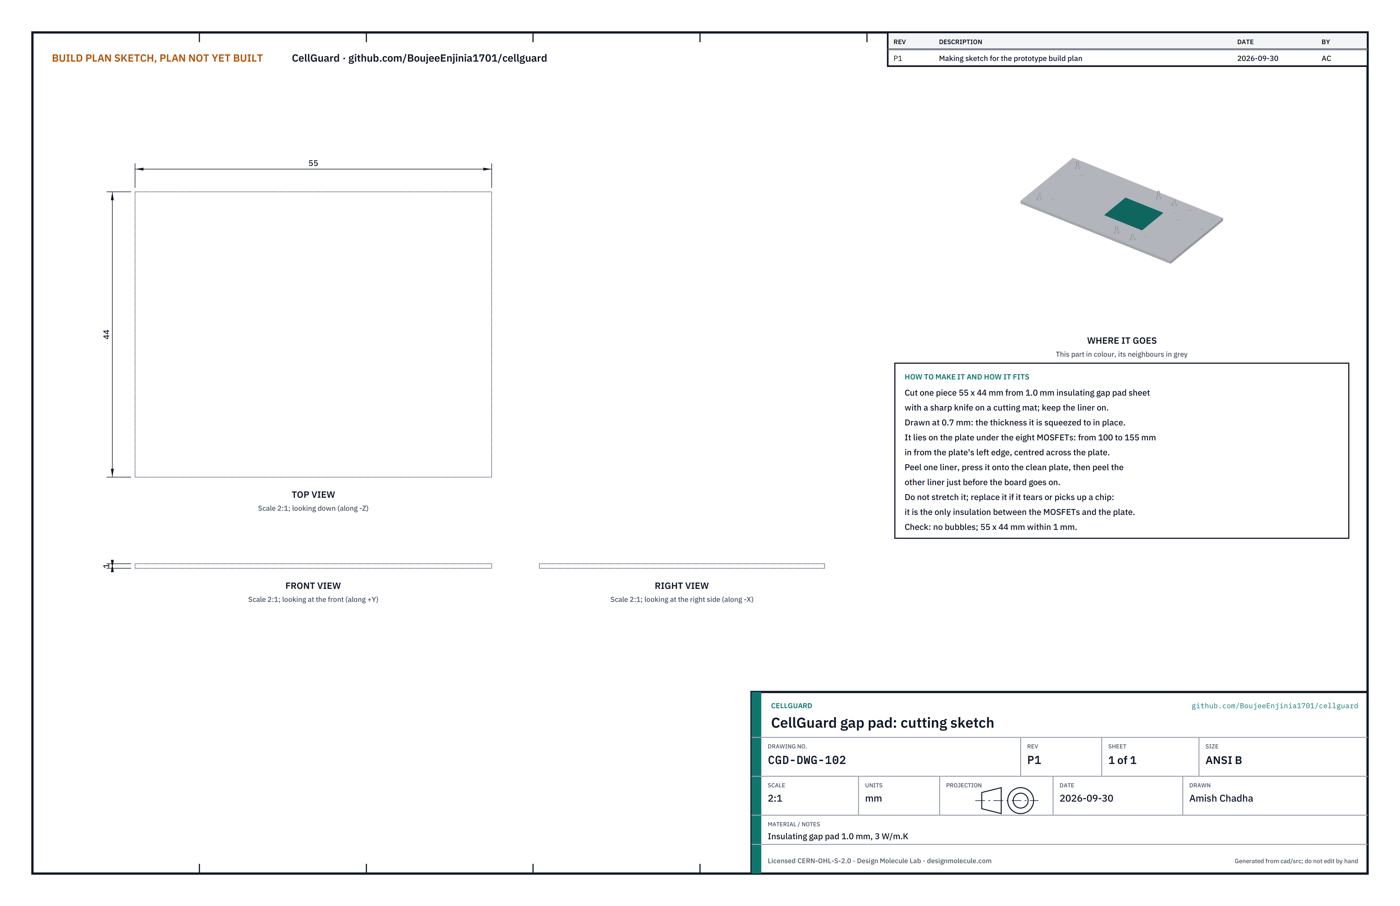
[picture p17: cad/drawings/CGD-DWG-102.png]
Figure 7. Cutting sketch of the gap pad


*Figure 7. Gap pad cutting sketch (CGD-DWG-102), drawn at its squeezed thickness of 0.7 mm.*

**What it is and what it is made from.** The soft, electrically insulating pad between the tops of the eight power switches and the plate. It carries their heat to the plate and is the only insulation between the live switch tops and the aluminium. Gap pad sheet 1.0 mm thick, about 3 W/(m·K), rated for at least 100 V.

**How to make it.**

1. Cut one piece 55 x 44 mm with a sharp knife against a steel rule on a cutting mat. Keep both liners on.
2. Check it for nicks, chips or anything pressed into it; throw away any piece that has one.

**How it fits the parts next to it.**

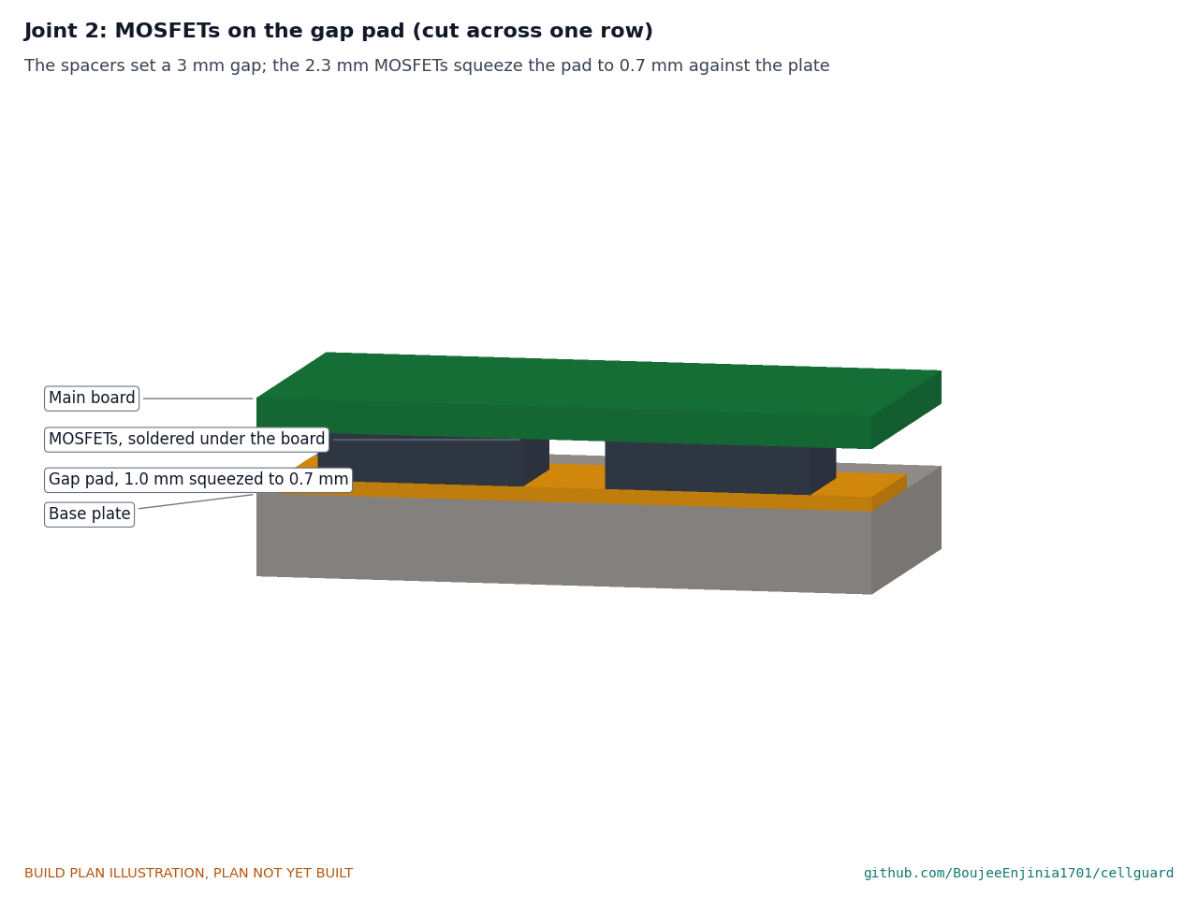
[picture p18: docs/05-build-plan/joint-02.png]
Figure 8. Joint 2: power switches on the gap pad


*Figure 8. The spacers set a 3 mm gap; the 2.3 mm switches squeeze the pad from 1.0 to 0.7 mm against the plate.*

It lies on the plate's top face, 100 to 155 mm in from the signal-end edge, centred across the plate. The switches press down on it when the board is screwed down, squeezing it by about 30 %.

**Check before moving on.** 55 x 44 mm within 1 mm; no tears.

### 3.4 Copper fuse link

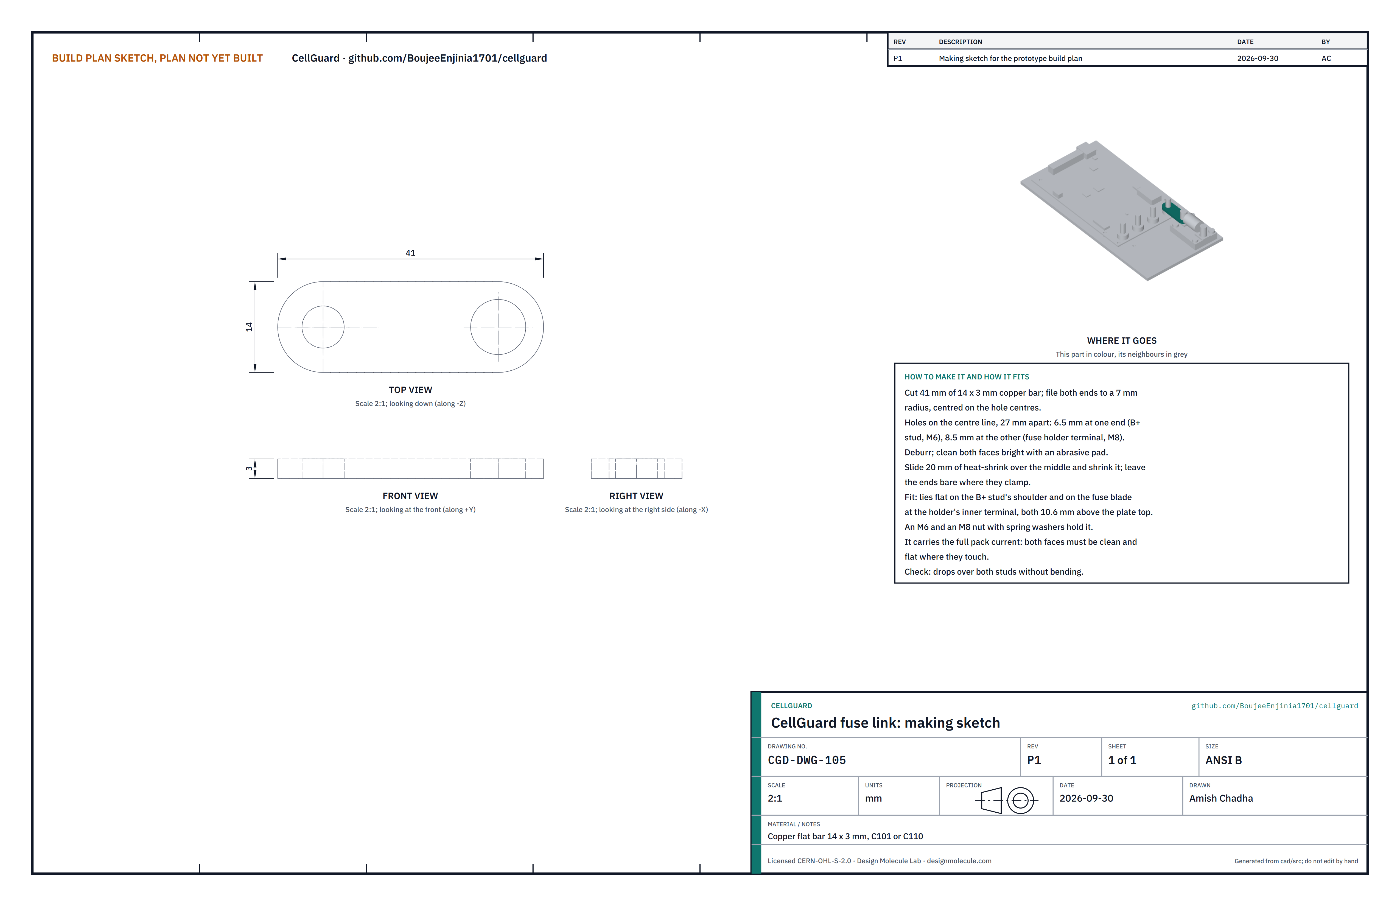
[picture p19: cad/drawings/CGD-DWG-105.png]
Figure 9. Making sketch of the fuse link


*Figure 9. Fuse link making sketch (CGD-DWG-105).*

**What it is and what it is made from.** The flat bar that carries the full pack current from the fuse holder to the board's B+ stud. Copper flat bar 14 x 3 mm, C101 or C110.

**How to make it.**

1. Cut 41 mm of bar and square the ends.
2. On the centre line, mark two hole centres 27 mm apart and 7 mm in from each end. Drill one 6.5 mm (the B+ stud end, M6) and the other 8.5 mm (the fuse holder end, M8).
3. File both ends to a 7 mm radius round the hole centres. Deburr.
4. Clean both faces bright with an abrasive pad where they will clamp.
5. Slide 20 mm of heat-shrink sleeve over the middle and shrink it, leaving both ends bare.

**How it fits the parts next to it.**

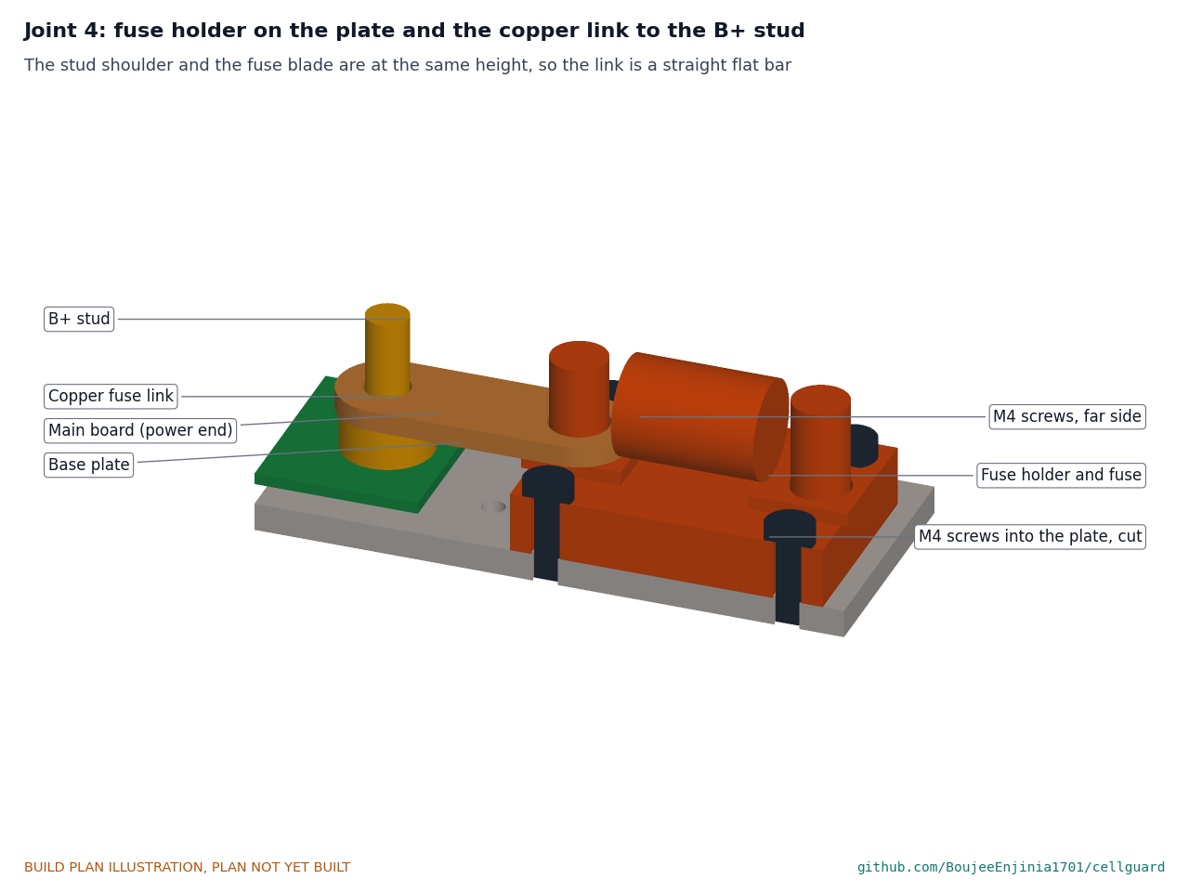
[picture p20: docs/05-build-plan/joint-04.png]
Figure 10. Joint 4: fuse holder and copper link


*Figure 10. The B+ stud's shoulder and the fuse blade on the holder's inner terminal are at the same height, 10.6 mm above the plate, so the link lies flat on both.*

One end lies flat on the B+ stud's shoulder, held by an M6 nut and spring washer; the other lies flat on the fuse blade at the holder's inner terminal, held by an M8 nut and spring washer. It runs 2.8 mm above the protector fuse and 7.5 mm from the P+ stud's cable lug.

**Check before moving on.** Hole centres 27 mm apart within 0.2 mm; the link drops over both studs without bending.

### 3.5 Cover

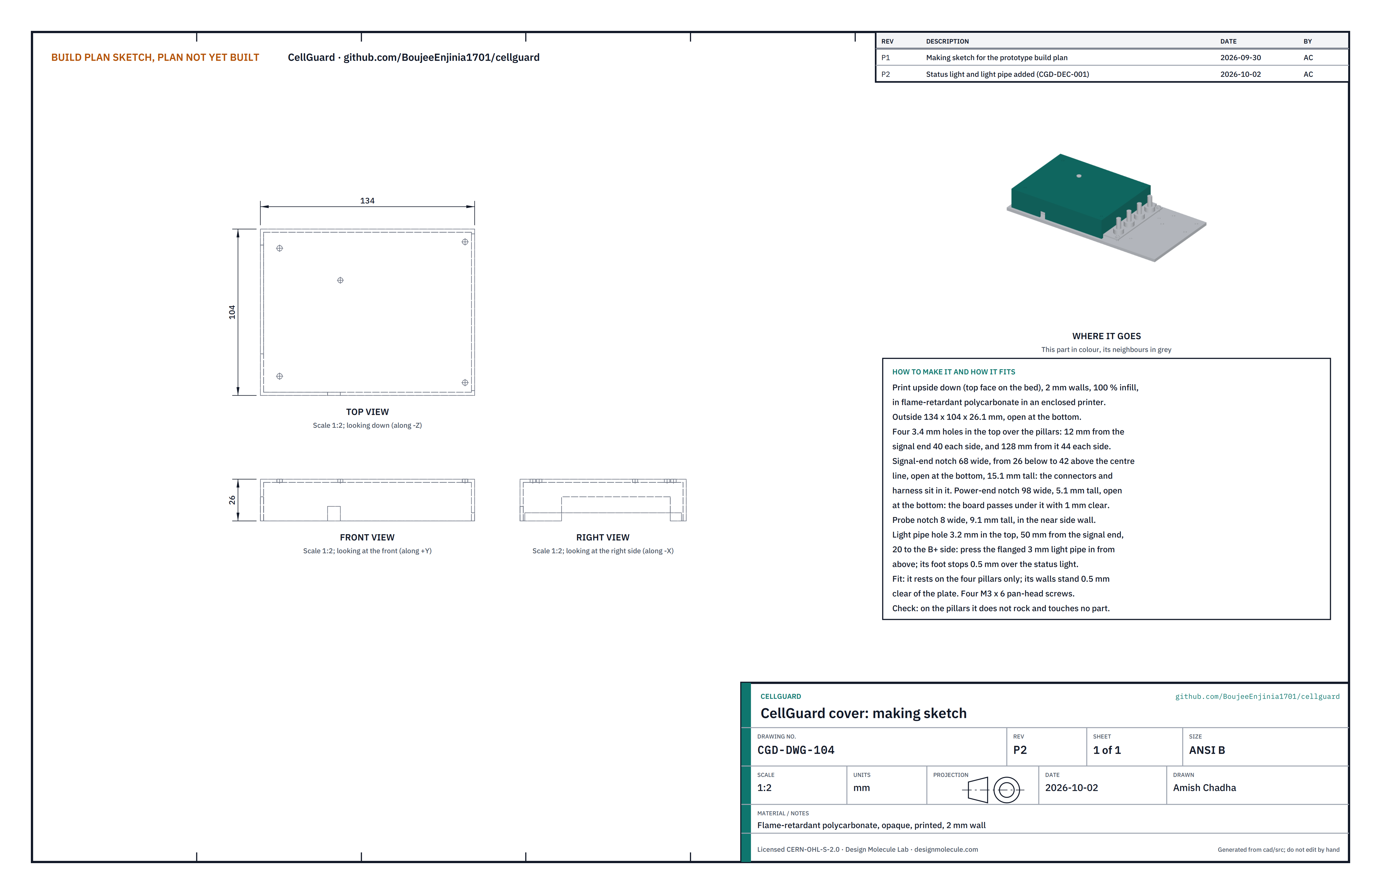
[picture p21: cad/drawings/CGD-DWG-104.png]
Figure 11. Making sketch of the cover


*Figure 11. Cover making sketch (CGD-DWG-104).*

**What it is and what it is made from.** The lid over the electronics, from the signal end to just short of the studs, with a bought light pipe pressed into its top so the status light can be seen. Opaque flame-retardant polycarbonate (UL 94 V-0 grade), printed, 2 mm walls. The light pipe is a round, flanged clear pipe 3 mm across and 19.6 mm long below its flange.

**How to make it.**

1. Print upside down, with the top face on the bed, at 100 % infill, in an enclosed printer that prints polycarbonate. Let it cool on the bed.
2. Check the outside size: 134 x 104 x 26.1 mm.
3. Check the four 3.4 mm holes in the top: 12 mm from the signal-end face at 40 mm each side, and 128 mm from it at 44 mm each side. Open them with a 3.4 mm drill by hand if needed.
4. Check the three notches, all open at the bottom: at the signal end, 68 mm wide and 15.1 mm tall, from 26 mm on the side away from the fuse to 42 mm on the B+ side; at the power end, 98 mm wide and 5.1 mm tall; in the long side away from the fuse, 8 mm wide and 9.1 mm tall, 42 to 50 mm from the signal-end face.
5. Check the 3.2 mm light pipe hole in the top, 50 mm from the signal-end face and 20 mm to the B+ side of the centre line. Open it with a 3.2 mm drill by hand if needed; it must hold the light pipe snugly.
6. Remove strings and sharp edges.
7. Press the light pipe into its hole from above until its flange sits flat on the top face.

**How it fits the parts next to it.**

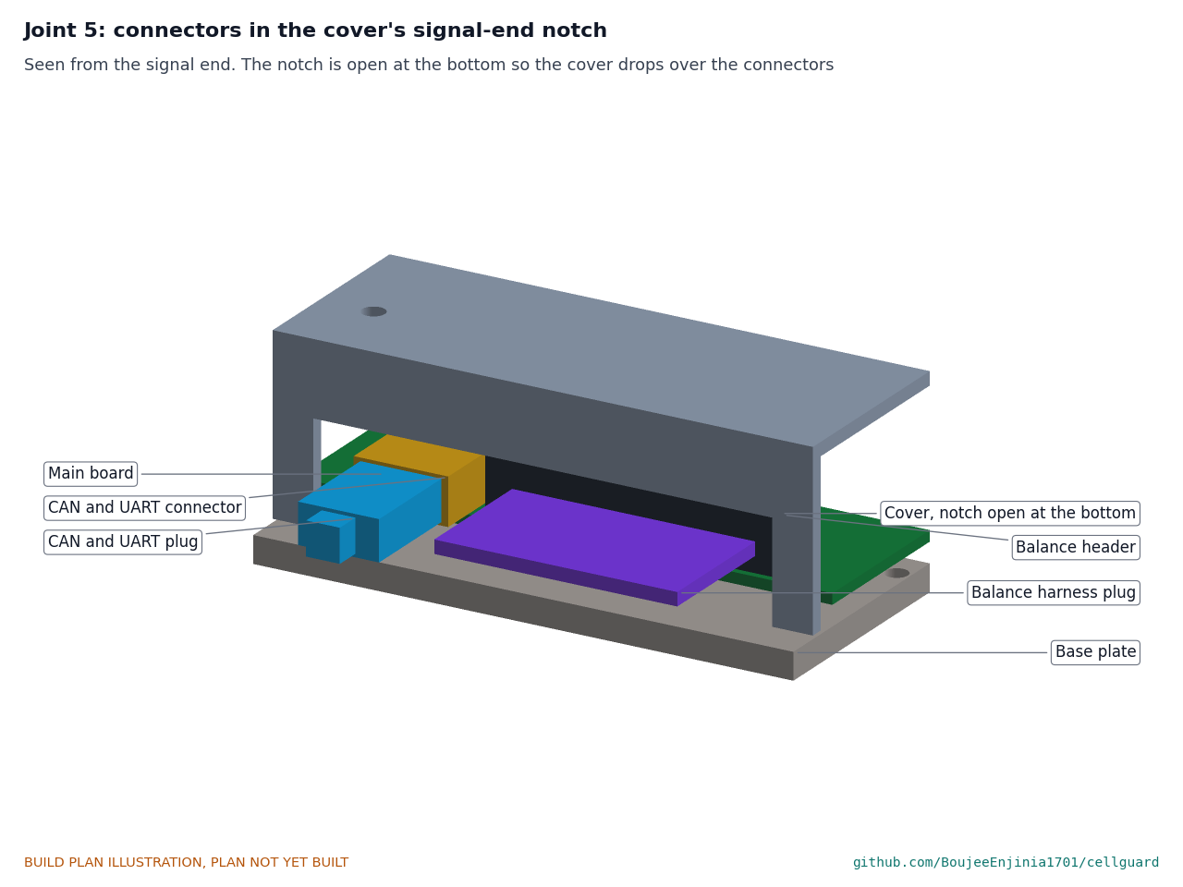
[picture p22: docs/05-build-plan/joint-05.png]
Figure 12. Joint 5: connectors in the signal-end notch


*Figure 12. The connectors, the harness plug and the CAN plug sit in the signal-end notch, which is open at the bottom.*

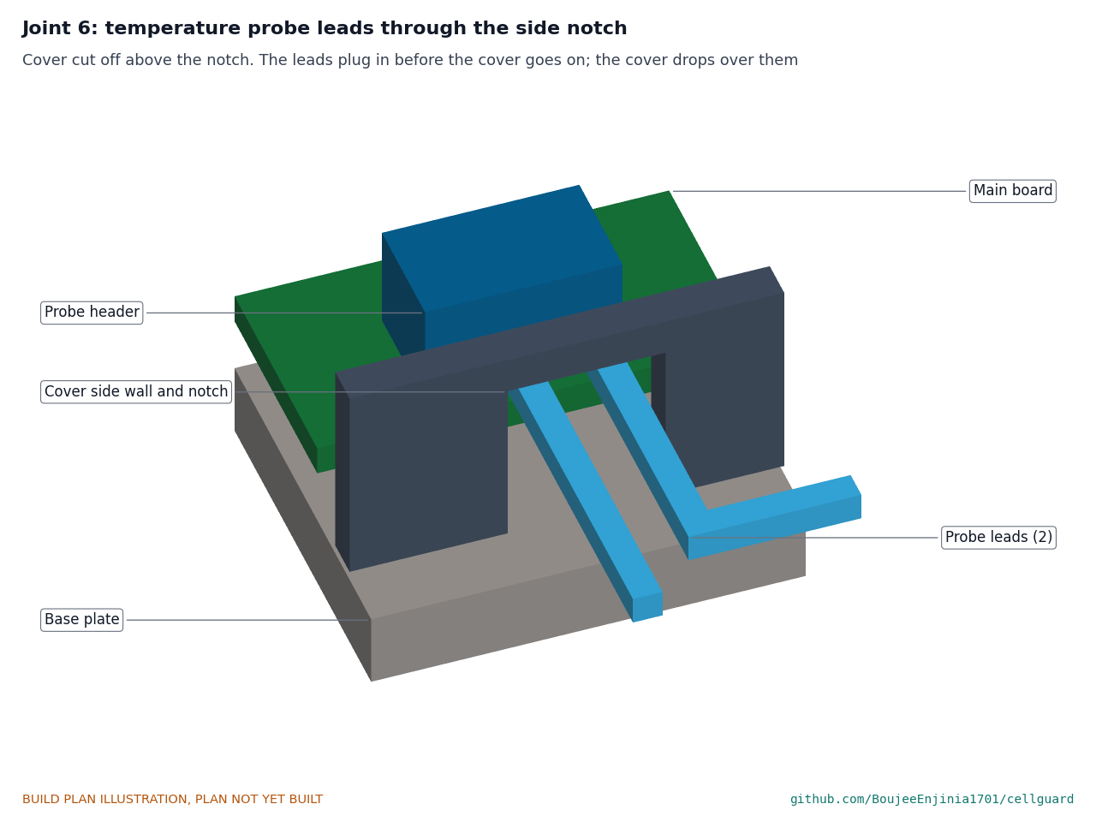
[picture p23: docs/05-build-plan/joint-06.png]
Figure 13. Joint 6: probe leads through the side notch


*Figure 13. The two probe leads leave through the side notch; they are plugged in before the cover goes on.*

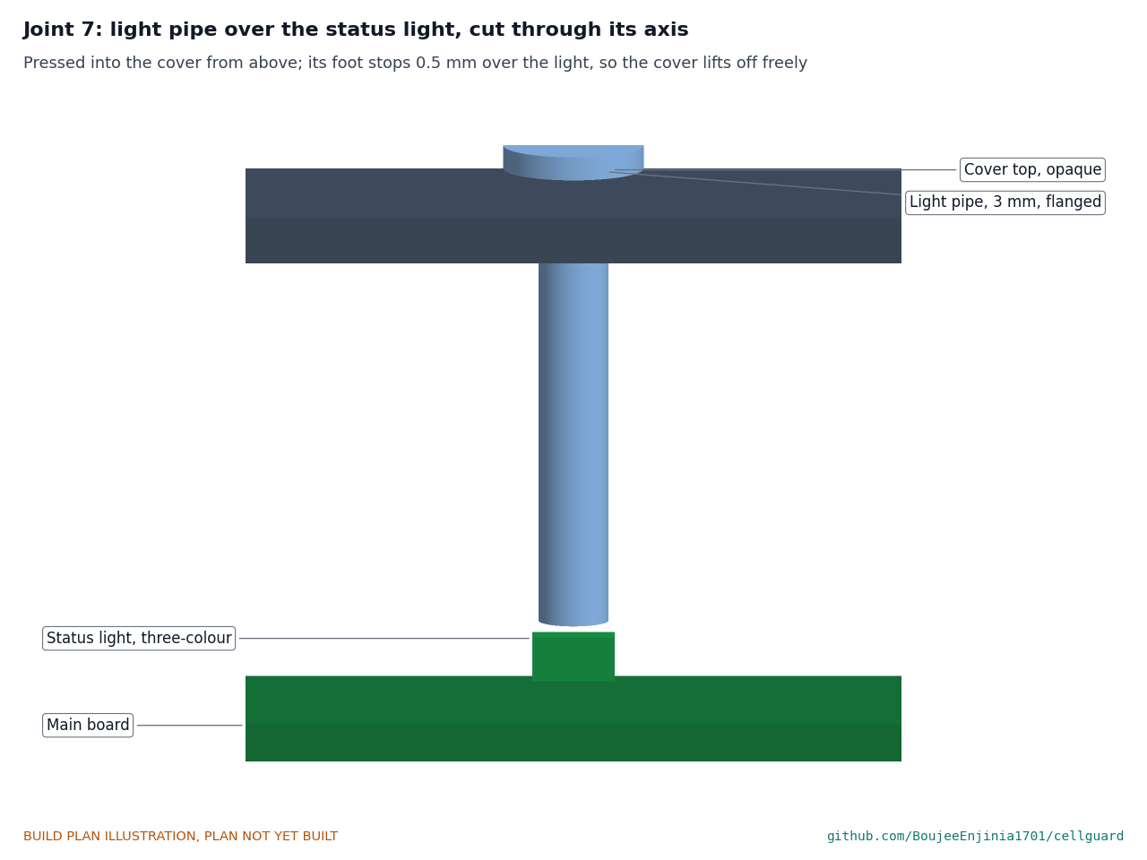
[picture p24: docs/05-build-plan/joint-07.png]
Figure 14. Joint 7: light pipe over the status light


*Figure 14. The light pipe's flange sits on the cover top; its foot stops 0.5 mm above the status light, so the cover lifts off without touching the board.*

The cover rests only on the tops of the four pillars and is held by four M3 x 6 pan-head screws. Its walls stand 0.5 mm clear of the plate. The board passes under the power-end wall with 1 mm to spare. The studs and the fuse stay outside the cover, at least 5.5 mm from it, so cables can be fitted with the cover on. The light pipe stands directly over the status light (Figure 14).

**Check before moving on.** On the pillars of an assembled board it does not rock and touches nothing but the pillar tops; the light pipe flange sits flat on the top face and the pipe stands square to it.

### 3.6 Bought components and connections

Buy to specification, not brand. Line numbers are those of the bill of materials.

- **Electronic parts (lines 3 to 7, 10 to 12, 14, 15).** As listed in the bill of materials, with a mating plug for the balance header and for the CAN and UART connector. The eight power switches are 100 V, about 1.5 mΩ each, in a 2.3 mm tall package cooled through its top face; the status light is one three-colour light in a 3.5 x 2.8 mm package.
- **Light pipe (line 19).** A round, flanged light pipe 3 mm across, 19.6 mm long below a flange about 6 mm across and 1 mm thick. Cut a longer one to length with a fine saw and polish the cut end.
- **Pack fuse and holder (line 8).** 60 A fuse, DC rated 80 V or more, breaking capacity 10 kA or more. Holder with an insulating base no larger than 44 x 32 mm, four M4 fixing holes, two M8 terminal studs, and the fuse blade faces 12.6 mm above its mounting face (10.6 mm above the plate top once fitted).
- **Power terminals (line 9).** Four through-hole soldered brass terminals with an M6 stud and a 13 mm shoulder 6 mm tall, with nuts, spring washers and ring lugs.
- **Gap pad and fixings (line 17).** Gap pad sheet as section 3.3; six round aluminium spacers M3 x 3 mm, 6 mm across; four round aluminium pillars M3 female-female x 20 mm, 5 mm across; six M3 x 12 countersunk screws; two M3 nyloc nuts; four M3 x 6 pan-head screws; four M4 x 12 pan-head screws; conformal coating.
- **Power cables (line 16).** 10 mm² (8 AWG) silicone cable with ring lugs: from the pack's B+ to the holder's outer terminal (M8), from the pack's B- to the B- stud, and from the P+ and P- studs to the load or charger (M6).

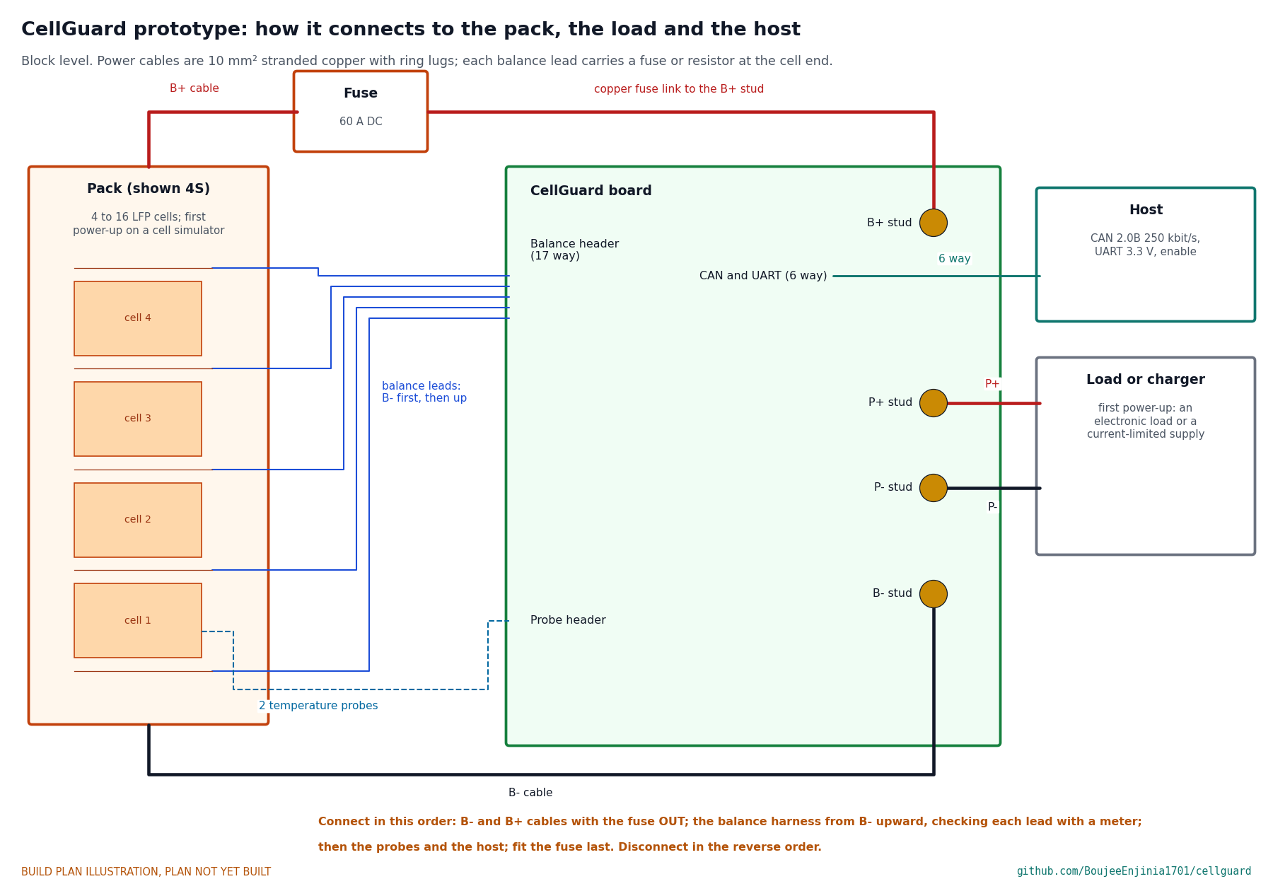
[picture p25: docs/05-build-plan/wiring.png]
Figure 15. How the board connects to the pack, the load and the host


*Figure 15. Connections at block level, with the order in which they are made.*

## 4. Putting it together

In each picture the parts already fitted are grey and the part being fitted is in colour, with an arrow showing the way it goes in.

### Step 1: populate the main board

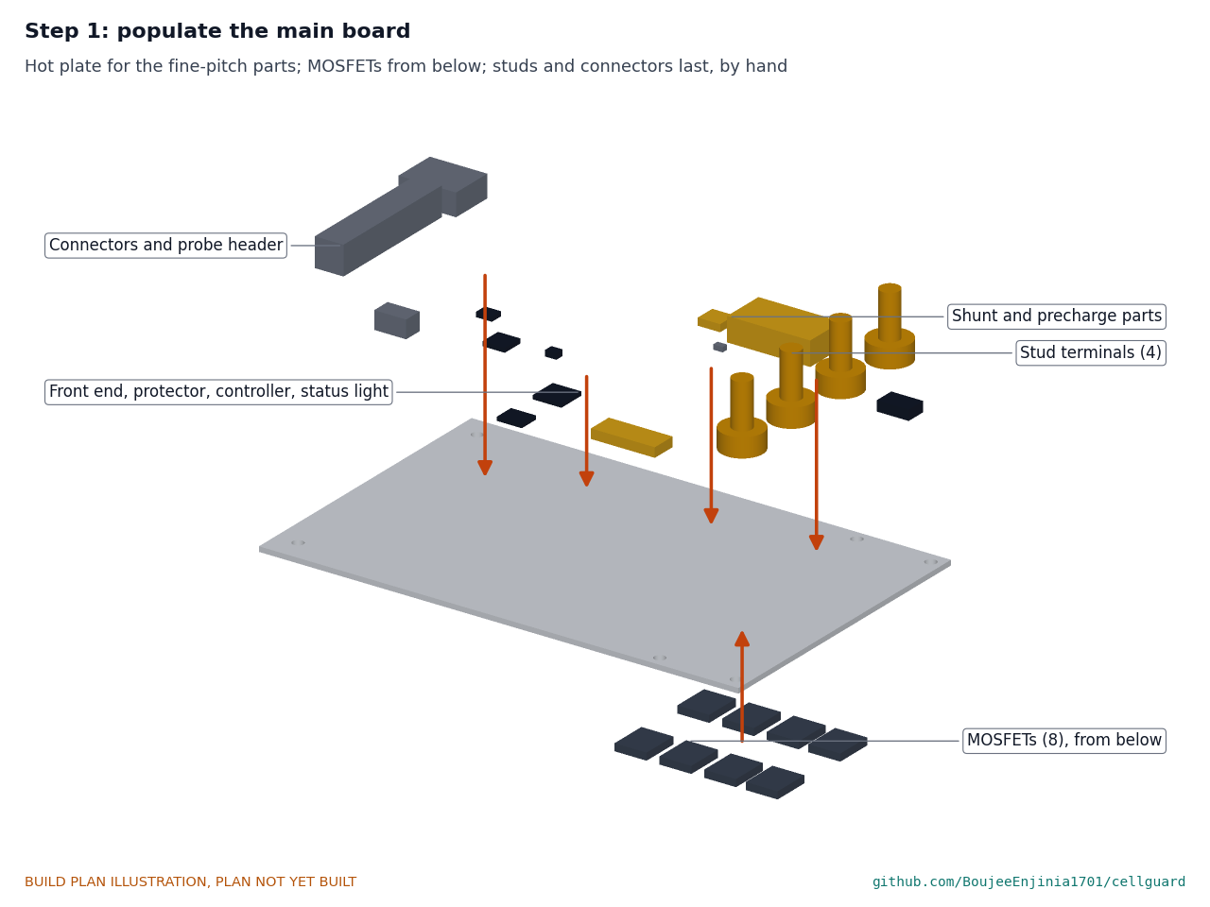
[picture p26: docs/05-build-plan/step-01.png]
Step 1


As section 3.1: fine-pitch parts on the top face on a hot plate, then the eight switches on the underside, then the stud terminals and connectors by hand. **Hold point:** the checks of section 3.1 pass before going on.

### Step 2: gap pad onto the base plate

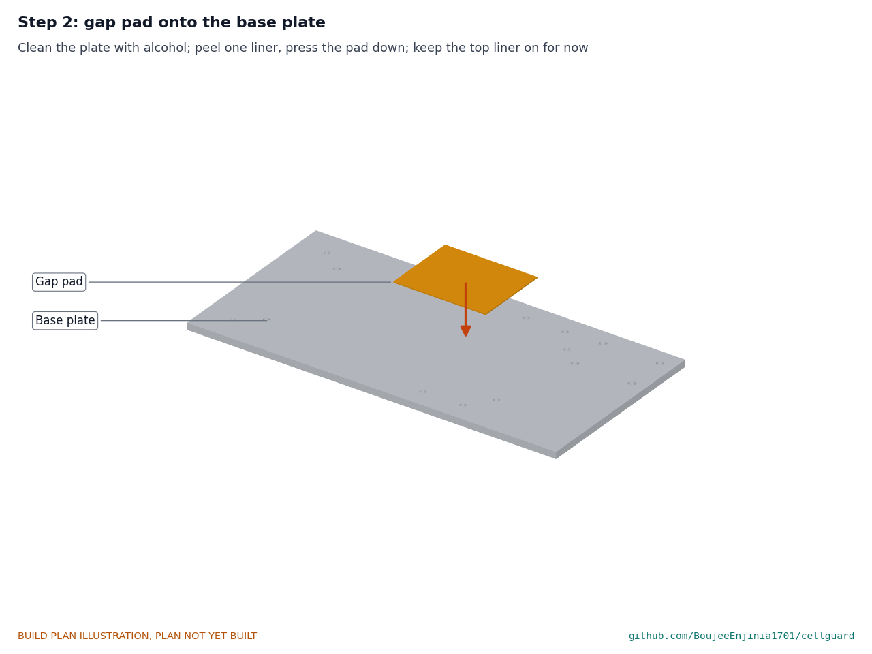
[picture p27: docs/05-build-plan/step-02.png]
Step 2


Clean the plate's top face with isopropyl alcohol. Peel one liner from the pad and press it down in its place, from the middle outward so no air is trapped. Leave the top liner on.

### Step 3: board screws and spacers

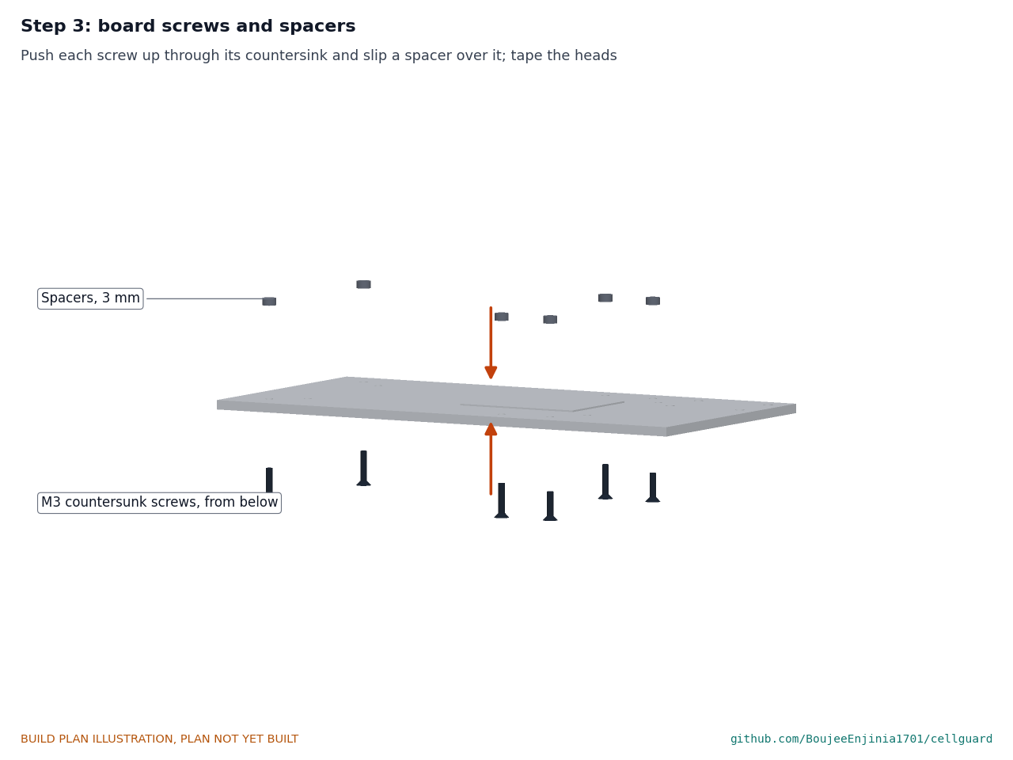
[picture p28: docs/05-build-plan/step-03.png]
Step 3


Push an M3 x 12 countersunk screw up through each of the six countersunk holes from below and slip a 3 mm spacer over each. Lay the plate on a flat block with clearance for the screw heads, or tape the heads, so the screws stay in.

### Step 4: main board onto the spacers

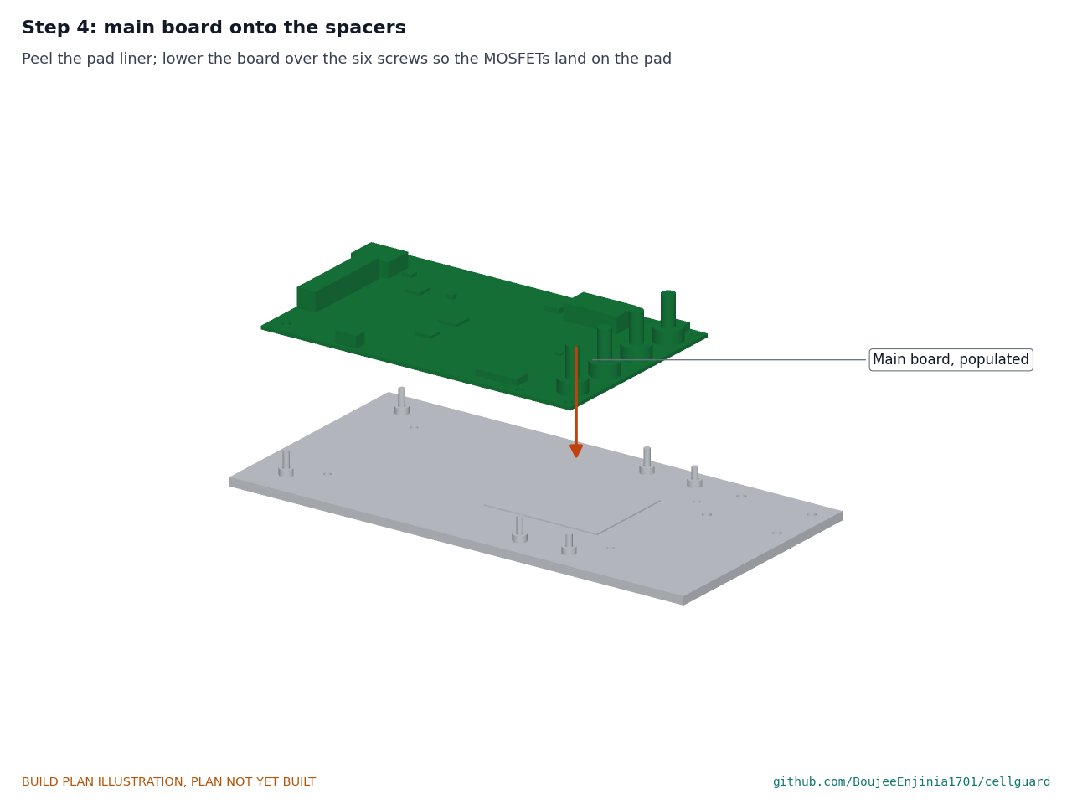
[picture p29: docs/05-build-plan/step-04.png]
Step 4


Peel the pad's top liner. Lower the board straight down over the six screws, studs toward the power end, so the switches land on the pad. Do not slide it on the pad.

### Step 5: pillars and nuts

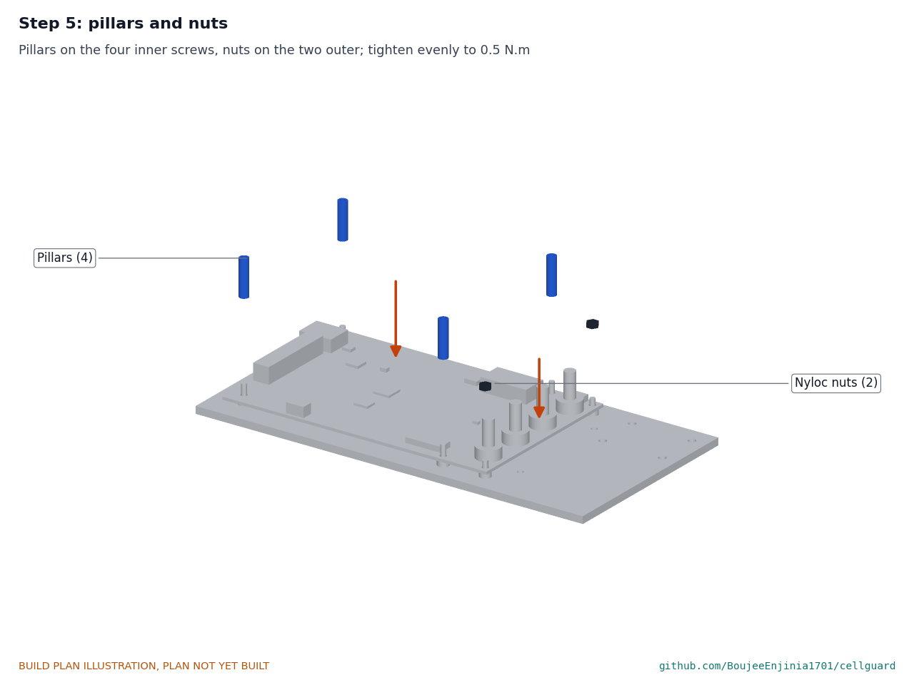
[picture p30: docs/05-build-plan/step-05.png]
Step 5


Thread a 20 mm pillar onto each of the four inner screws (at the signal end and beside the precharge resistor and shunt) and a nyloc nut onto each of the two corner screws at the power end. Tighten all six evenly, a little at a time in a cross pattern, to about 0.5 N·m, holding each screw head from below.

### Step 6: fuse holder onto the plate

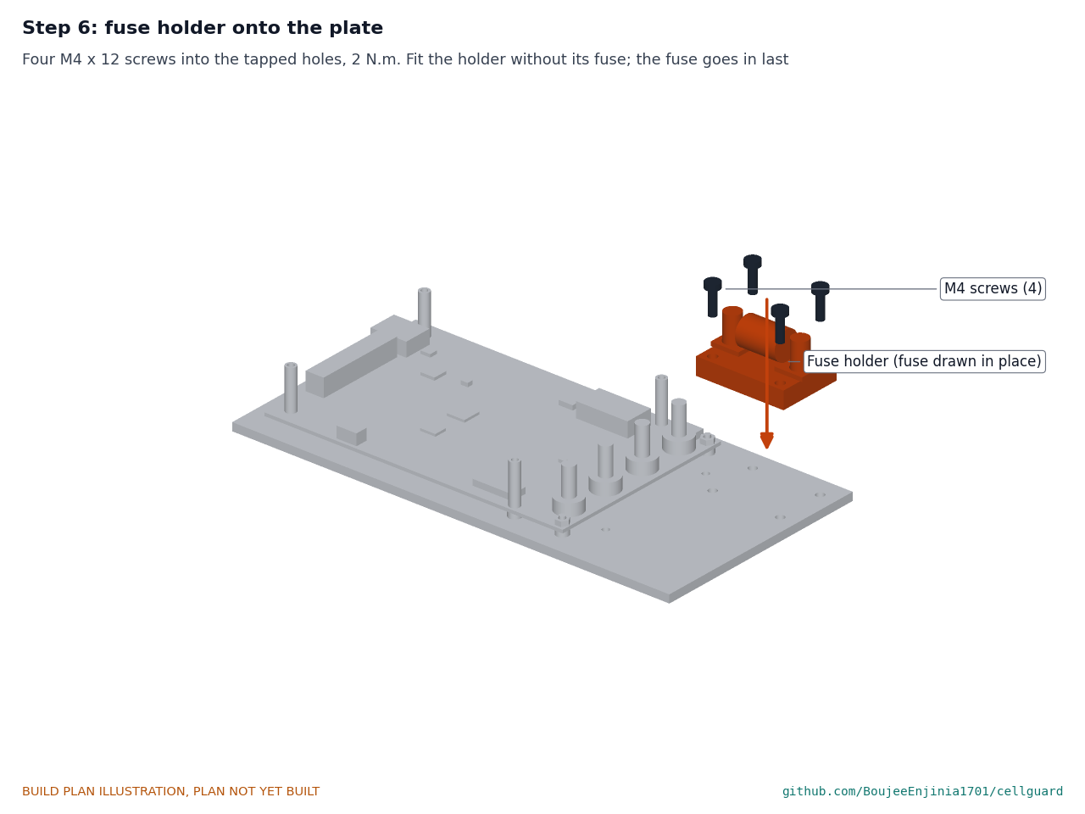
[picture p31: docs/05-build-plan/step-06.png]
Step 6


Fit the holder without its fuse, on the B+ side at the power end, with four M4 x 12 screws into the tapped holes, about 2 N·m. The fuse goes in last (section 6).

### Step 7: fuse link

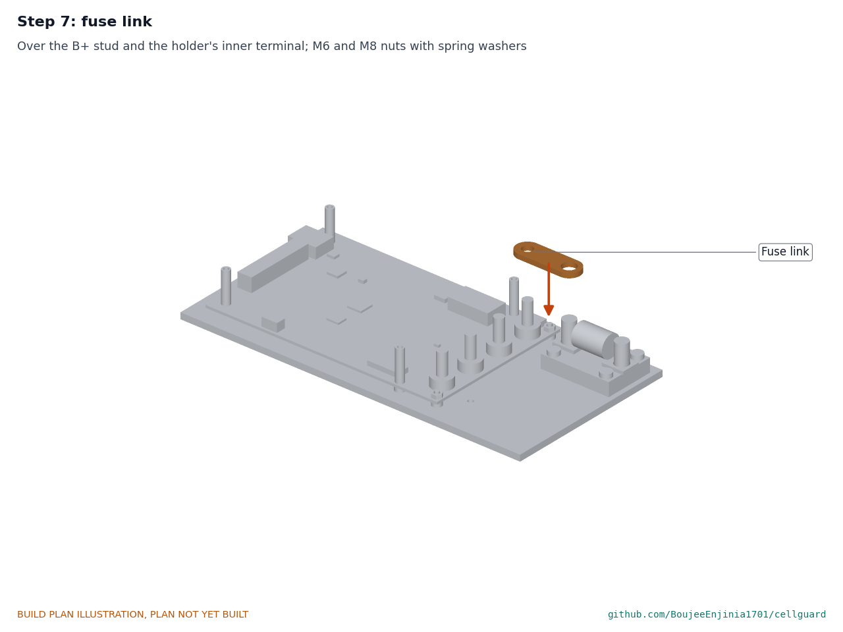
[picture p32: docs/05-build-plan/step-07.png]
Step 7


Lay the link over the B+ stud and the holder's inner terminal stud. Fit an M6 nut with spring washer on the B+ stud and an M8 nut with spring washer on the holder terminal, to the stud and holder makers' torques. Hold the B+ stud's shoulder with a spanner while tightening so no twist reaches the solder joints.

### Step 8: temperature probe leads

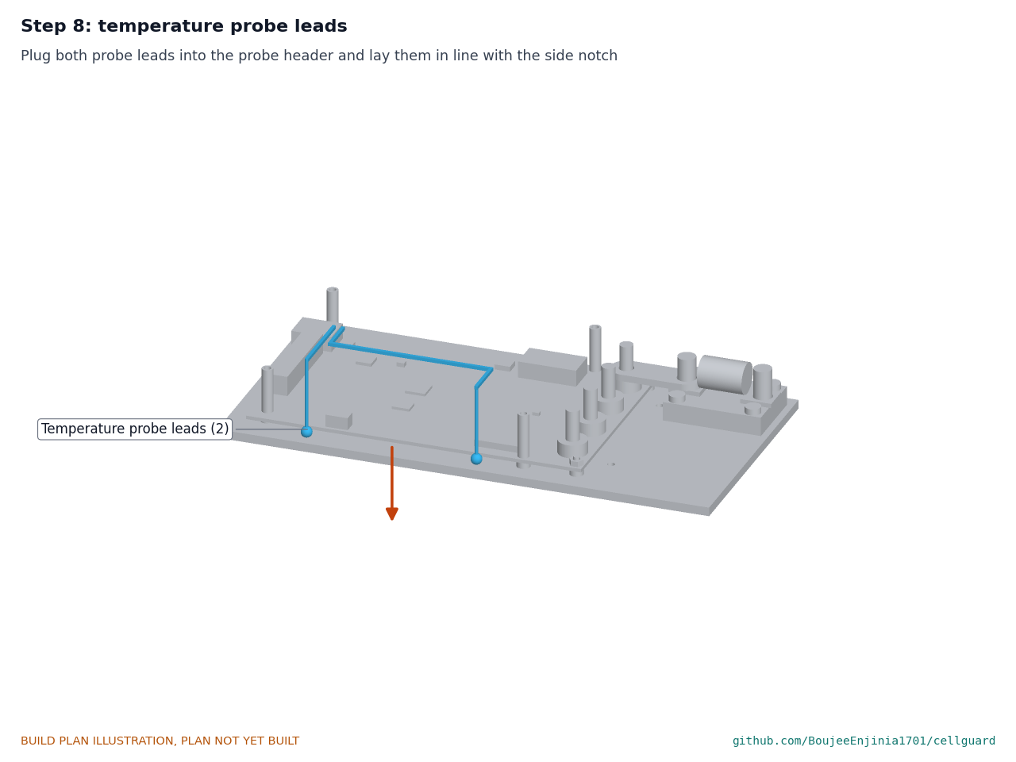
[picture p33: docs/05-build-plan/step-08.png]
Step 8


Plug both probe leads into the probe header and lay them along the board toward the side notch.

### Step 9: cover

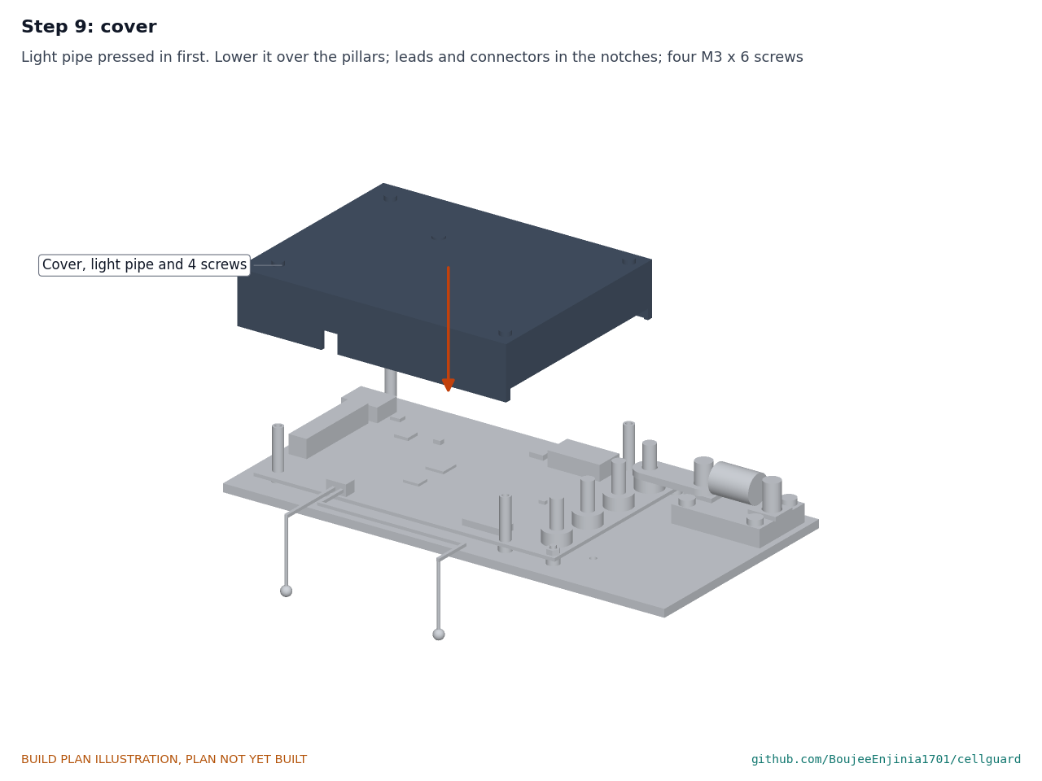
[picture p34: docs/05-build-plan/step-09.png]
Step 9


With the light pipe already pressed into the cover (section 3.5), lower the cover straight down over the pillars, with the probe leads in the side notch and the connectors in the signal-end notch. Fit four M3 x 6 pan-head screws into the pillars, hand tight. **Hold point:** the cover touches nothing but the pillar tops.

### Step 10: balance harness and CAN plug

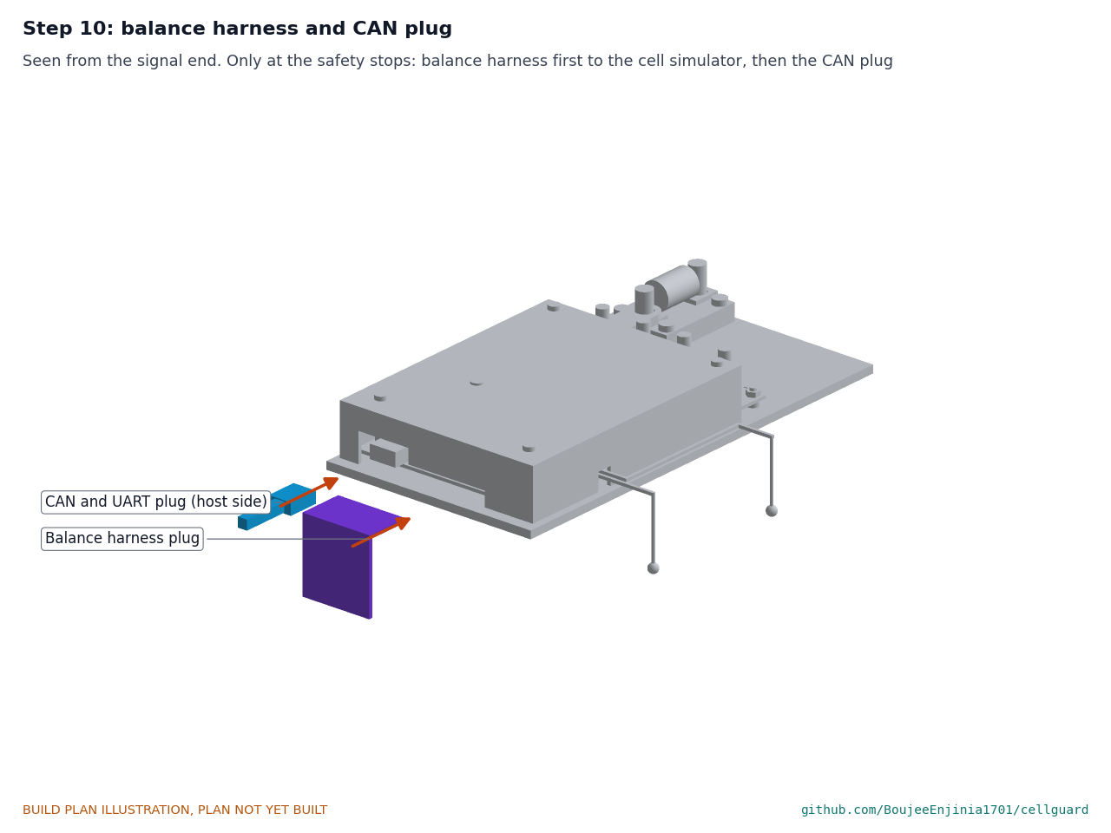
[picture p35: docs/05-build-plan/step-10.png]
Step 10


Seen from the signal end. Only at the safety stops of section 6, and in the order of Figure 15: first the balance harness plug, with the cell simulator connected to its far end, then the CAN and UART plug from the host.

## 5. First checks

These are the checks a TRL 4 test report would record; this plan only lists them. Requirement numbers are those of CGD-REQ-001. Use a cell simulator (or a string of current-limited bench supplies) until the pack checks at the end.

*Table 2. First checks.*

| Check | Requirement | How | Pass when |
| --- | --- | --- | --- |
| Switches touch the pad | R5 | After the first full tightening, take the board off once and look at the pad | All eight switches have left an even print on the pad; refit with a new pad |
| Insulation to the plate | R1 | Meter on its highest resistance range between the plate and each stud, board unpowered | No reading below 10 MΩ |
| Cover fit | R14 | Fit the cover; measure the assembly | Nothing touches the cover but the pillars; 220 x 110 x 33 mm or less |
| Cell voltage reading | R2 | Cell simulator at 3.30 V per cell; compare each reported cell with a calibrated meter | Within 10 mV at room temperature |
| Overvoltage and undervoltage trips | R3 | Raise one simulated cell slowly to 3.70 V, then lower one to 2.45 V | The charge switches open at 3.65 V and the discharge switches at 2.50 V, within the chip's stated accuracy |
| Secondary protector | R4 | With the protector fuse's heater output wired to an indicator in place of the fuse, raise one simulated cell past the protector's threshold with the main protection disabled | The protector output switches on |
| Current reading and calibration | R9 | Bench supply and electronic load at 20 A through a calibrated reference shunt; one-point gain calibration; repeat at 40 A | Within 1 % of reading plus 50 mA after calibration |
| Precharge | R13 | 2 mF capacitor bank on P+ and P-; enable the output from the host | The bank reaches 90 % of the input voltage within 1 s before the main switches close |
| Sleep and ship-mode current | R10 | Microammeter in the supply lead, output on, CAN in standby; then ship mode | 300 µA or less, then 10 µA or less |
| CAN and UART | R11 | USB-to-CAN adapter at 250 kbit/s; terminal at 115,200 baud | Status frames received; the output stays off until the enable line is pulled |
| Board loss and temperatures at 40 A | R5, R6 | Current-limited supply and electronic load at 40 A for 30 minutes, thermocouples on the plate and next to the hottest switch; measure the drop from B+ to P+ and from P- to B- | Plate rise near the calculated 10 K; switch case well under 110 °C; loss recorded against the 4 W target |
| Balancing temperature | R7 | Simulated cells 20 mV apart, balancing on, 40 °C room or hot box | A balance resistor stays at 70 °C or less |
| Mass | R14 | Weigh the assembly without power cables | Recorded against 0.7 kg (0.664 kg calculated; R14 relaxed on 2026-10-02) |

## 6. Safety stops

Stop at each point. Carry on only when everything listed is true.

- **S1. Before anything is connected.** The insulation check of section 5 passes. The fuse is out of its holder. Every stud has its nut and is covered with an insulating boot or tape.
- **S2. Before the first power-up.** The power source is a cell simulator or a current-limited bench supply, never a pack. Each balance lead voltage has been measured with a meter at the plug, from B- upward, before the plug goes in. The pack-side ends of the balance leads carry their fuses or resistors.
- **S3. Before the first real pack.** Every simulator check of section 5 passes. The short-circuit delay reads back as 15 µs. The fuse is the 60 A, 80 V DC, 10 kA part. Insulated tools only; no rings or watches. The pack is small (4S, 20 Ah or less) and sits on a non-combustible surface.
- **S4. Before the fuse goes in.** All cables are on and tight, B- connected first; the load is off and the host enable line is off.
- **S5. Before any high-current or charging test.** Attended the whole time, on a non-combustible surface, with a lithium-rated or Class D extinguisher and dry sand within reach. Plate temperature checked every 10 minutes. The charger has a fixed end-of-charge voltage set for the pack. Stop if the plate passes 70 °C or any cell passes 3.65 V.
- **S6. After any trip of the protector fuse, or any smell, smoke or swelling.** Disconnect the pack (fuse out first), let everything cool, and inspect the board before any repair.

## 7. Tools, skills and workspace

**Tools.** Hacksaw with a 24 teeth per inch blade (or a bandsaw); bench vice with soft jaws; bench drill; drills 3.3, 3.4, 6.5 and 8.5 mm; 90° countersink; M4 tap and wrench; flat files and a fine stone; scriber, engineer's square, steel rule, straight edge and calipers; sharp knife and cutting mat; heat gun; 3D printer with an enclosure and a bed of at least 140 x 110 mm that prints polycarbonate; hot plate for reflow, hot-air station and a fine-tip soldering iron with a large tip for the studs; solder paste, flux, braid and magnifier; torque screwdriver covering about 0.5 to 5 N·m and spanners for M3 to M8; multimeter with a high resistance range; microammeter; cell simulator (or several isolated current-limited bench supplies, 0 to 60 V); electronic load rated 60 V and 40 A or more; calibrated reference shunt; 2 mF capacitor bank rated 63 V or more; oscilloscope; USB-to-CAN adapter; thermocouple meter; scale to 2 kg.

**Skills.** No certified trade is needed. Basic metalwork (marking out, sawing, drilling, countersinking, tapping, filing); surface-mount soldering of 0.5 mm pitch chips with paste and a hot plate; safe work with lithium packs and bench supplies. All circuits are extra-low voltage: under 60 V DC at the studs. The bench supplies and loads must be certified, undamaged units; no mains wiring is part of this build.

**Workspace.** A bench about 1.2 x 0.6 m with an antistatic mat for the electronics, kept apart from the metalwork so chips stay off the board; fume extraction for soldering; a ventilated place for the printer; a separate battery test area on a non-combustible surface with the extinguisher and sand of S5.

**Personal protective equipment.** Safety glasses for cutting, drilling, soldering and all battery work; cut-resistant gloves for sheet edges; heat-resistant gloves near the hot plate; no gloves near a turning drill.

## 8. Where the numbers come from

- Model and constructability checks: `cad/src/model.py` (`python cad/src/model.py --check`, 55 checks); STEP and STL exports in `cad/step/` and `cad/stl/`.
- Pictures: `cad/src/build_plan_media.py`, using `.kit/build_views.py`; written to `docs/05-build-plan/` and `cad/drawings/CGD-DWG-101` to `CGD-DWG-105` (CGD-DWG-103 and CGD-DWG-104 at Rev P2).
- General arrangement: `cad/drawings/CGD-DWG-001.pdf`, Rev P3.
- Calculations: `docs/04-calcs/01-sizing.md` (CGD-CAL-001 v0.6) and `docs/04-calcs/sizing.py`: losses and temperatures (section 3), protection settings (section 4), mass (section 10), cost (section 11).
- Bill of materials: `bom/bom.csv`.
- Decisions: `docs/decisions/0003-design-for-construction.md` (CGD-DDR-003), with CGD-DDR-001, CGD-DDR-002 and the design decisions register `docs/06-design-decisions.md` (CGD-DEC-001).
- Requirements: `docs/03-requirements.md` (CGD-REQ-001 v0.8).

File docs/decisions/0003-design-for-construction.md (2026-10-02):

---
doc_id: CGD-DDR-003
title: CellGuard design for construction
project: CellGuard
doc_type: Design decision record
version: "0.3"
status: Draft
date: '2026-10-02'
author: Amish Chadha
license: CERN-OHL-S-2.0
revisions:
- version: "0.1"
  date: '2026-09-30'
  author: Amish Chadha
  change: Changes that make the concept physically buildable, with the reason for each; made under Amish's 2026-09-30 instruction to make the design physically buildable; open for his review
- version: "0.2"
  date: '2026-10-01'
  author: Amish Chadha
  change: Budget treated as a value-engineering target; cost wording only, no number changed
- version: "0.3"
  date: '2026-10-02'
  author: Amish Chadha
  change: "Accepted by Amish, including the recommendation for A1; A2 carried as a part to confirm"
---

# 0003: Design for construction

- **Date:** 2026-09-30
- **Status:** accepted. Amish, 2026-10-02: "i approve your recommendations for all 555 open decisions." This covers every change in Tables 1 and 2 and the recommendation for A1, which is now decided as recommended and recorded in the design decisions register (CGD-DEC-001). A2 is carried in the register as To confirm item 1. Nothing here changes what CellGuard does, its pitch or its safety case.

## Context

On 2026-09-30 Amish asked for every repo's build plan to show how each component is made and how it fits the next, and wrote: "If you are realising that the design cannot be built as per concept - fix the design assumptions to match and be physically feasible as you draw the illustrations." The TRL 3 model (CGD-DWG-001 Rev P1) showed the right parts in the right places, but several could not be made or fixed as drawn. Checking the model with build123d (overlaps, contacts, clearances and whether each part can reach its place in assembly order) found the eight problems in Table 1.

The changes keep the board's function, electrical design, size class and main interfaces: the same plate, board outline, MOSFET bank, stud positions and order, connectors, fuse rating and cover footprint. Every change is in `cad/src/model.py`, which now runs 46 constructability checks (`python cad/src/model.py --check`): no two parts overlap, 17 pairs of faces that must touch do touch, 14 clearances hold, the gap pad compression and link height match, and each of 12 assembly moves reaches its place without passing through a part already fitted. All 46 pass.

## Decision

*Table 1. Changes made to the model, the BOM and the calculations.*

| # | Problem in the concept | Change made | Why this way |
| --- | --- | --- | --- |
| P1 | The four board standoffs were drawn as part of the 4 mm plate, 2.8 mm tall. A flat sheet cannot carry them, and nothing held the board to them: the board had no holes and there were no screws. | The plate is flat. The board sits on six bought round aluminium spacers 3 mm tall and is held by six M3 countersunk screws put up through countersunk holes in the plate, so the plate's underside stays flat for mounting. | Bought spacers set the board height exactly; screws from below leave the top free for the pillars and nuts. |
| P2 | The gap between board and plate equalled the MOSFET height plus a 0.5 mm pad, with nothing to take up tolerance: a slightly short MOSFET would not touch the pad, a tall one would lift the board. | A 3.0 mm board-to-plate gap and a 1.0 mm gap pad squeezed to 0.7 mm (30 %) by the 2.3 mm MOSFETs. | A compressible gap pad takes up the tolerance of the MOSFET height and the spacers, so every MOSFET presses on it. Its thermal resistance rises by 40 %, which raises the hottest junction by 0.3 K (CGD-CAL-001 v0.3). |
| P3 | The cover had no fixing. Its connector window and probe lead exit were closed openings, so the cover could not be lowered over the CAN connector, harness or probe leads, which already pass through its walls. | The cover rests on four bought 20 mm M3 pillars that thread onto the board screws at the signal end and beside the precharge resistor and shunt, and is held by four M3 x 6 screws. The connector and probe openings become notches open at the bottom. The walls stand 0.5 mm clear of the plate, so only the pillars carry it. | Uses the board screws again, so no new holes in the plate. With the notches open at the bottom, the cover drops straight down over the connectors and leads. |
| P4 | The two board fixings at the power end, if given a nut or screw head on top, would hit the B+ stud shoulder and the SCP fuse. | They move to 71.5 mm right of centre and 43.5 mm each side, carrying a nyloc nut 2.2 mm clear of the stud and 1.3 mm clear of the SCP fuse. Two new fixings at 48 mm right of centre and 44 mm each side carry the cover's power-end pillars. | Six fixings hold the board at both ends and beside the MOSFET bank, and every head and nut has room. |
| P5 | The pack fuse holder sat on the plate with no fixing, on the centre line, and nothing joined it to the B+ stud: the fuse was a block at a different height from the stud, 33 mm to one side. | The fuse holder moves 33 mm to the B+ side, in line with the B+ stud, and is held by four M4 screws into tapped holes in the plate. A straight copper link, 14 x 3 mm and 41 mm long (new BOM line 18), joins the B+ stud's shoulder to the fuse blade at the holder's inner terminal, both 10.6 mm above the plate. The holder's base height is set so the two faces match. | A straight flat bar is easy to make, carries the full pack current with low resistance and keeps 7.5 mm from the P+ stud's ring lug. A cable with two lugs would not fit in the 27 mm between the studs. |
| P6 | The power studs were drawn as cylinders on the board with no stated way of fixing them. | Bought through-hole power terminals with an M6 male stud and a 13 mm shoulder 6 mm tall, soldered through the board, pins trimmed to 1 mm under the board, 2 mm above the plate. | A soldered terminal block is how a board this size carries 40 A; the shoulder is the face the ring lugs and the link clamp against. |
| P7 | The plate had no way of being fixed to a pack or a vehicle. | Four M4 tapped holes, 30 and 167 mm in from the signal end and 30 mm each side of the centre line; the mounting screws come up from below and stop inside the plate. | No head stands above the plate, so the holes can sit under the board. The hero picture's pack posts move to these holes. |
| P8 | The CAN and UART connector overhung the board edge by 9 mm and crossed the cover wall. | The connector moves so its mating face is flush with the cover's outside face: 5 mm past the board edge, 13 mm on the board, 1.5 mm clear of the pillar. | A right-angle connector this size is supported by its pins and board locks over 13 mm of board. |

*Table 2. Knock-on changes.*

| Item | Change | Reason |
| --- | --- | --- |
| BOM | Line 17 now lists the gap pad (1.0 mm), six spacers, four pillars, screws and nuts: $5.00 to $7.00. New line 18, copper fuse link, $2.00. Line 8 states the holder's footprint, fixing holes and terminal height; line 9 the stud terminal's shoulder. Total $138.00, 98.6 % of the $140 budget, $2.00 margin (was $134.00 and $6.00). | Parts added for construction. |
| Mass | 0.664 kg (was 0.646 kg): gap pad, spacers, pillars, screws and nuts 25 g, copper link 12 g. The fuse and holder stay at the concept figure of 89 g until the holder is chosen. R14 stays not met. A 3 mm plate would now give 0.599 kg. | Parts added for construction. |
| Thermal | Hottest junction 54.0 °C at 40 A (was 53.7 °C); 59.5 °C (TOLT) and 99.1 °C (TOLL) bounds at 80 A for 10 s (were 58.1 °C and 97.7 °C). Board loss unchanged at 4.44 W. R5 stays met, R6 stays not met. | Thicker pad (P2). |
| Size | Envelope 220 x 110 x 33 mm to the cover screw heads (was 32 mm). R14 size still met. | Pillars set the cover height (P3). |
| Drawings | CGD-DWG-001 Rev P2; making sketches CGD-DWG-101 to 105 added. | Follow the model. |
| Documents | CGD-CAL-001 v0.3, CGD-PRC-001 v0.5, CGD-REQ-001 v0.5, CGD-PRB-001 v0.5: figures above. No requirement changed status: 10 met on paper, 3 not met (R6, R8, R14), 3 at risk (R2, R4, R7). | Follow the model. |
| Appearance model | `cad/src/product_model.py` reads the new spacer positions; the photoreal renders made on Amish's Mac still show the concept plate and fuse position. | Renders are made on the Mac. |

*Table 3. Items proposed for Amish; A1 accepted by Amish as recommended on 2026-10-02.*

| # | Question | Options | Recommendation |
| --- | --- | --- | --- |
| A1 | Accept the changes P1 to P8. | (a) accept; (b) ask for changes. | (a). Accepted by Amish, 2026-10-02. |
| A2 | The estimated cost is $2.00 under the $140 value-engineering target after lines 17 and 18, and the SCP fuse, whose price is not confirmed, could use it up. | Confirm the SCP fuse price first; any overrun is reported as over the value-engineering target, a hypothetical control target, not a limit. | Confirm the SCP fuse price first. Carried as To confirm item 1 in CGD-DEC-001. |

## Consequences

- `design_state: constructable` in `project.yaml`. The build plan CGD-BLD-001 shows every component and step in pictures generated from the model (`cad/src/build_plan_media.py`).
- Open decisions are kept in the design decisions register CGD-DEC-001 (`docs/06-design-decisions.md`). With A1 accepted on 2026-10-02, the changes P1 to P8 stand as made.
- The copper layout of the board is TRL 4 work. It must keep the outline, fixing holes, stud positions and MOSFET positions on CGD-DWG-103.
- The photoreal renders (`media/render-*.png`), `media/card.png` and `media/social-preview.png` show the concept fuse position and plate; they need regenerating on Amish's Mac.

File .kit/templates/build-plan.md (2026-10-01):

---
doc_id: PRJ-BLD-001
title: Project prototype build plan
project: Project name
doc_type: Build plan
version: "0.1"
status: Draft
date: YYYY-MM-DD
author: Amish Chadha
license: CERN-OHL-S-2.0
revisions:
  - version: "0.1"
    date: YYYY-MM-DD
    author: Amish Chadha
    change: First build plan; design made constructable
---

# Project prototype build plan

**Plan, not yet built.** How to build the first proof-of-concept prototype, component by component. Building and testing to it is TRL 4 work. Decisions still to be made are kept in the design decisions register (`docs/06-design-decisions.md`), not here.

## 1. What you are building

Every component, pulled apart and numbered in build order

One short paragraph: what the prototype is, how many components, which are made and which are bought, and the main ways they are made.

## 2. What changed to make it buildable

| Component | The concept had | The buildable design has | Why |
| --- | --- | --- | --- |

## 3. Making the components

### 3.1 Component name

Making sketch

**What it is and what it is made from.**

**How to make it.**

1. Mark out ...
2. Cut ...

**How it fits the parts next to it.**

Close-up of the joint

**Check before moving on.**

## 4. Putting it together

### Step 1: ...

Step 1

## 5. First checks

| Check | Requirement | How | Pass when |
| --- | --- | --- | --- |

## 6. Safety stops

## 7. Tools, skills and workspace

## 8. Where the numbers come from

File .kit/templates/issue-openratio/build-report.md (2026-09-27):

---
name: Build report
about: Tell us what happened when you built, printed or tested part of this design
title: "Build report: "
labels: build-report
---

This is a research and educational prototype, not a medical device. It is a TRL 3 concept and is not released for fabrication. If you build any part of it, you do so at your own risk. Reports help everyone.

**What you built** (part, sub-assembly or test)

**Materials, tools and settings**

**What worked**

**What did not work, with photos or measurements if you have them**

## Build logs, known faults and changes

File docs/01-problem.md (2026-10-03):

---
doc_id: CGD-PRB-001
title: CellGuard problem statement
project: CellGuard
doc_type: Problem statement
version: "0.8"
status: Draft
date: '2026-10-02'
author: Amish Chadha
license: CERN-OHL-S-2.0
revisions:
- version: "0.1"
  date: '2026-09-25'
  author: Amish Chadha
  change: Initial scaffold
- version: "0.2"
  date: '2026-09-25'
  author: Amish Chadha
  change: Populate to TRL 2 (problem, users, context, constraints, prior work)
- version: "0.3"
  date: '2026-09-25'
  author: Amish Chadha
  change: TRL 3. Chemistry scope and current rating adopted for TRL 3 under Amish's 2026-09-25 instruction, open for his review (CGD-DDR-001); budget note
- version: "0.4"
  date: '2026-09-25'
  author: Amish Chadha
  change: Recommendations accepted by Amish (DDR-002)
- version: "0.5"
  date: '2026-09-30'
  author: Amish Chadha
  change: Design for construction (CGD-DDR-003); figures follow CGD-CAL-001 v0.3
- version: "0.6"
  date: '2026-10-01'
  author: Amish Chadha
  change: Budget treated as a value-engineering target; cost wording only, no number changed
- version: "0.7"
  date: '2026-10-02'
  author: Amish Chadha
  change: "First test partner as decided on 2026-10-02 (CGD-DEC-001)"
- version: "0.8"
  date: '2026-10-02'
  author: Amish Chadha
  change: "Constraints: cost estimate from CGD-CAL-001 v0.6 (USD 159.15 against the USD 140 value-engineering target)"
---

# CellGuard problem statement

Small builders of lithium iron phosphate (LiFePO4, LFP) packs have no open, documented battery management system (BMS) they can read, check and repair, so they either trust a closed board with unknown limits or leave the pack unprotected. Both routes end in damaged packs and, in the worst case, fires.

## The problem

A BMS keeps every cell of a pack inside its voltage, current and temperature limits, balances the cells so that the weakest one does not set the pack's capacity, and reports how much charge is left. It is the main safety layer of any lithium pack. The US Consumer Product Safety Commission's 2026 proposed safety standard for micromobility batteries puts it plainly: to keep each cell within its specifications during charge and discharge, "a robustly designed micromobility product electrical system uses a BMS" ([CPSC notice of proposed rulemaking, Federal Register, 24 June 2026](https://www.federalregister.gov/documents/2026/06/24/2026-12749/safety-standard-for-lithium-ion-batteries-used-in-micromobility-products-and-electrical-systems-of)).

The consequences of weak or missing protection are visible in fire statistics:

- The same CPSC notice counts 227 micromobility battery incidents from 2019 to 2023 in the United States, associated with 39 deaths and 181 injuries ([Federal Register](https://www.federalregister.gov/documents/2026/06/24/2026-12749/safety-standard-for-lithium-ion-batteries-used-in-micromobility-products-and-electrical-systems-of)).
- New York City recorded 268 lithium-ion battery fires and 18 deaths in 2023, and 277 fires and 6 deaths in 2024 ([FDNY, March 2025](https://www.nyc.gov/site/fdny/news/03-25/fdny-commissioner-robert-s-tucker-significant-progress-the-battle-against-lithium-ion)).
- London Fire Brigade attended 206 e-bike and e-scooter fires in 2025, a record, up from 171 in 2024 ([London Fire Brigade, January 2026](https://www.london-fire.gov.uk/news/2026-news/january/record-number-of-e-bike-and-e-scooter-fires-across-london-in-2025-as-brigade-calls-for-regulation-to-be-introdu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)).

Most of these fires involve lithium-ion chemistries other than LFP, and many involve poor chargers, damage or modified packs rather than a BMS fault alone. The point for this project is narrower: builders who make their own packs, which is common in the lab's vehicles, storage and field kits, need a protection board whose thresholds, firmware and failure behavior are published and testable.

What builders can buy today falls into three groups:

1. **Low-cost closed boards.** Widely sold 4S to 16S boards are cheap, but their firmware, thresholds, accuracy and failure modes are undocumented, and their state-of-charge figures cannot be checked.
2. **Open research platforms.** [foxBMS](https://foxbms.org/) from Fraunhofer IISB is open and aimed at functional safety, but it is a large, multi-board platform for vehicle-scale packs rather than a single garage-buildable board.
3. **Open small-pack projects.** [diyBMS](https://github.com/stuartpittaway/diyBMSv4) uses one small module per cell with a separate controller, and the [Libre Solar BMS 8S50 IC](https://libre.solar/hardware/bms-8s50-ic.html) covers 3 to 8 LFP cells with CAN and [open firmware](https://github.com/LibreSolar/bms-firmware). Neither covers 4 to 16 cells on one board with a documented state-of-charge method and a log that other lab projects can rely on.

LFP adds a specific difficulty: its open-circuit voltage is almost flat over most of the charge range, so the cell voltage says little about state of charge and simple voltage-based gauges mislead the user ([Applied Energy, 2025, on state-of-charge estimation in the LFP voltage plateau](https://www.sciencedirect.com/science/article/abs/pii/S0306261925014850)).

Regulation is moving toward the BMS as a source of record. The EU Batteries Regulation requires batteries for light means of transport, stationary storage and electric vehicles to hold data for determining state of health and expected lifetime in their BMS, applicable from 18 August 2024 ([Regulation (EU) 2023/1542](https://eur-lex.europa.eu/eli/reg/2023/1542/oj/eng); [summary, Crowell and Moring](https://www.crowell.com/en/insights/client-alerts/the-eu-batteries-regulation-taking-stock-of-the-new-eu-battery-requirements)). India amended its traction battery standard AIS-156 with added requirements on cells, the BMS and thermal propagation after fires in electric two-wheelers, effective 1 October 2022 ([Press Information Bureau, Government of India](https://www.pib.gov.in/PressReleaseIframePage.aspx?PRID=1856114&reg=3&lang=2)).

## Users and context

| User | Need | Context |
| --- | --- | --- |
| Lab projects (SwapCell, PowerBox, SunSpoke, MotionCore) | One protection layer with known limits and a documented interface, instead of a new BMS in each design | 12.8 to 51.2 V LFP packs, 20 to 280 Ah |
| Small pack builders and makers | A board they can build, configure for their cell count and check against a bench test | Garages, makerspaces, small workshops |
| Off-grid and backup storage users | A protected 12, 24 or 48 V battery bank whose state of charge they can trust | Solar home systems, clinics, shops, telecom sites |
| Repair shops and technicians | Readable fault codes, logs and thresholds so a pack can be diagnosed rather than scrapped | E-bike and solar repair |
| Educators and students | A complete, readable reference design for teaching battery safety | Vocational training, university labs |

Operating context assumed for the concept: LFP prismatic or cylindrical cells in 4S to 16S (12.8 to 51.2 V nominal, up to 58.4 V at 3.65 V per cell), continuous currents up to 40 A, ambient temperature from −20 to 50 °C (−4 to 122 °F), indoors or inside a vehicle or enclosure, not immersed.

## Constraints

- Garage-buildable prototype with a value-engineering target of about $140 USD in parts (`project.yaml`, a hypothetical control target, not a limit), excluding cells, raised from $120 by Amish on 2026-09-25 (CGD-DDR-002). CGD-CAL-001 v0.6 estimates the board at $159.15, $19.15 over the target, with the secondary protector, the parts added to make it buildable (CGD-DDR-003) and the 1.5 mΩ-class switches, status light and light pipe decided on 2026-10-02.
- One board design covers 4 to 16 series cells, set by configuration, not by different boards.
- Parts that a small workshop can solder: no ball grid arrays, no leadless packages finer than 0.5 mm pitch, assembly with a hot plate or hot-air station.
- Maximum pack voltage below 60 V DC, so the design stays in the extra-low-voltage range.
- Open hardware (CERN-OHL-S-2.0) and open firmware (MIT); every threshold readable and changeable in a plain configuration file.
- Research, educational and prototype use. CellGuard is not a certified BMS and does not replace a certified one where a product must meet a standard such as UL 2271 or AIS-156.

## Out of scope

- Firmware for chemistries other than LFP in the first release. The hardware also supports an NMC profile of up to 14 cells, so it could serve as SwapCell's 13S BMS (decided by Amish, 2026-09-25, subject to the SwapCell project).
- Single-cell and 2S to 3S packs, such as FieldNode's single LFP cell, which need a simpler one-cell protector.
- Packs above 16S or above 60 V, and currents above 40 A continuous.
- Active (energy-transferring) balancing.
- Certification testing.

## Open questions

- NMC profile for SwapCell's 13S pack: decided by Amish, 2026-09-25: go with recommendation (hardware for both, LFP firmware first). The SwapCell project's agreement is still needed.
- Current rating: 40 A continuous, decided by Amish, 2026-09-25: go with recommendation; a 100 A variant only if storage users need it.
- Which partner should supply real packs and use cases for first testing? Decided by Amish, 2026-10-02 (CGD-DEC-001): a small off-grid solar installer that builds 16S LFP packs, testing on their bench rather than in a customer system, is the first candidate to approach.

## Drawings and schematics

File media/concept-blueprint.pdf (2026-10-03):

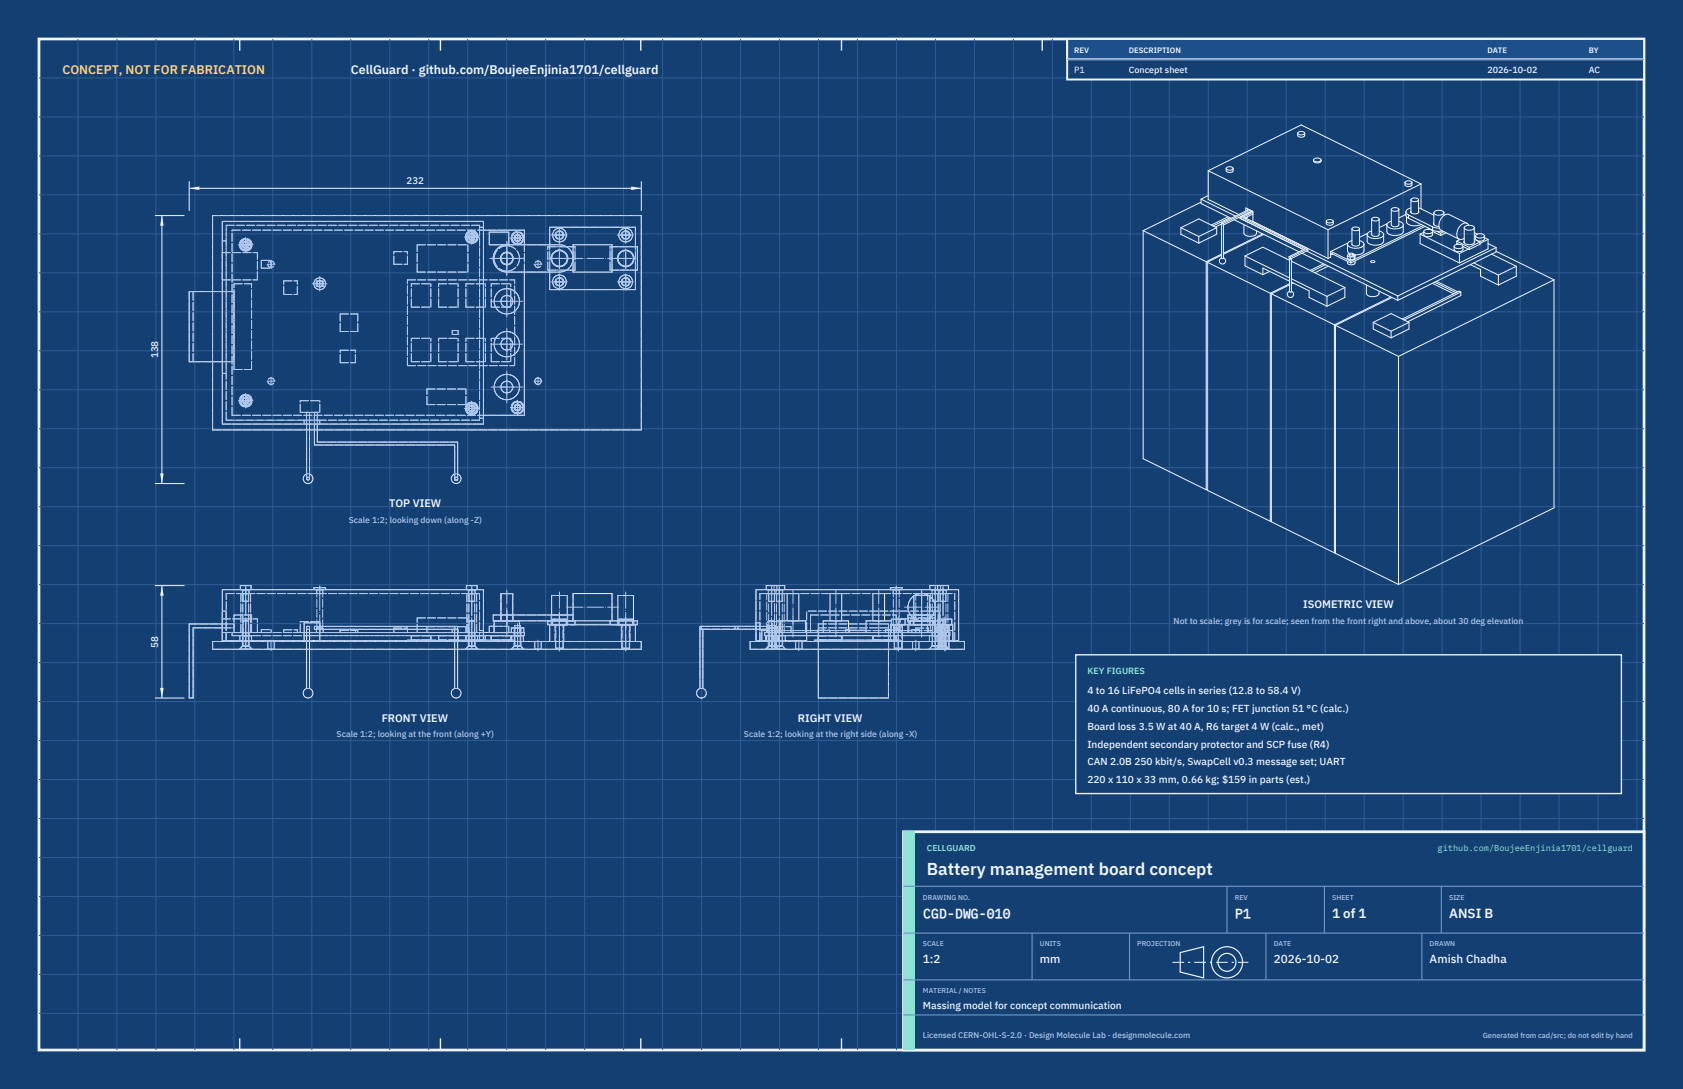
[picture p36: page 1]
CONCEPT, NOT FOR FABRICATION; CellGuard · github.com/BoujeeEnjinia1701/cellguard; FRONT VIEW; TOP VIEW; RIGHT VIEW; ISOMETRIC VIEW; REV; DESCRIPTION; DATE; Concept sheet; CELLGUARD; github.com/BoujeeEnjinia1701/cellguard; DRAWING NO. CGD-DWG-010; REV P1; SHEET 1 of 1; SIZE ANSI B; SCALE 1:2; UNITS mm; PROJECTION; DRAWN Amish Chadha; Licensed CERN-OHL-S-2.0 · Design Molecule Lab · designmolecule.com; Generated from cad/src; do not edit by hand

Scale 1:2; looking down (along -Z)

Not to scale; grey is for scale; seen from the front right and above, about 30 deg elevation

KEY FIGURES
4 to 16 LiFePO4 cells in series (12.8 to 58.4 V)
40 A continuous, 80 A for 10 s; FET junction 51 °C (calc.)
Board loss 3.5 W at 40 A, R6 target 4 W (calc., met)
Independent secondary protector and SCP fuse (R4)
CAN 2.0B 250 kbit/s, SwapCell v0.3 message set; UART
220 x 110 x 33 mm, 0.66 kg; $159 in parts (est.)

Scale 1:2; looking at the front (along +Y)

Scale 1:2; looking at the right side (along -X)

Battery management board concept

MATERIAL / NOTES
Massing model for concept communication

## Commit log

2026-09-25 Initial scaffold: standard open hardware layout, CERN-OHL-S v2 + MIT licenses
    Claude-Session: https://claude.ai/code/session_01XuhhSU4W6fYhgCfURbrkut
    [bom.csv]
2026-09-25 Populate to TRL 2: problem, requirements, precis, concept media, BOM and README use cases
    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
    [bom.csv]
2026-09-26 Advance to TRL 3: DDR-001, CAL-001 sizing, parametric model with STEP/STL, GA drawing, priced BOM; TRL 4 on hold
    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
    [bom.csv, cellguard-assembly.step, cellguard-assembly.stl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]
2026-09-26 Accept all recommendations (DDR-002), switch footer to designmolecule.com, add README write-up with new inspiration point
    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
    [bom.csv, cellguard-assembly.step, cellguard-base-plate.step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]
2026-09-27 Product appearance model and photoreal renders
    Adds cad/src/product_model.py (appearance model for renders only, all main
    dimensions from model.py) and Blender renders in media/render-*.png,
    captioned with the project, repository and viewing direction. README leads
    with the product render; trl stays 3.
    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
2026-10-01 Image quality pass: legible exploded views, flow diagrams and drawing sheets
    Kit 1.6.1 image layout: the parts list sits in its own column, number bubbles sit on visible parts and never overlap, small parts get a leader, pictures are cropped to the subject, flow labels keep numbers with their units, and sheet captions and the revision table no longer overprint. Concept images, blueprint and general arrangement sheet regenerated; repo-specific labels moved clear of other text and lines.
2026-10-01 Kit 1.7.0: constructable design, illustrated build plan and design decisions register
    The design is now constructable: every part can be made and fits its neighbours, with each change recorded in a Design for construction decision record (made under Amish's 2026-09-30 instruction; ope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
    [bom.csv, cellguard-assembly.step, cellguard-assembly.stl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]
2026-10-01 Budget treated as a value-engineering target
    Amish, 2026-10-01: the budget is a hypothetical control target that keeps the design on a value-engineering lens, not a spending limit. Documents now state the value-engineering target and the estima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
2026-10-02 Record Amish's approval of the open-decision recommendations
    Amish approved the recommendation on every open decision in the design decisions register ("i approve your recommendations for all 555 open decisions.", 2026-10-02). Each decision is moved to Decisio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
2026-10-03 Carry approved follow-ups into the design and redo photoreal renders
    Amish approved the follow-up actions from the open-decision sign-off ("APPROVED CHANGES, COMPLETE THESE", 2026-10-02), the design-for-construction change tables in ten repos, the last wave's open dec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
    [bom.csv, cellguard-assembly.step, cellguard-assembly.stl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]
